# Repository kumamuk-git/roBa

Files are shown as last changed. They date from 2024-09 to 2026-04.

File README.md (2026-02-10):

# roBa
roBaは[keyball](https://github.com/Yowkees/keyball/)に影響を受けたワイヤレスキーボードです  

特徴:
+ ZMK firmwareによるbluetooth(BLE)対応
+ 分割カラムスタッガード配列(キー数:42)
+ トラックボール搭載
+ 水平ロータリーエンコーダ搭載（v1: evqwgd001, v2以降: [CKW12](https://github.com/kumamuk-git/CKW12/tree/main)）

## Where to Buy

[BOOTH](https://kumamuk.booth.pm/)にて組み立てキットが購入可能

## Build Guide

ビルドガイドは[こちら](https://github.com/kumamuk-git/roBa/blob/main/doc/v3/buildguide_v3.md)

## Firmware

ファームウェアのリポジトリは[こちら](https://github.com/kumamuk-git/zmk-config-roBa)  
デフォルトでは以下のように設定されています
+ オートマウスレイヤー：4
+ スクロールレイヤー：5  
+ CPI：400

ファームウェア、キーマップの編集手順は[こちら](https://github.com/kumamuk-git/roBa/blob/main/doc/v3/buildguide_v3.md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)  
（ZMK STUDIOでもキーマップ編集可能）

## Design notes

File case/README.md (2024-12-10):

trackballcase.stl was Created by modifying [Keyball Trackball Case](https://www.thingiverse.com/thing:6215791) (© [kepeo](https://www.thingiverse.com/kepeo/designs) ([Licensed under CC BY 4.0](https://creativecommons.org/licenses/by/4.0/)）)

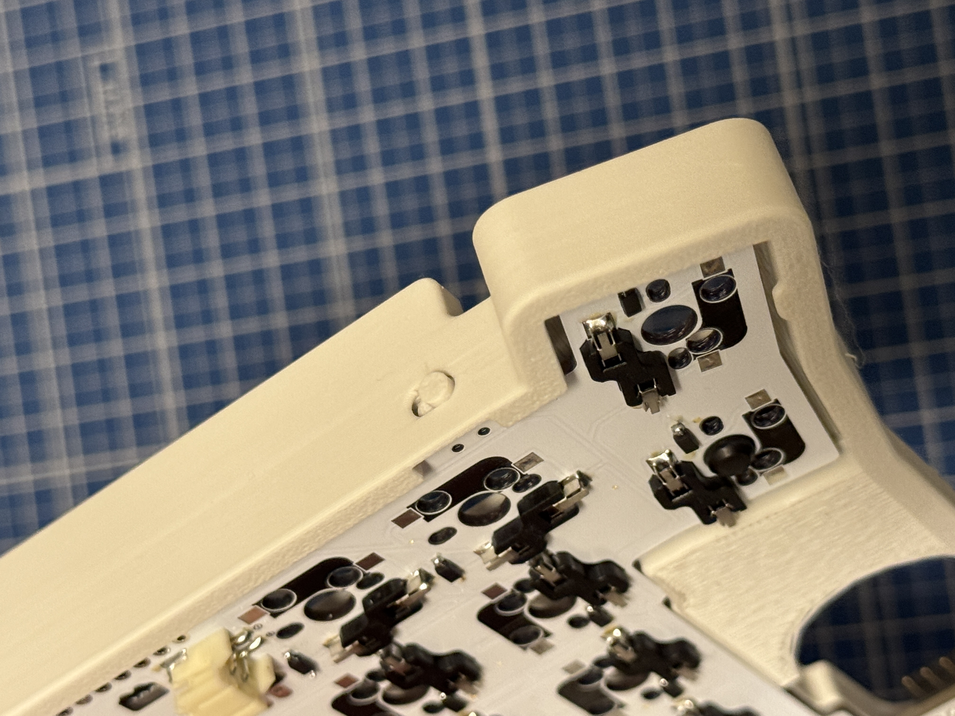
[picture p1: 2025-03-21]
doc/img/cover_v3_2.JPG

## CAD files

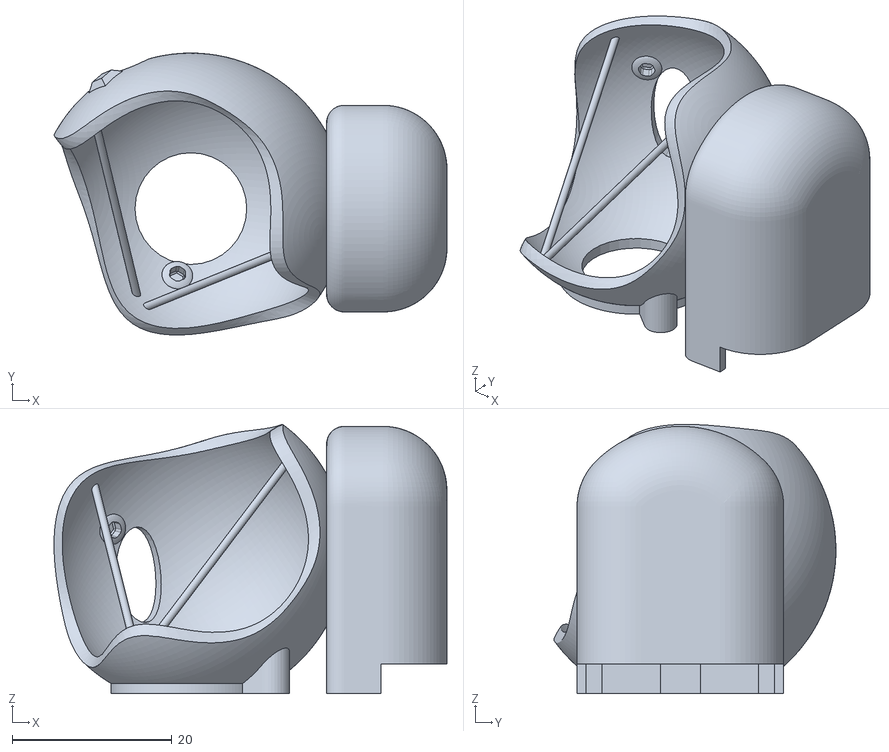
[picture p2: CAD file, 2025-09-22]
case/trackballcase_JLC3DP.stl
49.3 x 35.3 x 33.7

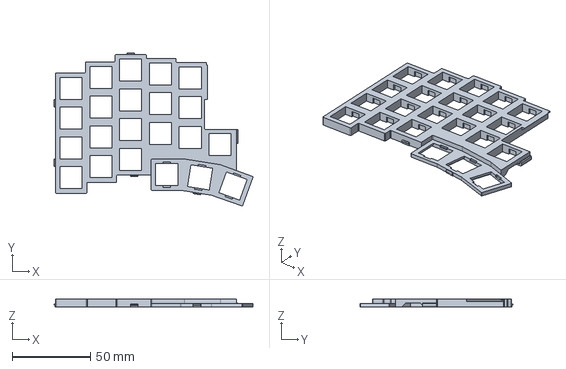
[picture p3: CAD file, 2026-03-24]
case/v3.1/top_L_plate.stp
127.4 x 97.8 x 5.00 mm

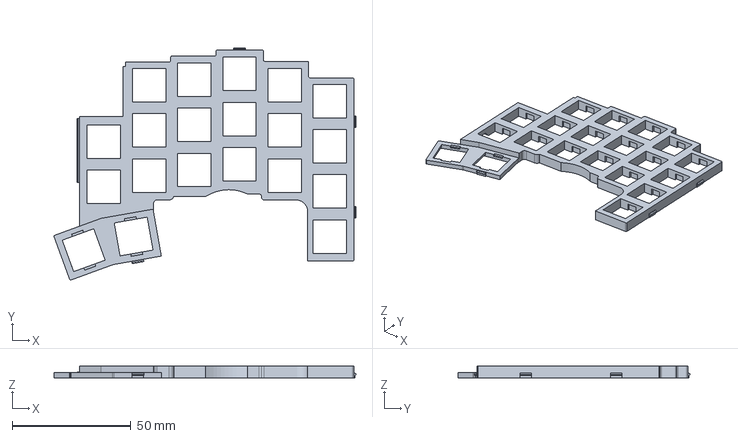
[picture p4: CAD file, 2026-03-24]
case/v3.1/top_R_plate.stp
127.3 x 97.8 x 5.00 mm

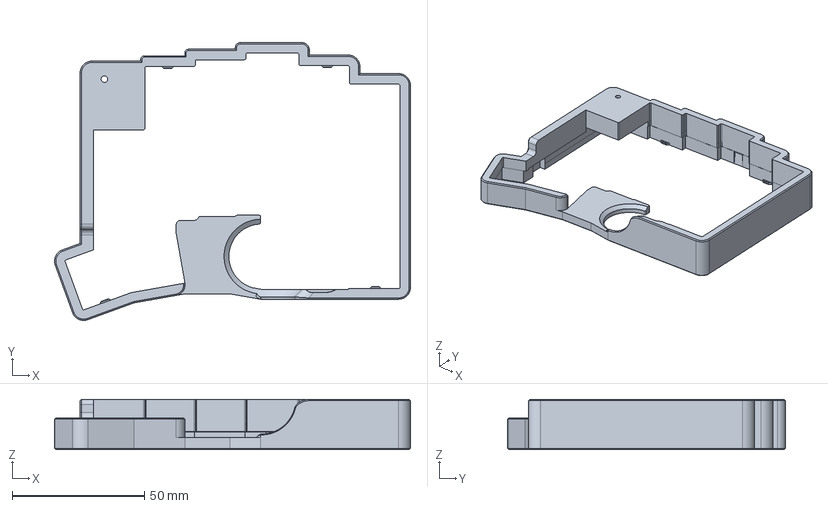
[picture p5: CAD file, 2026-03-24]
case/v3.1/top_R_frame.stp
134.4 x 104.9 x 19.0 mm

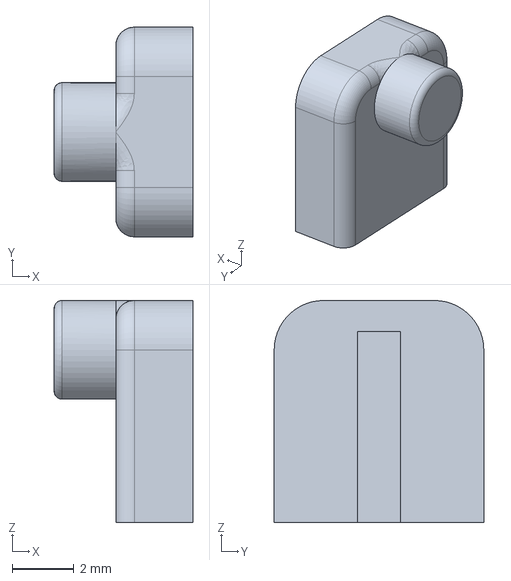
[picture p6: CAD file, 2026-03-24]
case/v3.1/power_sw_fix.stp
4.50 x 6.80 x 7.20 mm

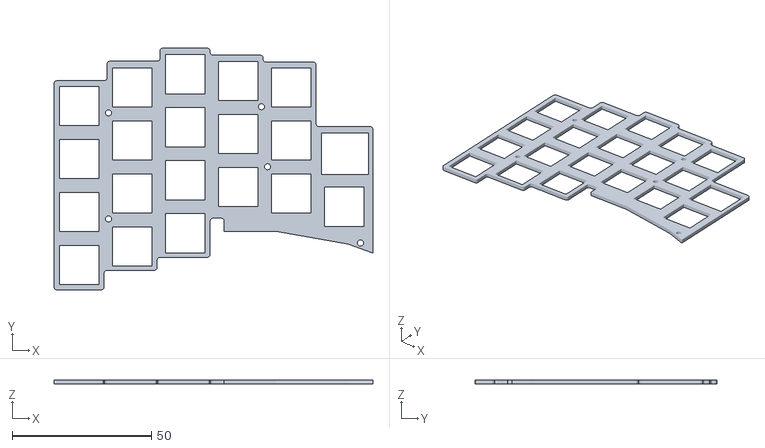
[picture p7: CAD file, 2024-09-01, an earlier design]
case/_old/top_L_main.stl
114.7 x 86.9 x 1.60

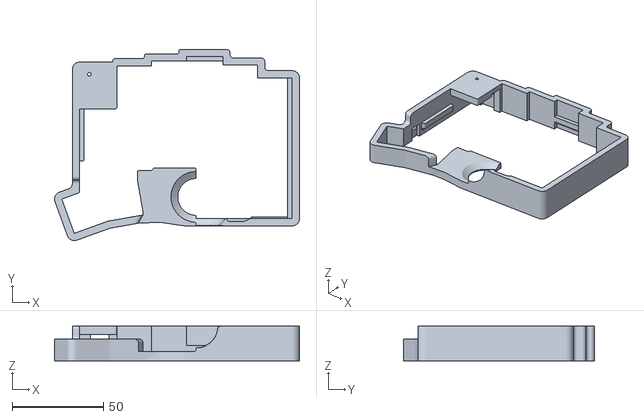
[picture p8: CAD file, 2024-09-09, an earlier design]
case/v1/roba_case_main_R.stl
134.5 x 105.0 x 19.1

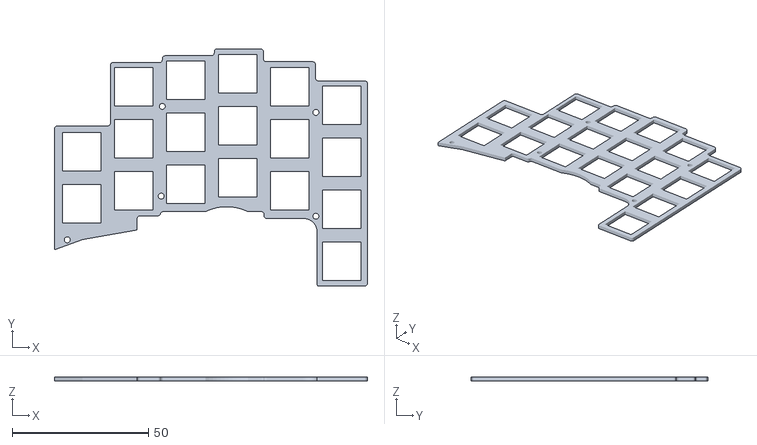
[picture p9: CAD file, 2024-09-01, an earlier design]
case/_old/top_R_main.stl
114.7 x 86.9 x 1.60

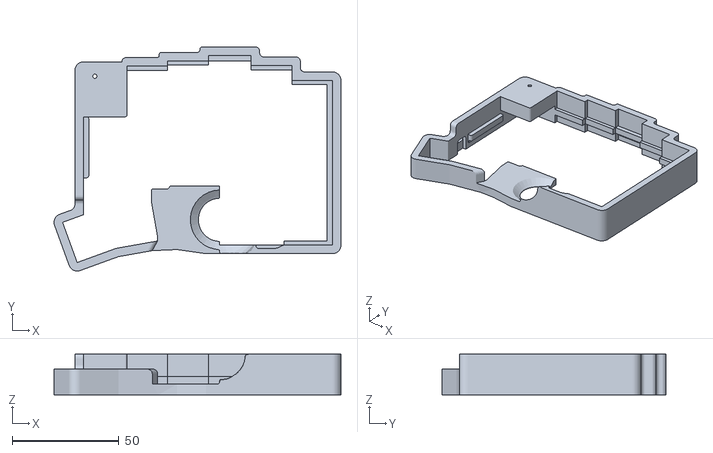
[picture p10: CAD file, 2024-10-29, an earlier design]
case/v2/main_R_v2.stl
134.5 x 105.0 x 19.1

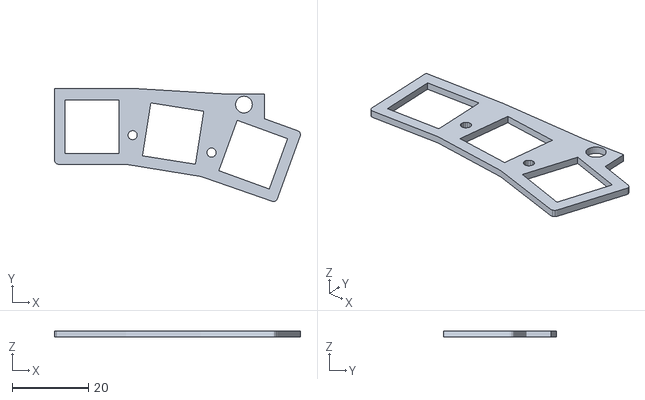
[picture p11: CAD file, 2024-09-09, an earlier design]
case/v1/roba_case_top_thumb_L.stl
64.7 x 29.7 x 1.58

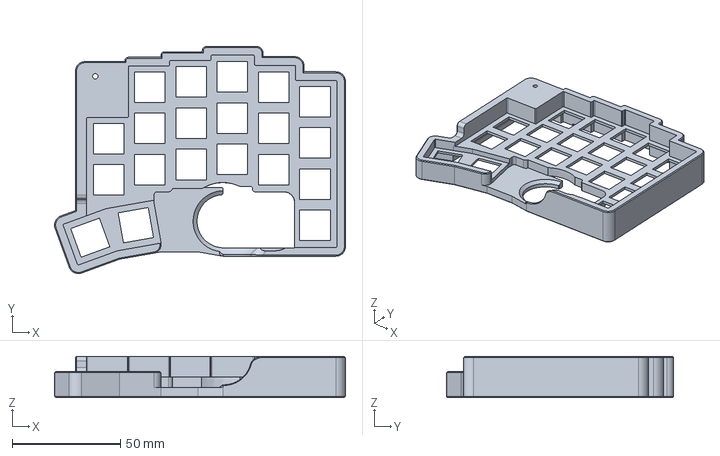
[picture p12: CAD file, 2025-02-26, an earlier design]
case/v2.1/top_R.stp
134.4 x 104.9 x 19.0 mm

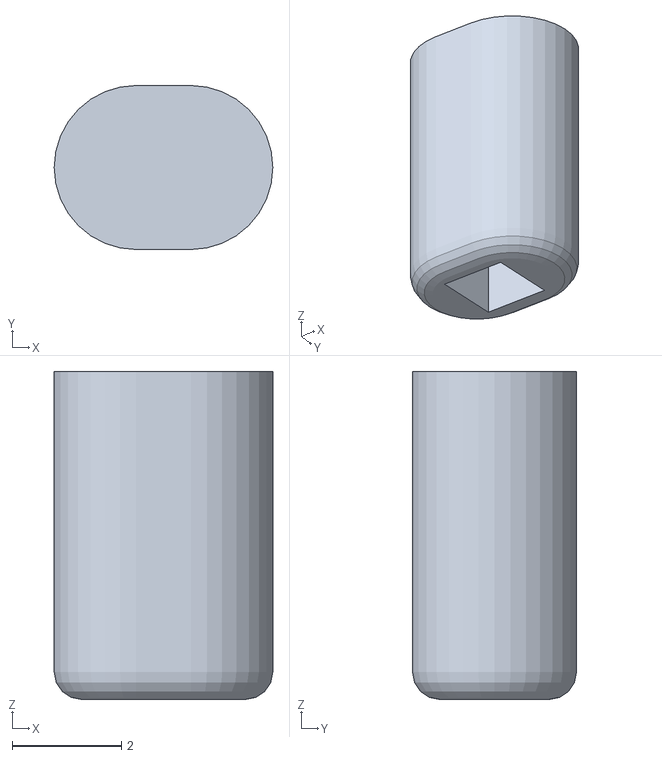
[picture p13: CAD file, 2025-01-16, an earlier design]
case/v2/power_sw_wide.stl
4.00 x 3.00 x 6.00

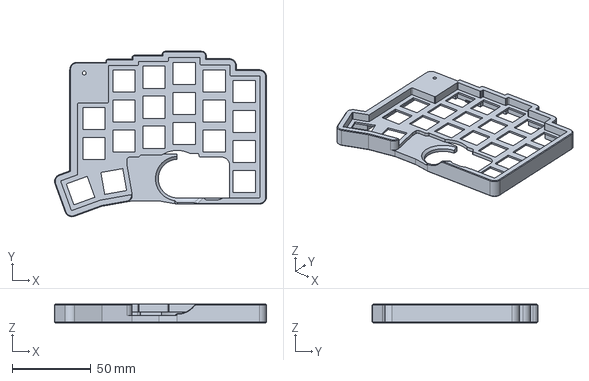
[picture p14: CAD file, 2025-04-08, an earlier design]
case/v3/forLP/top_R_LP.stp
134.4 x 104.9 x 12.0 mm

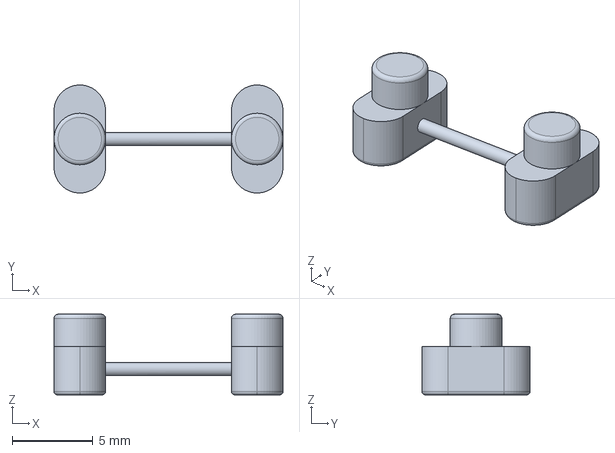
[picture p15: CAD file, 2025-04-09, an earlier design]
case/v3/power_sw_JLC3DP.stp
14.2 x 6.70 x 5.00 mm

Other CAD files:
case/trackballcase.stl
case/v3.1/top_L_frame.stp
case/v2/main_l_v2.stl
case/v1/roba_case_main_L.stl
case/_old/my_case_L_bottom.stl
case/_old/my_case_L_v5.stl
case/_old/my_case_R_bottom_v3.stl
case/_old/my_case_R_v9.stl
case/_old/power_switch.stl
case/_old/reset_stick.stl
case/_old/top_L_sum.stl
case/_old/top_R_sum.stl
case/v1/power_sw.stl
case/v1/reset_stick.stl
case/v1/roba_case_bottom_L.stl
case/v1/roba_case_bottom_R.stl
case/v1/roba_case_top_L.stl
case/v1/roba_case_top_thumb_R.stl
case/v2.1/bottom_R.stp
case/v2.1/botttom_L.stp
case/v2.1/power_sw.stp
case/v2.1/top_L.stp
case/v2/bottom_L_v2.stl
case/v2/bottom_R_v2.stl
case/v2/power_sw.stl
case/v2/reset_stick_v2.stl
case/v2/roba_case_top_thumb_R.stl
case/v2/top_L_v2.stl
case/v2/top_R.stl
case/v3/bottom_L.stp
case/v3/bottom_R.stp
case/v3/forLP/reset_stick_LP.stp
case/v3/forLP/reset_stick_LP_JLC3DP.stp
case/v3/forLP/top_L_LP.stp
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

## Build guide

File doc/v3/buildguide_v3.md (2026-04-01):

# Build Guide for roBa

2025/3販売分～

## 目次
  - [1．部品確認](#1部品確認)
    - [1-1．キット内容](#1-1キット内容)
    - [1-2．別途準備が必要な部品](#1-2別途準備が必要な部品)
    - [1-3．オプション](#1-3オプション)
  - [2．準備](#2準備)
    - [2-1．必要な工具](#2-1必要な工具)
    - [2-2．ファームウェア](#2-2ファームウェア)
  - [3．実装](#3実装)
    - [3-1．ダイオードのはんだ付け](#3-1ダイオードのはんだ付け)
    - [3-2．キーソケットのはんだ付け](#3-2キーソケットのはんだ付け)
    - [3-3．スライドスイッチのはんだ付け](#3-3スライドスイッチのはんだ付け)
    - [3-4．マイコンのはんだ付け](#3-4マイコンのはんだ付け)
    - [3-5．コネクタのはんだ付け](#3-5コネクタのはんだ付け)
    - [3-6．L字コンスルーのはんだ付け](#3-6l字コンスルーのはんだ付け)  
    - [3-7．センサのはんだ付け](#3-7センサのはんだ付け)
    - [3-8．ロータリーエンコーダの組み立て](#3-8ロータリーエンコーダの組み立て)
  - [4．組み立て](#4組み立て)
    - [4-1．バッテリーの確認及び取り付け](#4-1バッテリーの確認及び取り付け)
    - [4-2．ケースの組み立て](#4-2ケースの組み立て)
    - [4-3．トラックボール読み取り基板差し込み](#4-3トラックボール読み取り基板差し込み)
    - [4-4．トラックボールケース装着](#4-4トラックボールケース装着)  
  - [5．ファームウェア書込み](#5ファームウェアの書込み)
    - [5-1．ファームウェア(仮)のダウンロード](#5-1ファームウェア仮のダウンロード)
    - [5-2．ファームウェア(仮)の書込み](#5-2ファームウェア仮の書込み)
    - [5-3．動作確認](#5-3動作確認)
  - [6．キーマップの編集](#6キーマップの編集)
  - [7．トラブルシューティング](#7トラブルシューティング)

## 1．部品確認

### 1-1．キット内容

> [!NOTE]  
> **ケースなし版を購入された方へ**  
> 3Dプリントケースは[github](https://github.com/kumamuk-git/roBa/tree/main/case/v3)上で公開しています
> JLCPCBでの発注方法は[こちら](https://zenn.dev/kumamuk/scraps/ff2f456fd1757d)に簡単にまとめています  
> 部品の厚みが足りないと警告が出る場合がありますが、リスクを許容すると回答することで製造を進めることができます

| 名前 | 数 | 備考 |
|:-|---:|:-|
| メイン基板(左右) | 1組 | |
| ボトムプレート(左右) | 1組 | 3Dプリント品|
| ケース(左右) | 1組 | 3Dプリント品|
| リセットボタン用スティック | 2本 | 3Dプリント品|
| 電源スイッチキャップ | 2本 | 3Dプリント品|
| トラックボールケース | 1個 | 3Dプリント品|
| Φ2 セラミックボール | 3個 | トラックボールケースに取り付け済み |
| トラックボール読取り基板 | 1枚 | |
| トラックボール読取りセンサ | 1個 | PMW3610|
| 読取りセンサ用レンズ | 1個 | |
| L字コンスルーピン(7ピン) | 1個 | |
| PHコネクタ | 2個 | [S2B-PH-SM4-TB](https://akizukidenshi.com/catalog/g/g112810/)|
| スライドスイッチ | 2個 |[MSK12C01](https://www.aitendo.com/product/16631) |
| ダイオード（表面実装タイプ）  | 50個 | 予備含む|
| Kailh PCBソケット CherryMX用  | 40個 ||
| Kailh PCBソケット choc用 | 5個 | |
| ネジ M1.7 | 2本 | |
| クッションゴム | 4個 | |  

---ロータリーエンコーダ---
| 名前 | 数 | 備考 |
|:-|---:|:-|
| ロータリーエンコーダ用ハウジング | 1個 | 3Dプリント品|
| ロータリーエンコーダ用ホイール | 1個 | 3Dプリント品|
| ロータリーエンコーダ用ステム | 1個 | 3Dプリント品|
| ロータリーエンコーダ | 1個 | EC05E1220202|
| ロータリーエンコーダ基板 | 1個 | |
| スペーサー M2 3mm | 4本 | |
| ネジ M2 8mm | 4本 |  |
| スプリングピン(ポゴピン) | 1本 | |
| コンスルーピン(3ピン) | 2個 |うち1つは中央のピンが不必要のため取り外しています |

### 1-2．別途準備が必要な部品

| 名前 | 数 | 備考 |参考情報|
|:-|-:|:-|:-|
| Xiao nrf52840 | 2個 |  |[主な購入先](https://akizukidenshi.com/catalog/g/g117341/)|
| CherryMX互換キースイッチ | 37個  |  |
| ロープロファイルキースイッチ  | 5個 |  |
| 直径34mmトラックボール | 1個 |  |[主な購入先](https://www.amazon.co.jp/%E3%81%BA%E3%83%AA%E3%83%83%E3%82%AF%E3%82%B9-PERIPRO-303WH-%E4%BA%A4%E6%8F%9B%E7%94%A8%E3%83%88%E3%83%A9%E3%83%83%E3%82%AF%E3%83%9C%E3%83%B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)|
| Lipoバッテリー(コネクタ付き)  | 2個 | ボトムプレートはL53mm × W23mm × H6mm 以内の大きさに対応 キット付属のコネクタは2mmピッチのJSTコネクタになります。必ず保護回路付きのものを用意してください。|[主な購入先](https://www.amazon.co.jp/dp/B09DPNZM31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)|
| USB type-Cケーブル | 1本 | ファームウェア書込みと充電に必要 |
| キーキャップ | 37個  | 1u 37個 |
| ロープロファイルキーキャップ  | 5個 | 1u ５個 |
| 両面テープ | - | ボトムプレートへのバッテリーの固定に必要|

※リポバッテリーには発火等の危険性があります。各自購入したバッテリーの注意事項をよく読み、適切に取り扱うよう注意してください。  
　取り扱いの不備により発生した事故等の責任は負いかねます。  
※主な購入先のリンクはアフェリエイトリンクではありません。

### 1-3．オプション
+ ロータリーエンコーダ部分にキーソケットを取り付けキースイッチを取り付けることも可能です。

## 2．準備

### 2-1．必要な工具
| 名前 | 備考 |
|:-|:-|
| はんだごて  | 温度調整可能だと◎|
| はんだ | |
| ピンセット  | |
| ドライバ ||
| マスキングテープ||
| テスター||
| ペンチ||

※はんだ付けに不慣れな場合は[こちらの練習基板](https://shop.talpkeyboard.com/products/xiao-practice-board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)でマイコンのはんだ付けを練習してから挑むと良いかと思います。

### 2-2．ファームウェア
Xiao nrf52840へファームウェアの書込みが必要です。  
ビルド済みのファームウェアは[こちら](https://github.com/kumamuk-git/zmk-config-roBa/actions/runs/10759328125)です。  
zmk firmwareを使用しているため、ご自身でファームウェアやキーマップをカスタムされる場合はgithubアカウントが必要になります。  

## 3．実装

### 3-1．ダイオードのはんだ付け
ダイオードは基板裏面（roBaロゴがない面）に実装します。ダイオードは実装の向きがあります。  
ダイオードに薄く書かれている線と基板に印刷された図（以降シルク）にある線が同じ方向になるように取り付けて下さい。  

ダイオード用パッドの片側にはんだを盛ります。  

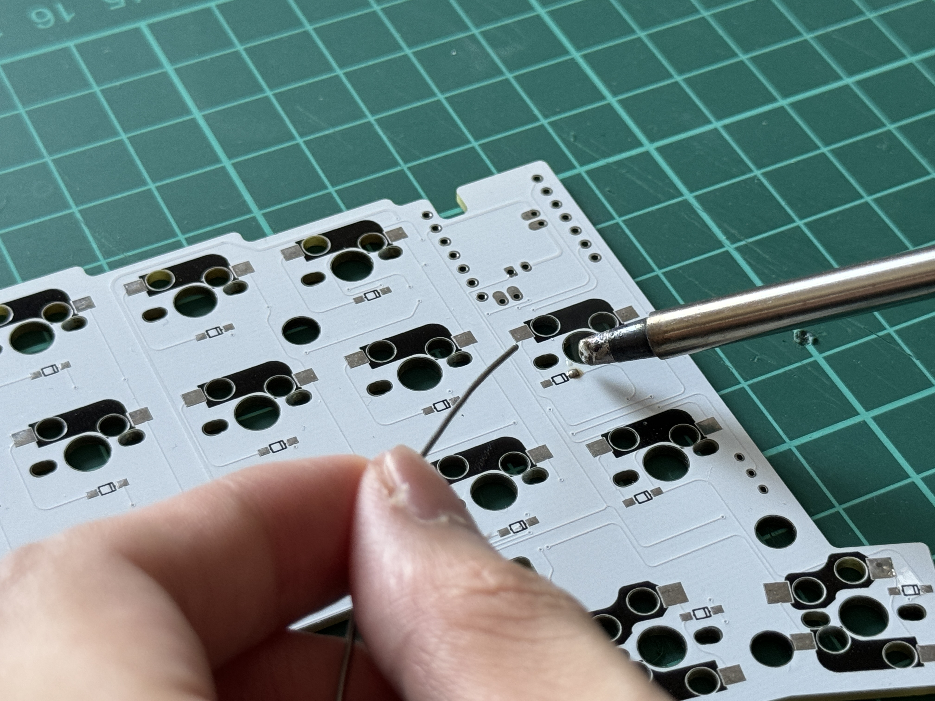
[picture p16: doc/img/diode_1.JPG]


そしてピンセットでダイオードを掴み、シルクと向きを合わせて事前に盛ったはんだを溶かしつつ位置を合わせます。 

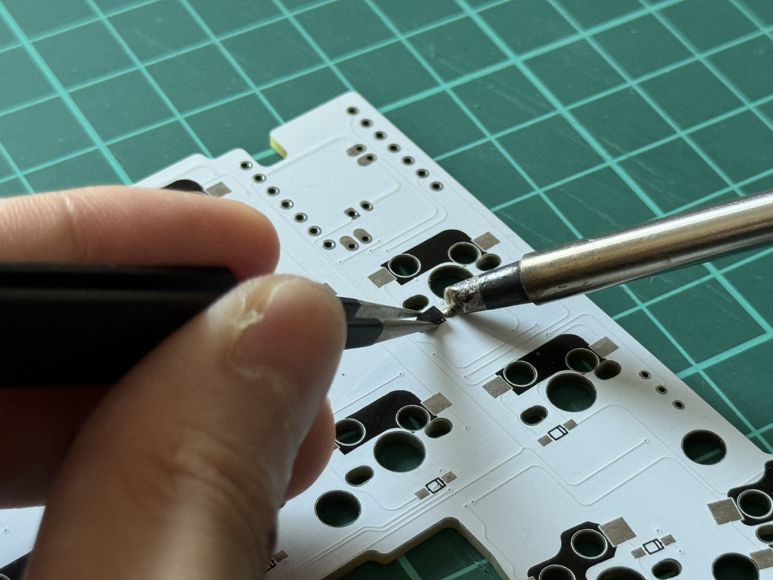
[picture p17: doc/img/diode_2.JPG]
 

およそシルクと同じ位置に決まったら、もう片側もはんだで固定します。

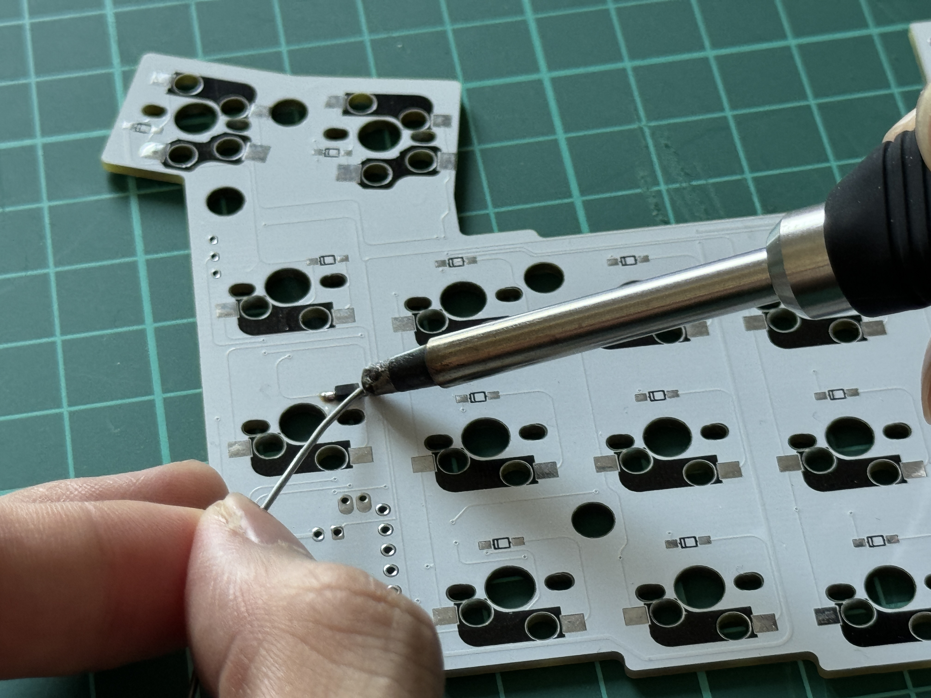
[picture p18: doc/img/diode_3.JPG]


ピンセットでダイオードが取れないことを確認したら取り付け完了です。  
これをすべて(43箇所)に対して行います。

### 3-2．キーソケットのはんだ付け  
キーソケットも基板裏面に実装します。  
親指部分はchoc用のキーソケットを使用してください。  
ダイオードと同様に片方のパッドに事前にはんだを盛ります。  

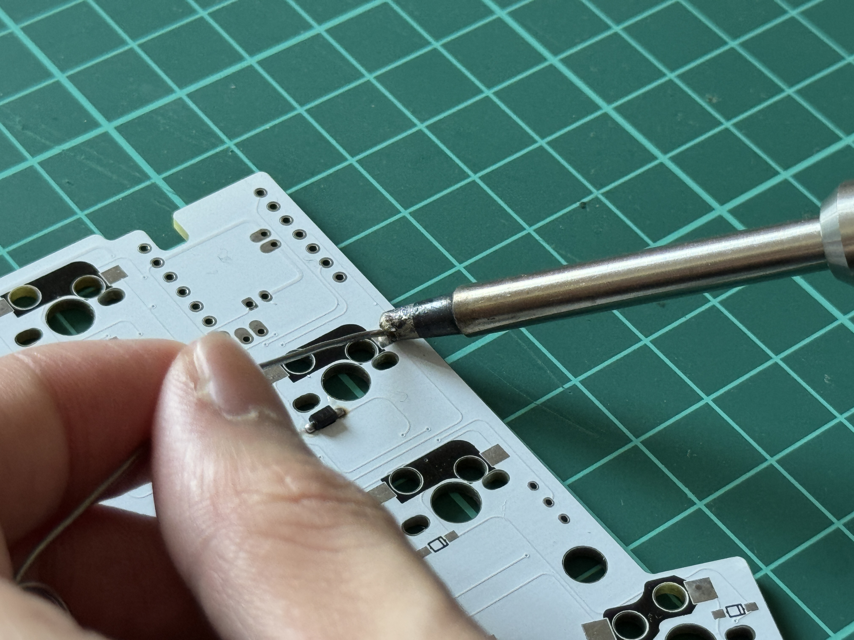
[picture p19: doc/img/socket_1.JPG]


そして、キーソケットをシルクに合う向きで基板にはめ込みます。  
その状態のまま、キーソケットをピンセットで抑えつつ、事前に盛ったはんだを溶かすとキーソケットが沈み、固定できます。  

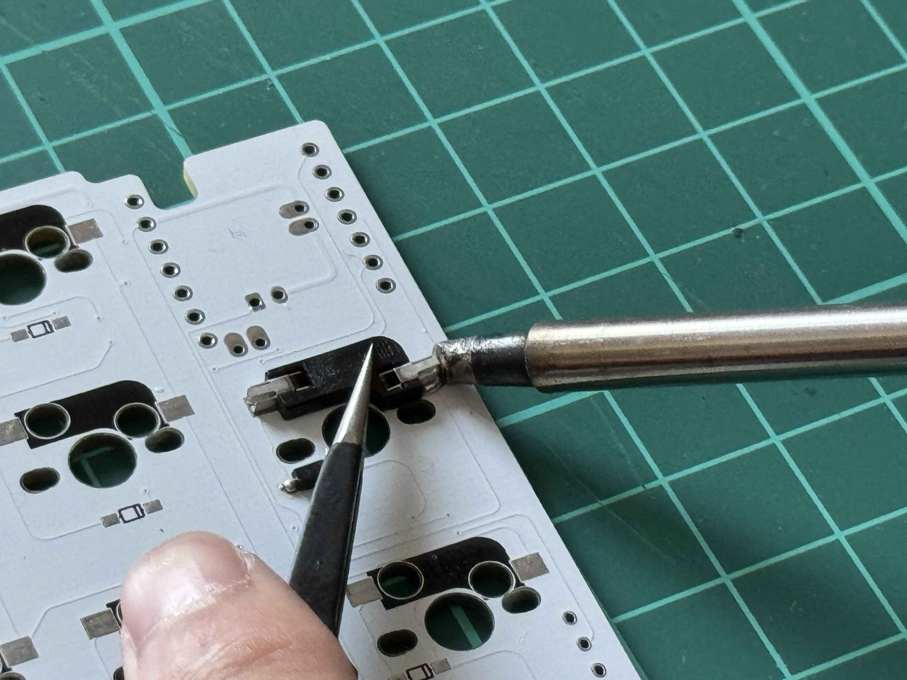
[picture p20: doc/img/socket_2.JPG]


固定出来たら、反対側のパッドもはんだで固定します。  

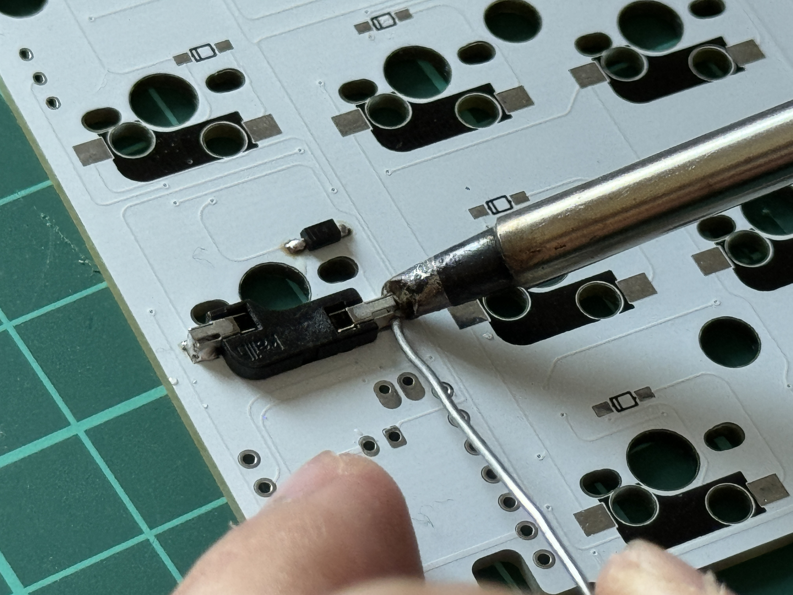
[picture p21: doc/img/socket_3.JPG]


<!--
写真  (ロータリーエンコーダ取り付け部分のソケット)
-->

### 3-3．スライドスイッチのはんだ付け  
このスライドスイッチが電源スイッチとなります。  
スライドスイッチは基板表面に実装します。  

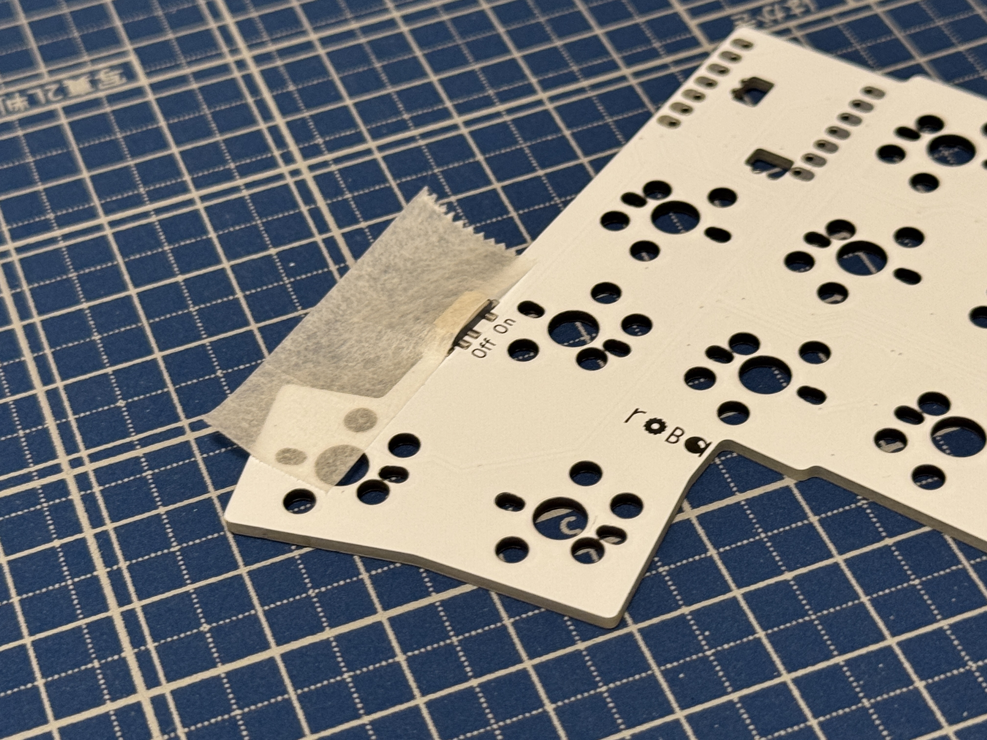
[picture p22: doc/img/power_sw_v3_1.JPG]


はんだのランドとスイッチの足が合うように基板上に配置し、マスキングで仮止めします。   
（この写真はんだ汚いっすね、、、） 

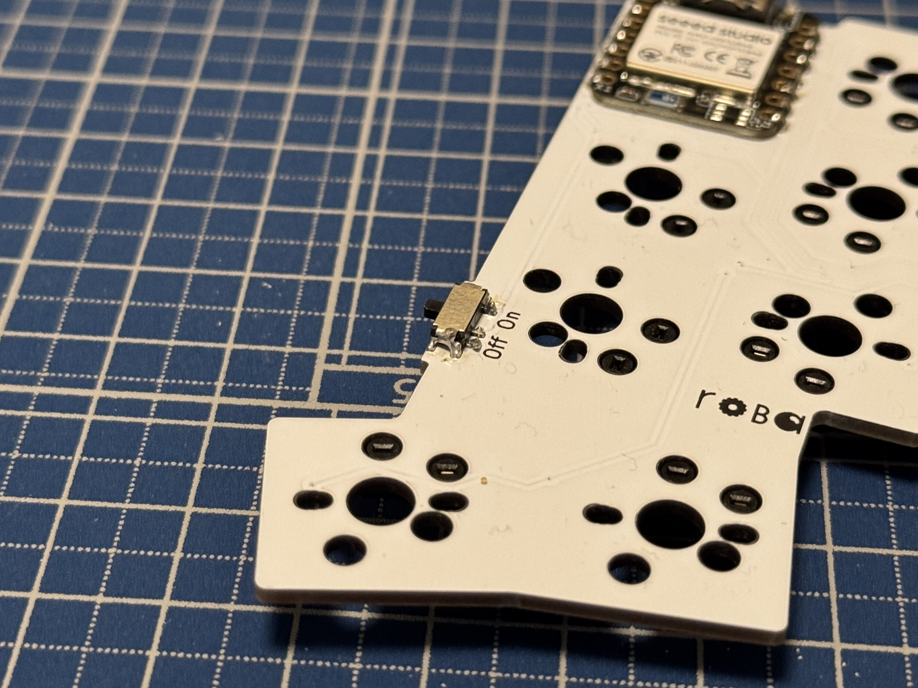
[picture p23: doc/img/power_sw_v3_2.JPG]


そしてはんだ付けし、固定します。  

### 3-4．マイコンのはんだ付け  

v2から基板に直付けになりました。
まずxiao bleを基板の表に重ねます。  
その後、xiao ble付属のピンヘッダをその上から差し込み、xiao bleが基板に対してずれないように固定します。  
(ピンヘッダははんだ付けしないので気をつけてください。)      
現行のバージョンだともう少し穴が広くなりはんだしやすくなっています。

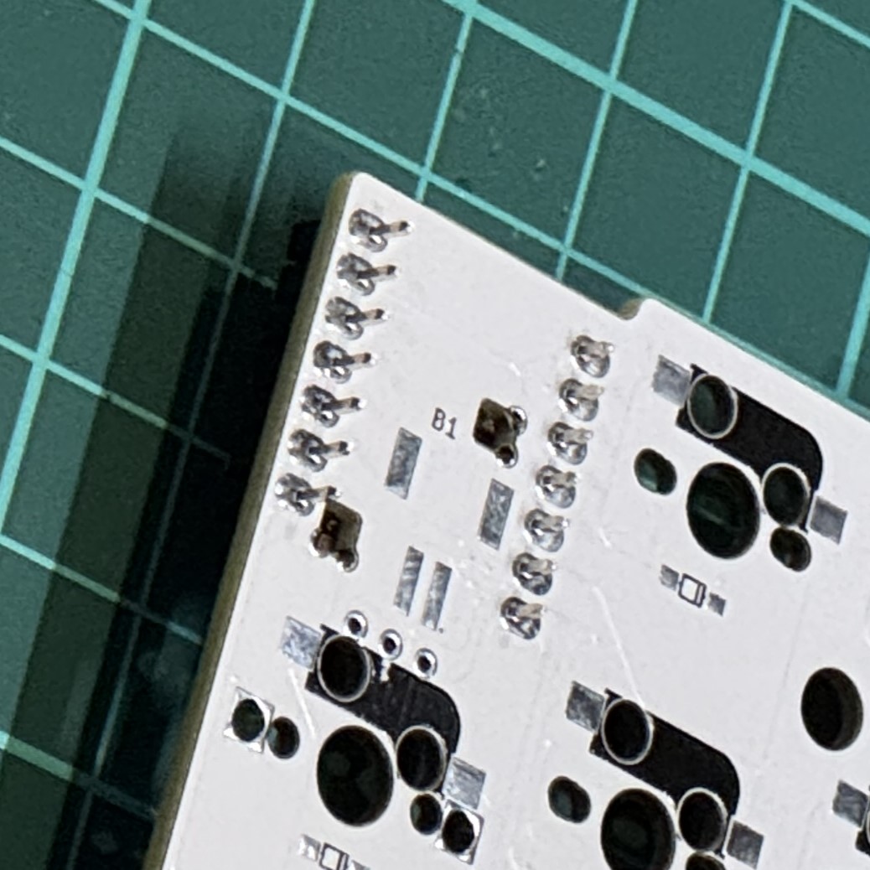
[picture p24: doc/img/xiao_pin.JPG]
    

その状態で、切り欠きの入ったスルーホールがxiao bleの裏面のパッドと重なっていることを確認し、はんだで各パッドとスルーホールを繋ぎます。  
製造の都合上でスルーホールの切り欠き部分が残ってしまっている場合がありますが、無理に取らずにそのままはんだ付けしてください。
無理に取ると断線の可能性があります。（テスト組みでやりました。）  
写真では太い小手先で作業してしまっているのですが、絶対に細い小手先での作業のほうが楽です。  
もしブリッジしてしまった場合ははんだ吸い取り線をスルーホール同士の間に当てたら比較的簡単にジャンパ外れるようです。  
私も一度ブリッジしてしまったのですが、手元に吸い取り線がなかったため、スルーホールに小手先を当てながら基板を逆さにして重力で小手先側へはんだを流し込むというプリミティブ解決をしましたが、危ないので非推奨です。  

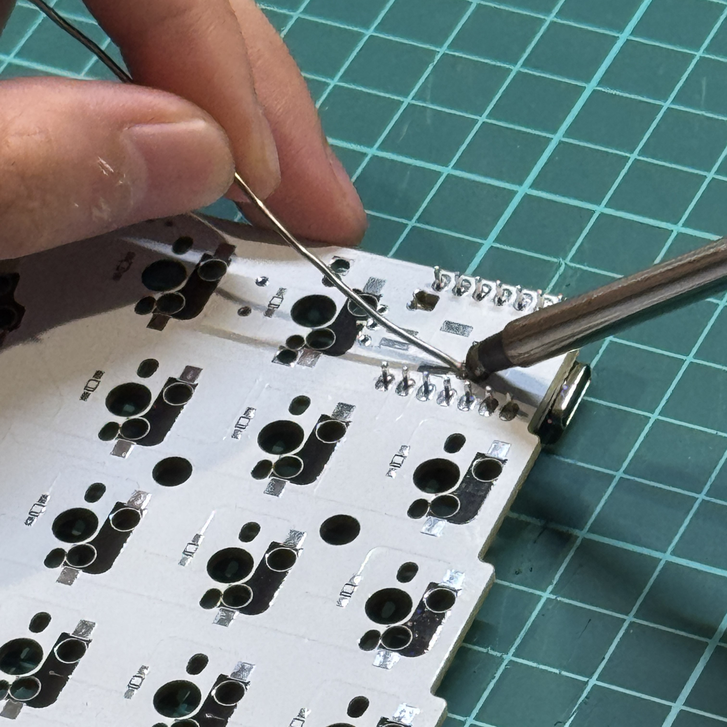
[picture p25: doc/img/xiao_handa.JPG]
  
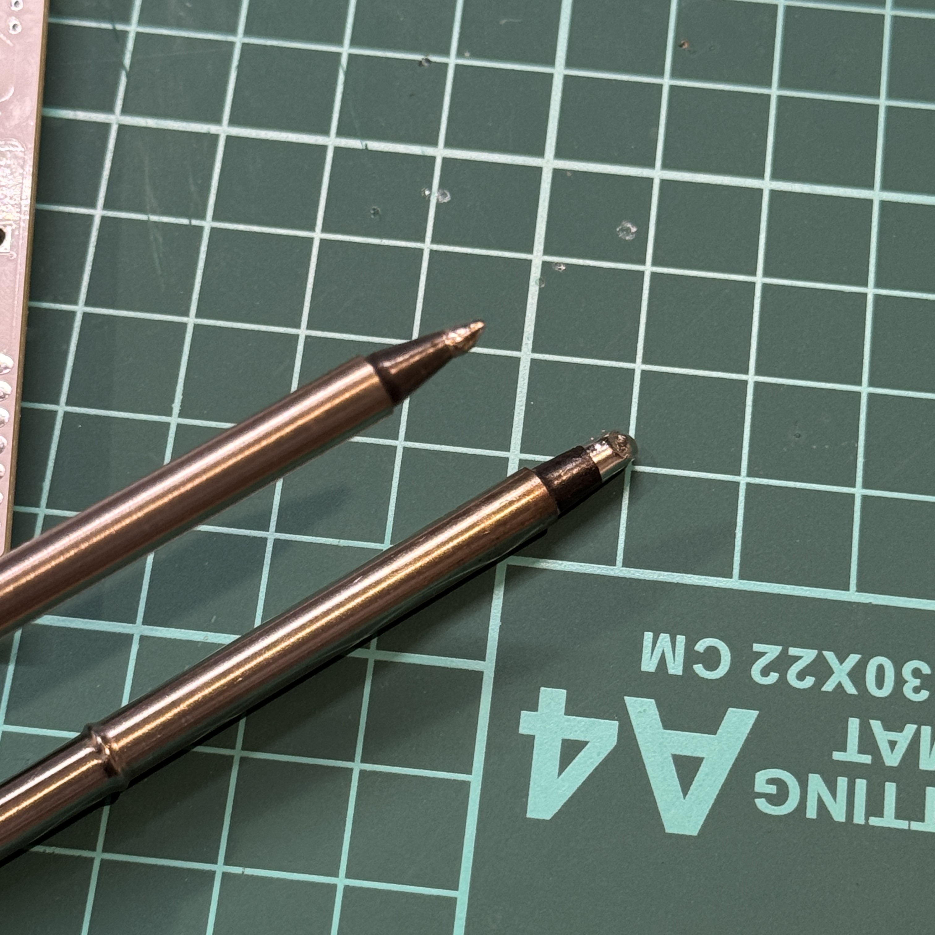
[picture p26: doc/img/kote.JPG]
  

適切にはんだ付けできるとこんな感じになります。

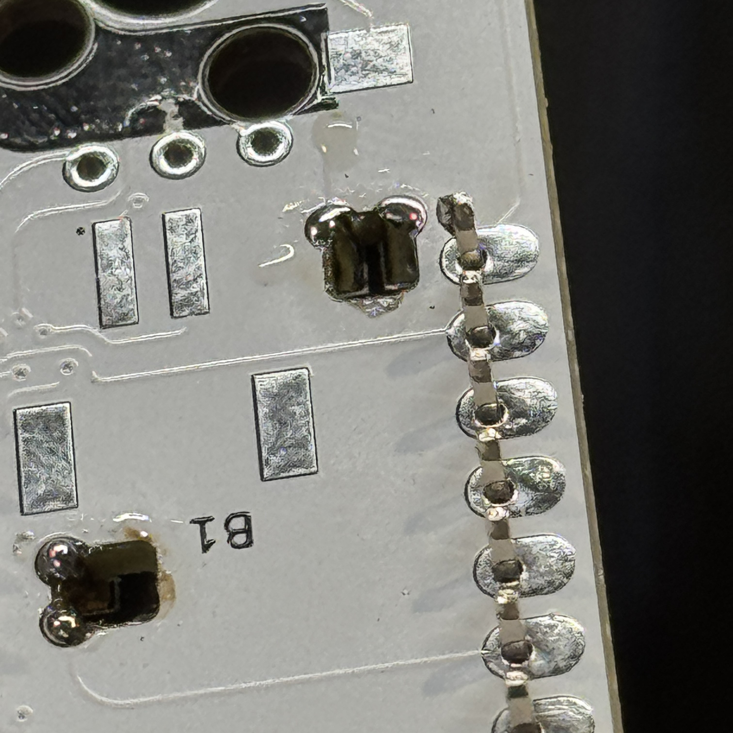
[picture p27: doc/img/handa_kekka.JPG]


2箇所とも裏面がはんだ出来たらピンヘッダは外してOKです。
続いて表面にし、写真のようにxiaoの各端子の側面と基板のパッドをはんだ付けします。

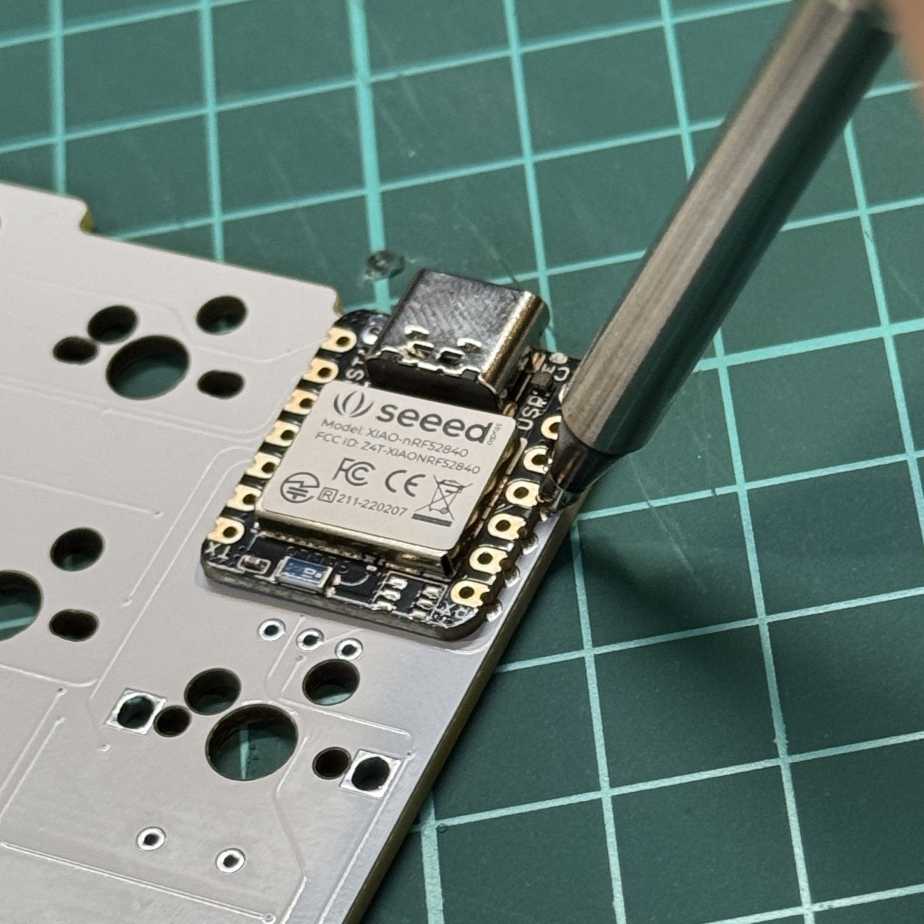
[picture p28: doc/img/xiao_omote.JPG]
  

以上でマイコンの取り付け完了です。  

### 3-5．コネクタのはんだ付け  

コネクタは裏面に実装します。  

2本生えている足と側面をはんだ付けで固定します。  
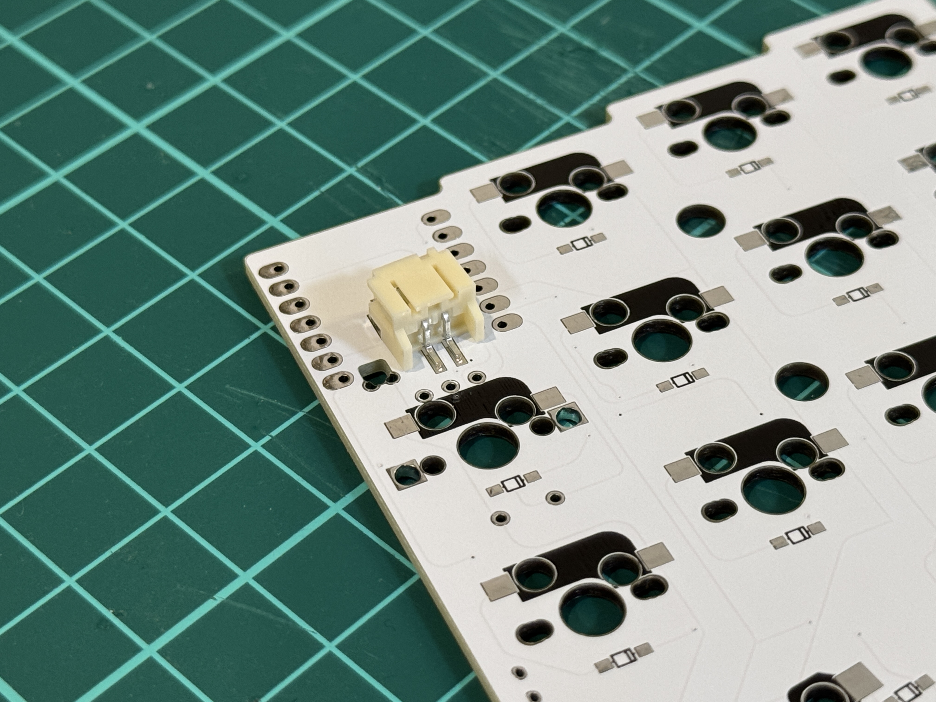
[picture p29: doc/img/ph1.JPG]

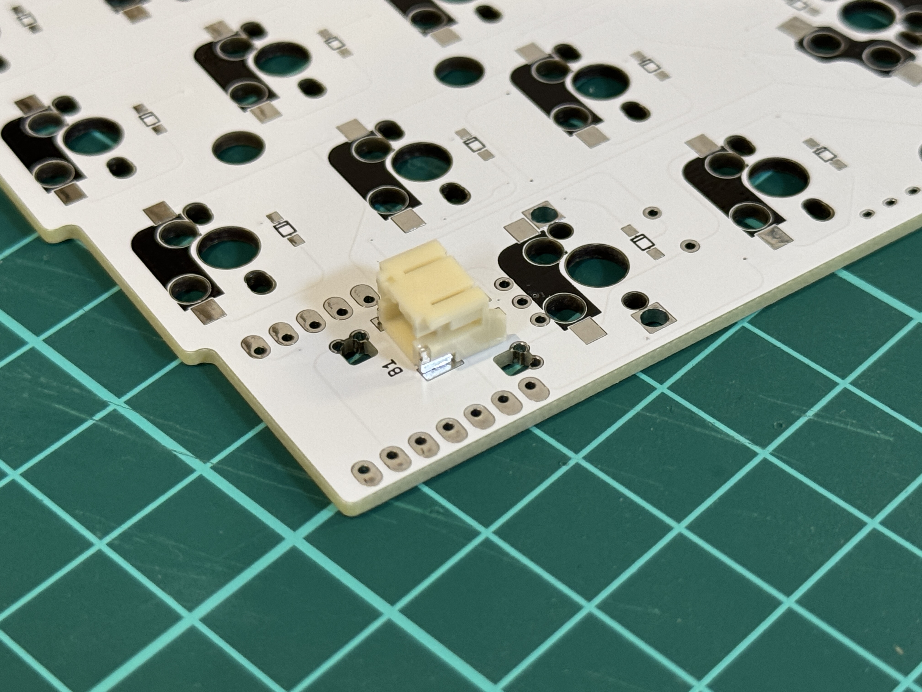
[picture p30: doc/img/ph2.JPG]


左右各1箇所、計2箇所取り付けます。

### 3-6．L字コンスルーのはんだ付け  

トラックボール読み取り基板を取り付けるためのコンスルーです。  
コンスルーには輪っかになっているピンと1本の直線のピンがありますが、直線のピンのほうを基板へ取り付けます。  
コンスルーは基板表面に実装します。  
表面から差し込み、マスキングテープで仮止めします。

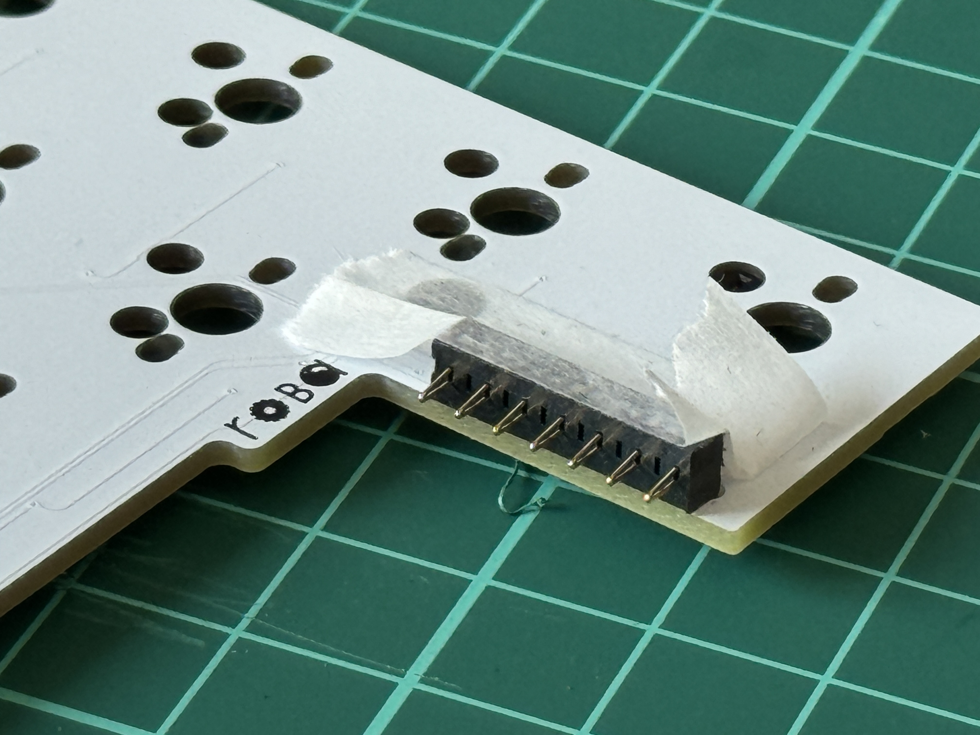
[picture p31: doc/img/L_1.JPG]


そして、裏面からはんだで固定します。  

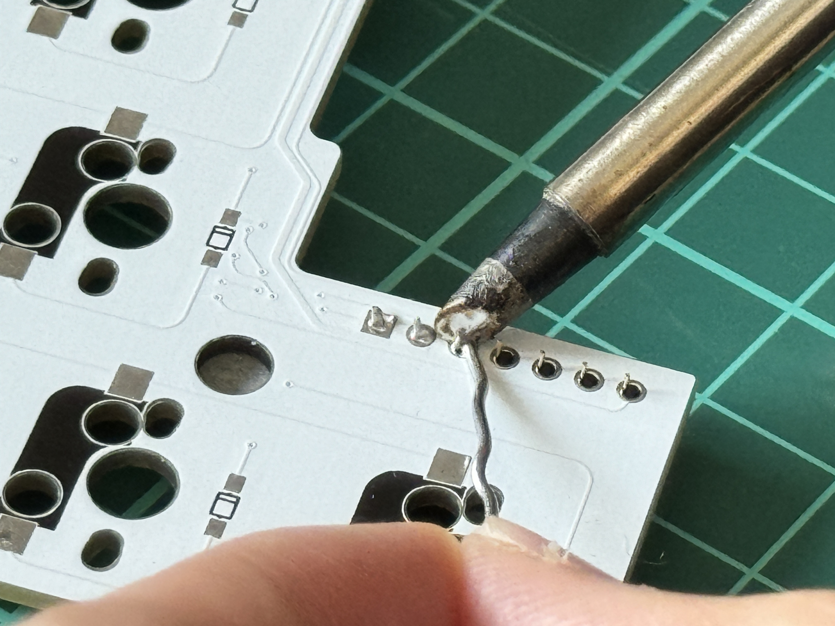
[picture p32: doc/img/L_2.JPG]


トラックボール取り付け側の基板のみ1箇所です。  

### 3-7．センサのはんだ付け  

トラックボール読み取り基板へセンサをはんだ付けします。  
「pmw3610 module」の文字がある面を表面とし、裏面からセンサを差し込みます。  
このとき、向きを間違えないよう写真をよく確認してください。  
裏面に書かれた文字とセンサに書かれた文字の上下が揃っている向きが正しい向きです。 

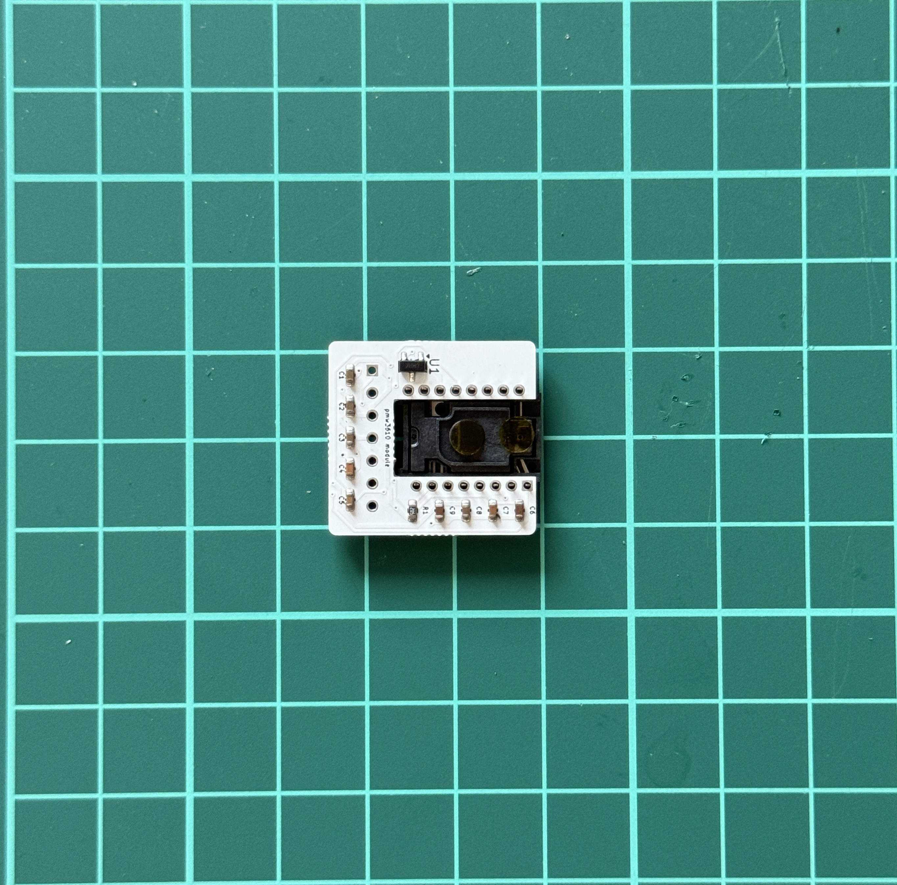
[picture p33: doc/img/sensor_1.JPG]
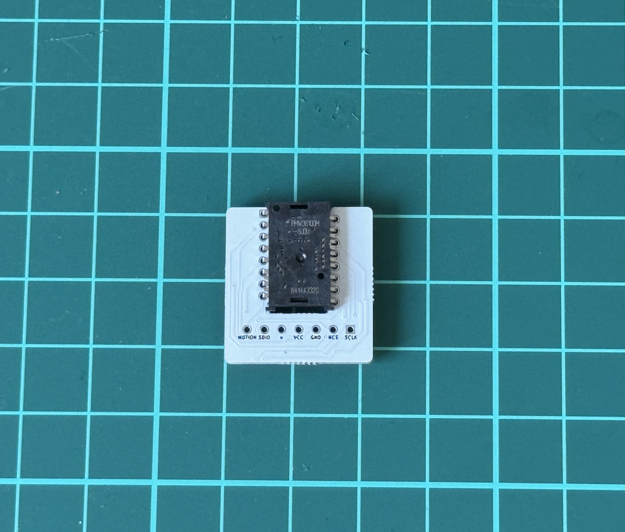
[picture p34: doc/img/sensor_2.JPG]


そして、表面に出たセンサのピンをすべてはんだ付けしていきます。  
センサのデータシートによると**最大260℃**までの温度、**7秒以内**でのはんだづけが推奨されています。  
これ以上高い温度または長時間での作業はセンサの故障につながる恐れがありますので注意してください。  
とはいえ焦って作業するのも良くないので適度に冷ましつつ落ち着いて作業してください。

+ ランドの面積が小さいので、はんだを盛りすぎてピンがブリッジしてしまわないように注意してください。  
個人的に手前のピンから順にはんだ付けしていくほうが失敗がなさそうです。

+ また、はんだ不良によりセンサが動作しない場合もありますので、  
センサが動作しない場合は、まず、この部分のはんだに不良がないか確認するとよいです。  
基板の接続は以下のようになっていますので参考にしてください。

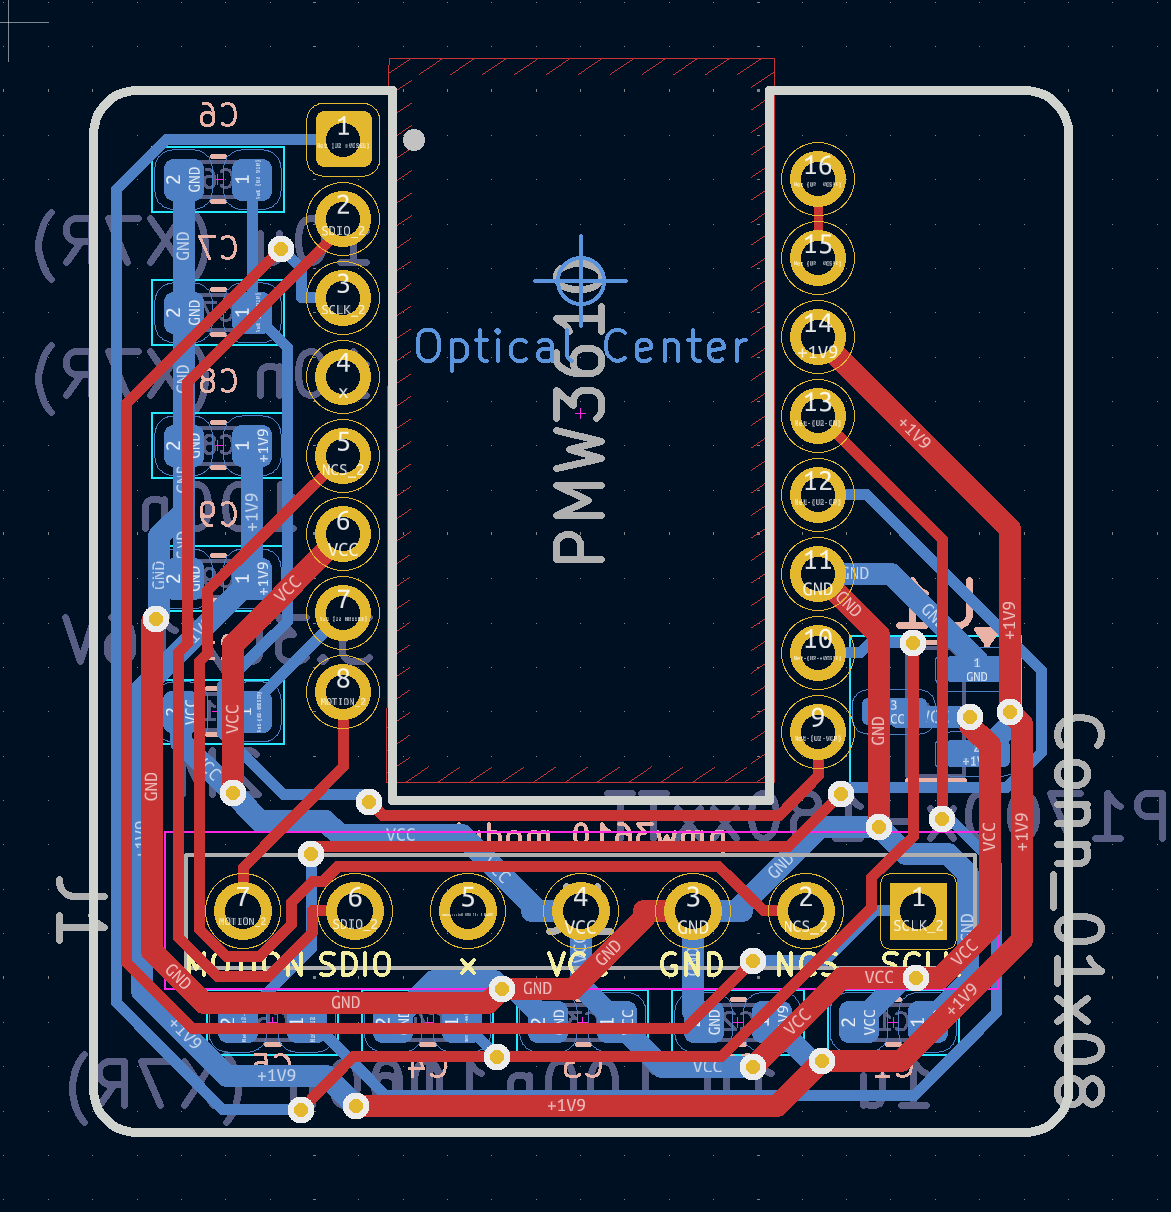
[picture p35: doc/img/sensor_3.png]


はんだづけが完了したら保護シールをはがしてください。

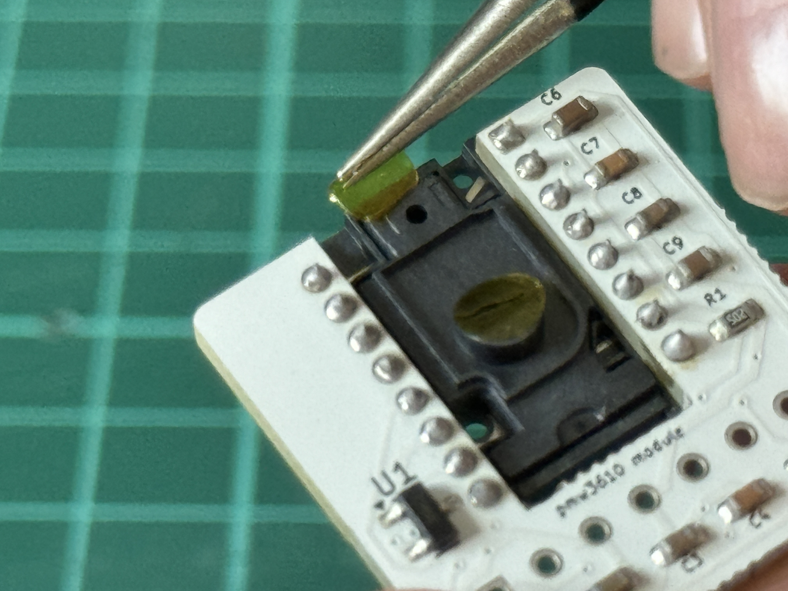
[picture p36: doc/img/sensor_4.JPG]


センサの取り付けが完了したら、レンズを装着してください。 

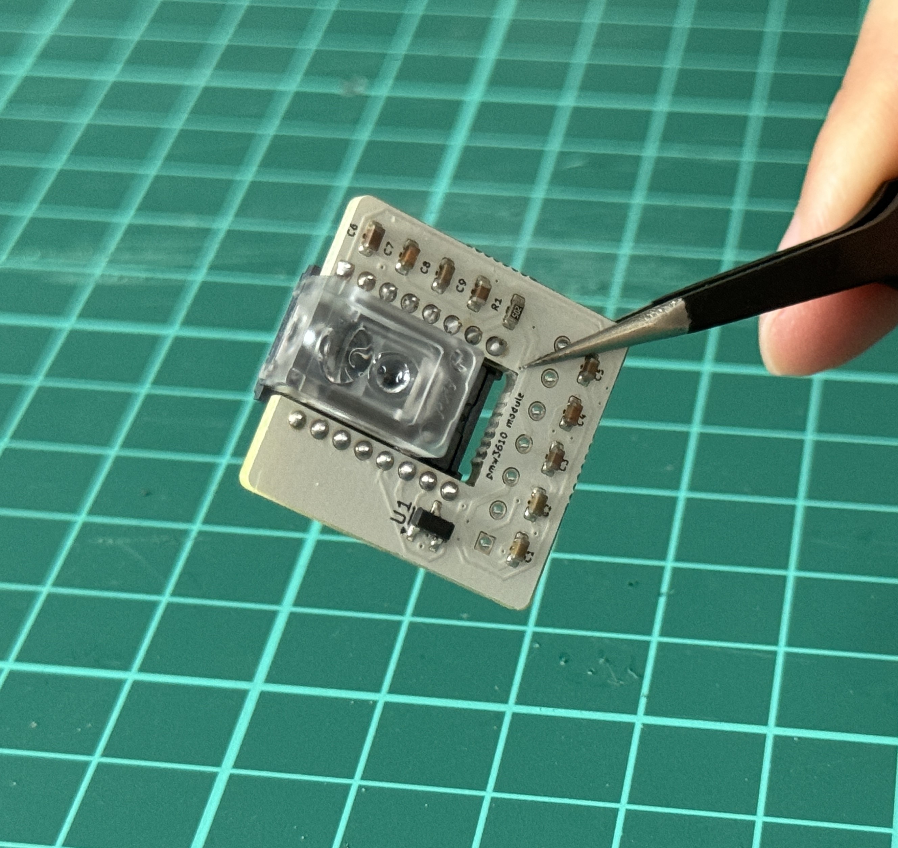
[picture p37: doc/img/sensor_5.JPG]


### 3-8．ロータリーエンコーダの組み立て  
> [!TIP]  
> ロータリーエンコーダはロープロファイル仕様にも変更可能です。  
> [こちら](https://github.com/kumamuk-git/CKW12/blob/main/doc/buildguide.md)ご参照ください

以前採用していた水平ロータリーエンコーダの入手性が悪すぎたので、いい感じのを作りました。  
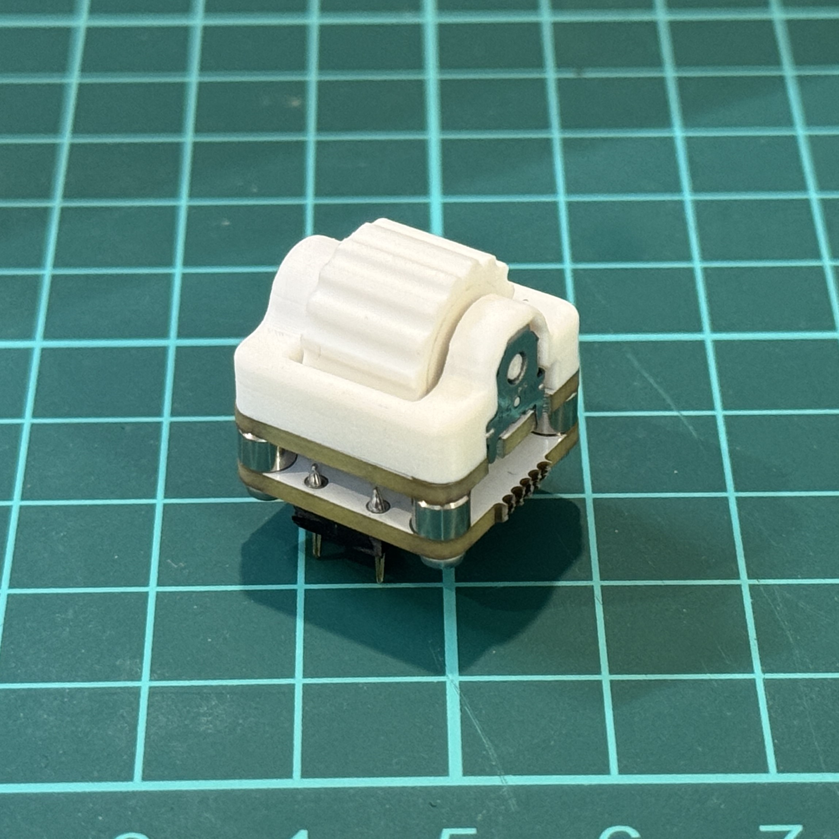
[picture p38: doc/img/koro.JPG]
  

まず、つながっている基板を切り離します。
カッターで切れ目をひっかき、その後、丁寧に折ると割れます。

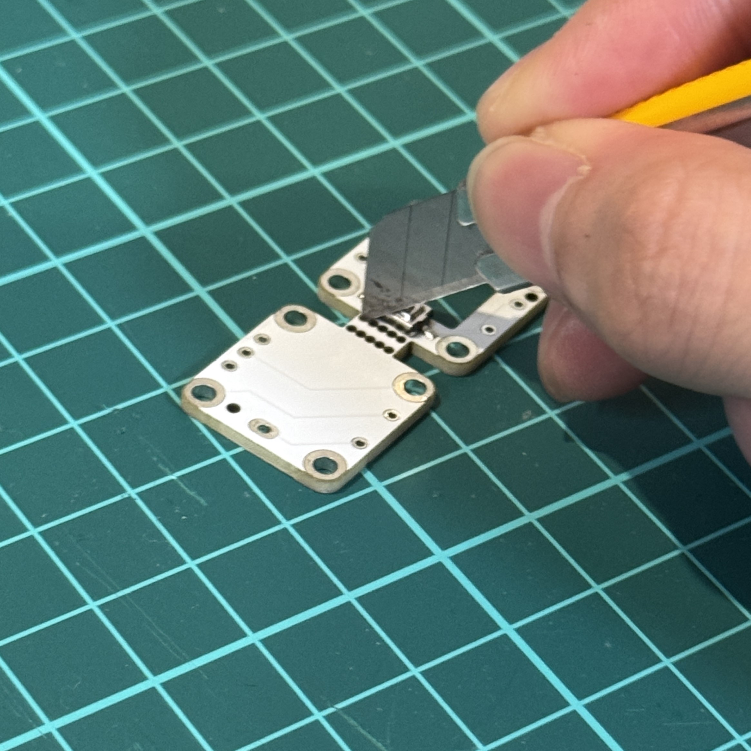
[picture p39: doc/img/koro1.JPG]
    

つなぎ目の不要な部分が残ってしまうと思うのでこれはペンチ等ではさんでおりましょう。

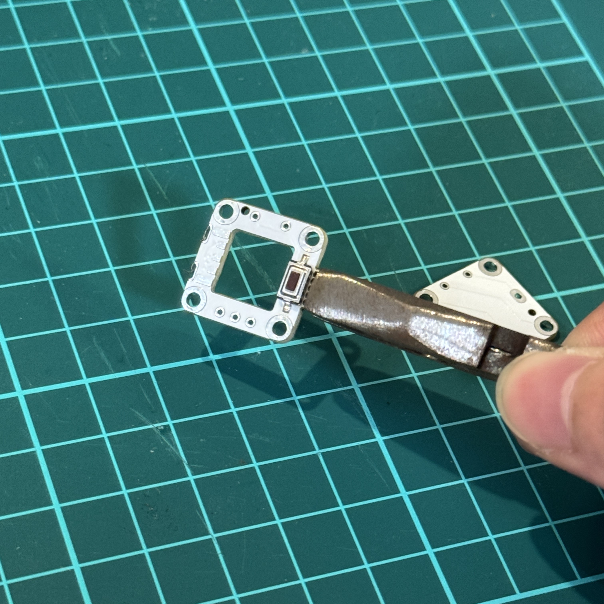
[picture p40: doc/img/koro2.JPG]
  

切れ目がとがってしまうので気になる方はやすって平らにしてください。  
私は見えなかったことにしました。  
そして下側となる基板（中央に穴のないほう）にポゴピンを1本付けます。  
分かりづらいですが、切り離す前に部品がついていたほうが表になります。  
表面に対して、上からポゴピンを差し込みます。
マステ等で固定して、裏からはんだ付けがいいかな思います。  

***↓これが表面です。***
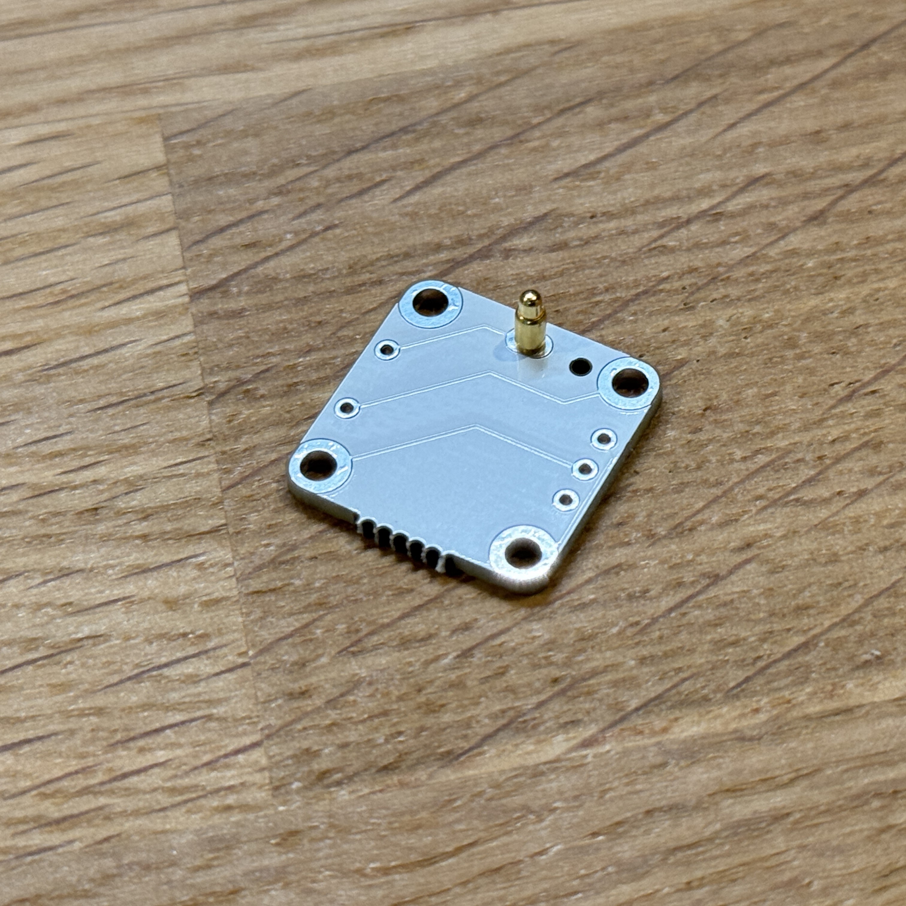
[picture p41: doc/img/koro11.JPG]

<!-- ![alt text](../img/koro3.JPG) -->

続いて裏面から8mmのネジで3mmスペーサーを固定します。  
このスペーサーが上下基板を繋ぐ導体になります。

<!-- ![alt text](../img/koro4.JPG)   -->

そして写真のようにコンスルーを取り付けます。  

※※※  
***キット付属のコンスルーは現状私がカットしており、カットミスで2pin側のコンスルーが1pin×2個になってしまっているものがあります。***  
***取り付けにくい場合は切断面をやすりで削る等対応いただけるとありがたいです。***

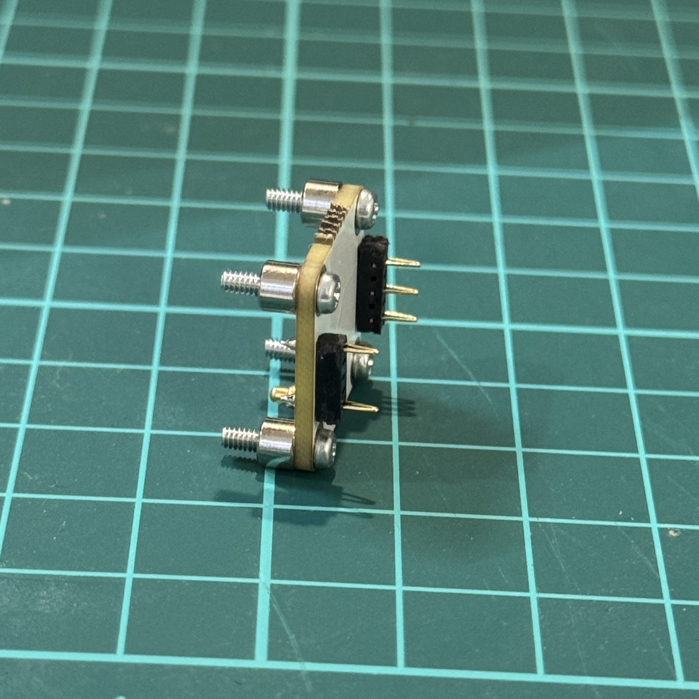
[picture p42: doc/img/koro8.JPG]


続いて上側の基板です。  
写真のようにロータリーエンコーダを置き、はんだで固定します。  
エンコーダ側面からはんだ付けすると楽かと思います。  
***端子部分ははんだ不良が起きやすいので、端子を小手でパッド側に押し付けつつ温めてはんだを流し込むようにすると良さそうです。***  
なのでここも細かい小手先がいいですね。  
エンコーダが動かない場合の原因は十中八九これです。  
きれいにはんだ出来ているように見えてもここを疑ってください。

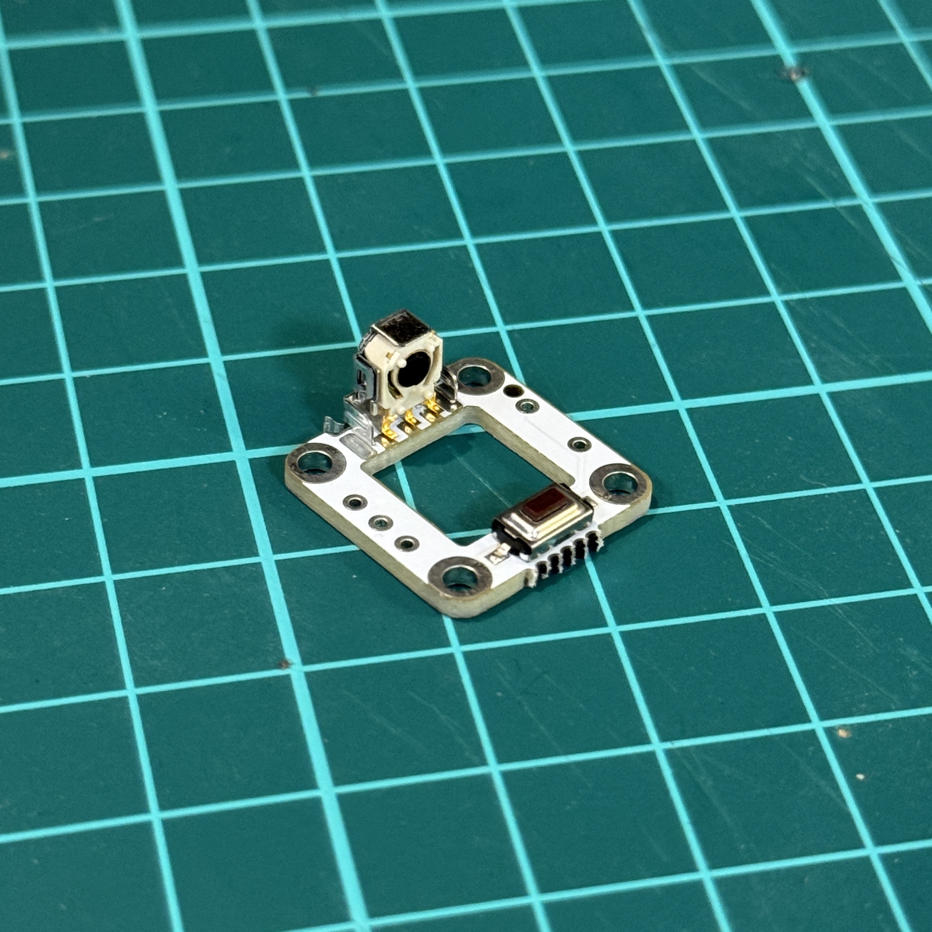
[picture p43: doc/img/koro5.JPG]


エンコーダにホイールとステムを取り付けます。  
まず、ホイールを置き、そしてスイッチ側からホイールの穴を通す形でステムを入れ込み、
ステムの先端をロータリーエンコーダに差し込んでください。  
ここで無理に押し込むとステムが折れてしまいます。  
***ステムの先端と、エンコーダーの穴がそれぞれ六角形になっているので、向きが合うのを確認してから慎重に差し込んでください。***

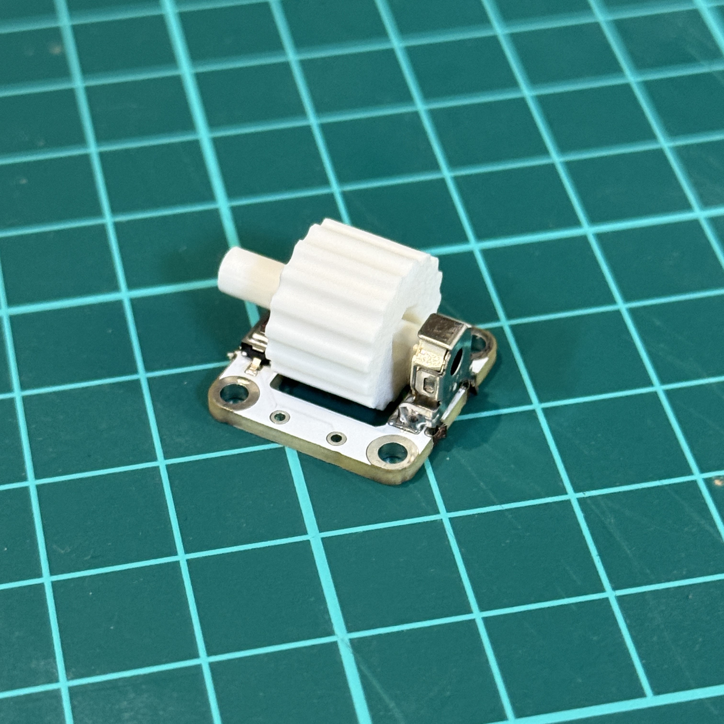
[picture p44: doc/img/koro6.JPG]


そして上からハウジングをかぶせます。
ハウジングの細かいサポート材が取り切れていないときれいに嵌らない場合があるので、もし取り残しがあればピンセットなどで取り除いてください。  

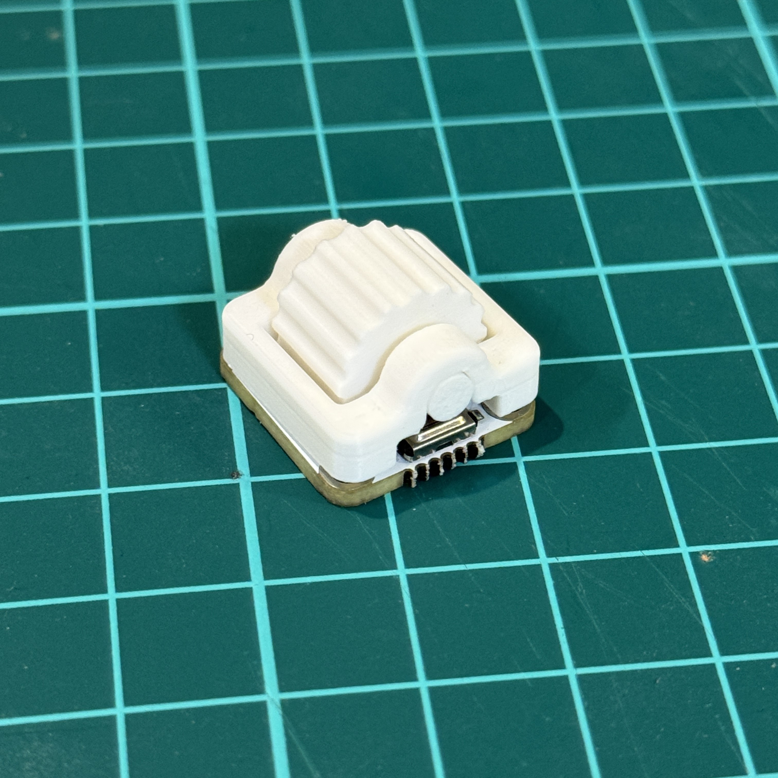
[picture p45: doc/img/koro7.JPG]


上下を取り付けます。
タクトスイッチ裏のパッドにポゴピンが当たるような向きにして、ネジをハウジングに差し込み固定してください。  
この際に固定が緩いと上下の基板の接続不良となってしまうため、しっかりと固定してください。

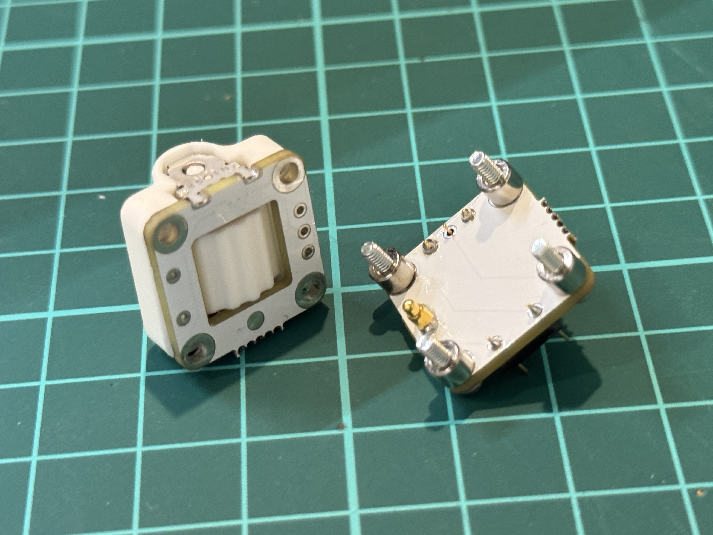
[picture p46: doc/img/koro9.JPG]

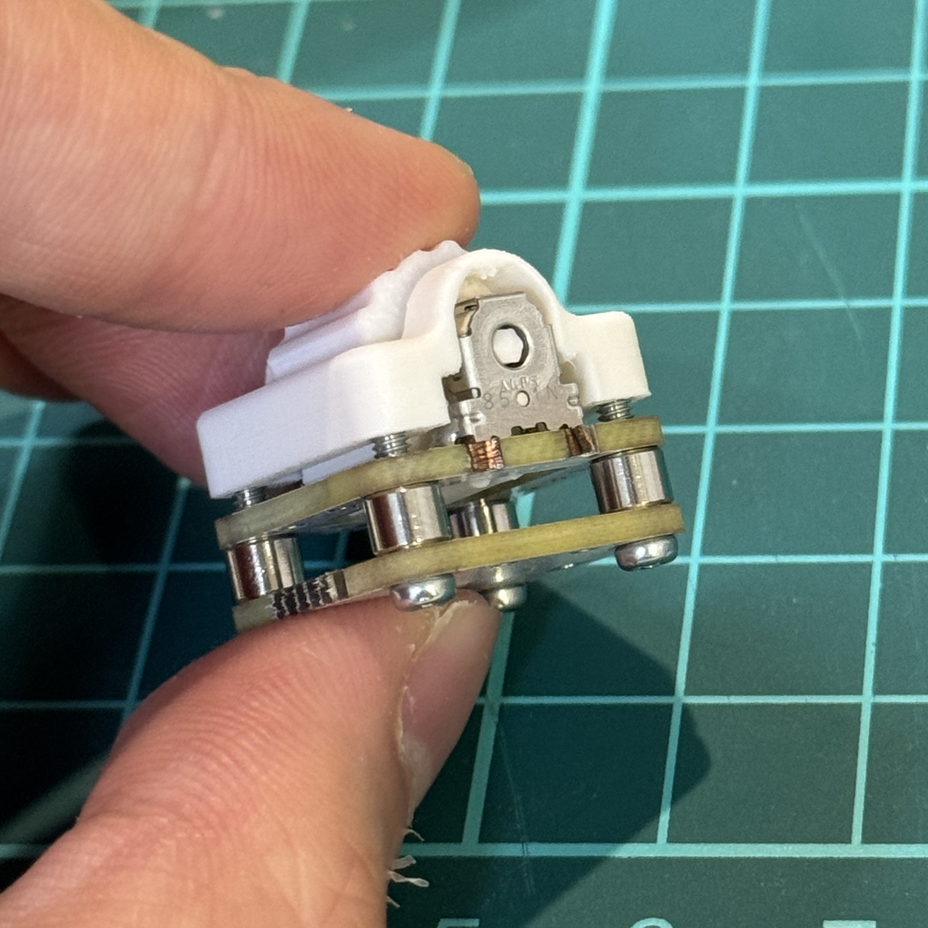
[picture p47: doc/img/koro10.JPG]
  
↑隙間がなくなるまでネジを締めてください。

以上で組み立て完了です。  
コンスルーを基板に差し込み取り付けてください。
なお、コンスルーの差し込みのみでの固定なので若干ぐらつきがあります。
気になる場合は交換不可になりますが、基板にはんだで固定してしまってもよいかもしれません。

+ メイン基板の裏に出ているピンははんだしないことでロータリーエンコーダを後から外し、キースイッチに取り換えることができます。

以上ですべてのはんだ付けが終了です。腰が丸まったと思うので背伸びしておいてください。お疲れ様でした。

なお、この時点で、[手順4-4](#4-4トラックボール読み取り基板差し込み)、[手順5](#5ファームウェアの書込み)あたりを行い、動作確認をしてしまうと組み立て後の後戻りが少なく楽かもしれません。

## 4．組み立て

### 4-1．バッテリーの確認及び取り付け

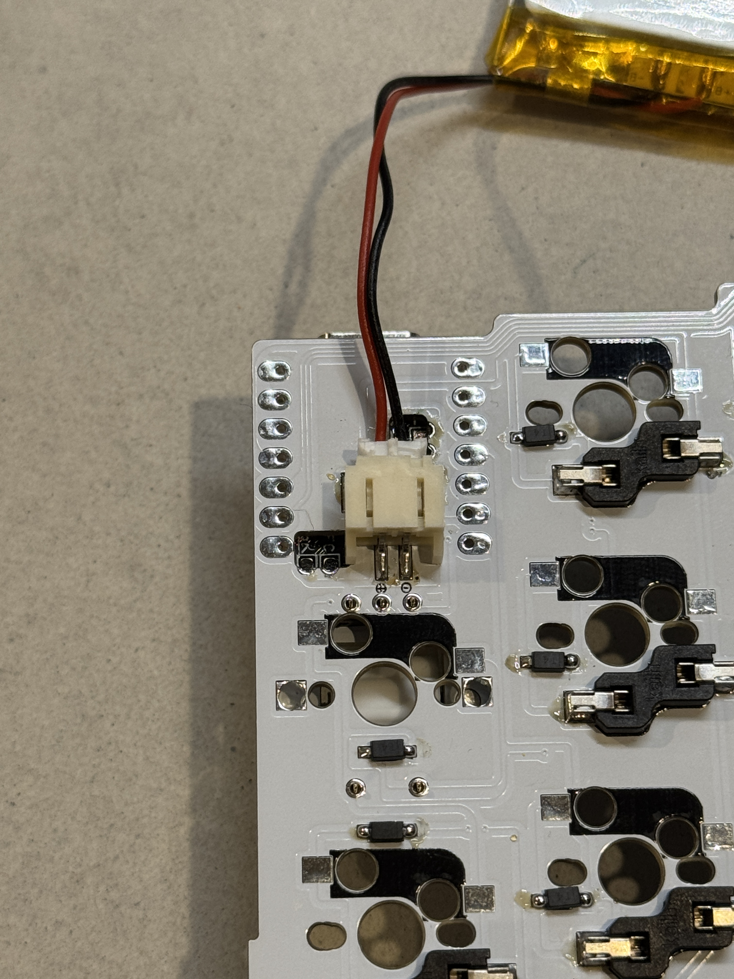
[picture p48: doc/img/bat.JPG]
  
> [!WARNING]  
> バッテリーの極性を確認してください。  
> 図のように裏面、USBが上になるような向きでバッテリーの銅線の赤い線が左に来ていれば極性は問題ないです。
> （この極性がわりとマイナーなことを後から知りました。。。）  
> 極性が逆のものを取り付けてしまわないよう注意してください。  

裏面のバッテリー用コネクタにバッテリーを差し込みます。  

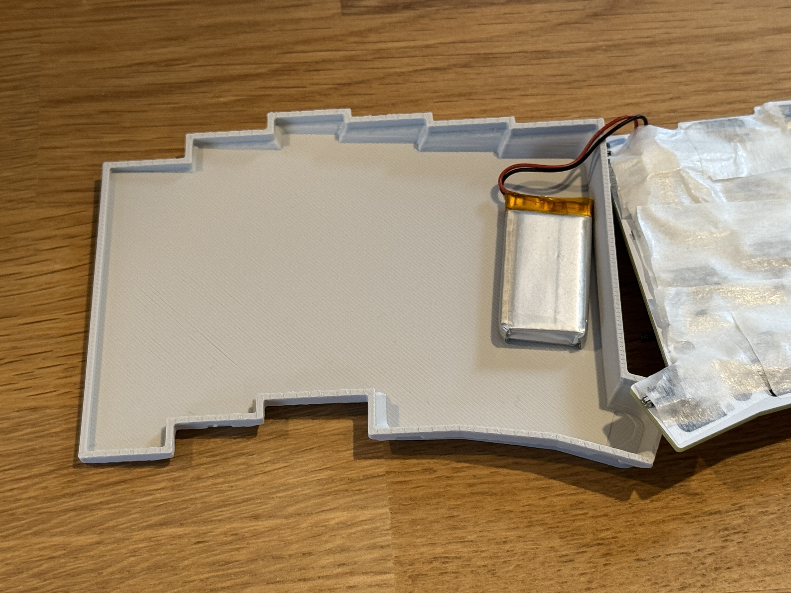
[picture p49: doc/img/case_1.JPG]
 

続いてバッテリーの裏に両面テープを貼り、ボトムプレートへ固定してください。  
いい感じのスチールプレートをボトムプレート内に張り付けるとテンティング用にいいかもですね。

### 4-2．ケースの組み立て

リセットスティックをケースの裏から差し込みます。
このスティックを介してマイコンのリセットボタンを押せるようにしています。 
(写真のスティックはv1のものなのでv2のものより短いです。) 

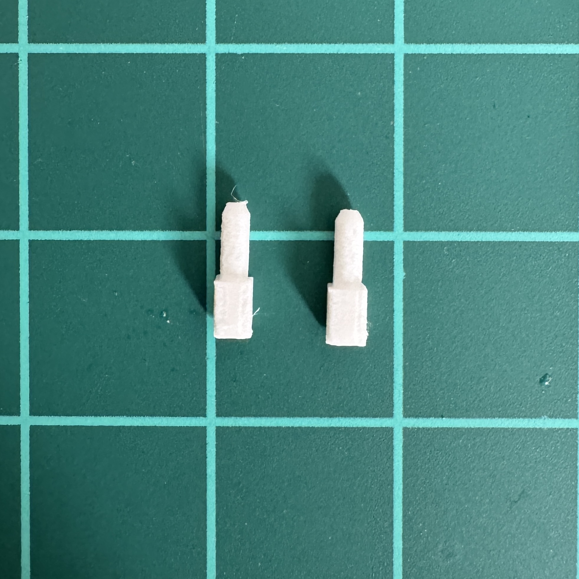
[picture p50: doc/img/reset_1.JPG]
  

基板の電源スイッチにはスイッチカバーを装着してください。  
スイッチをはめた状態でカバーに上下方向の力加えると簡単にスイッチが折れてしまうので気を付けてください。  

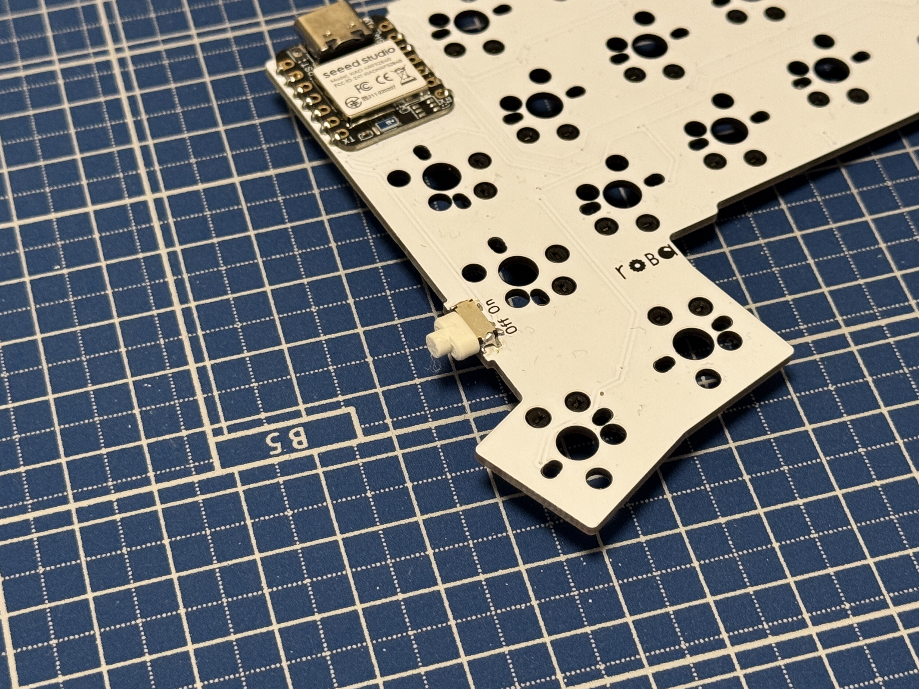
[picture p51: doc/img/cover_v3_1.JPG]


↓試作で自分用に印刷したやつなので色が異なってます

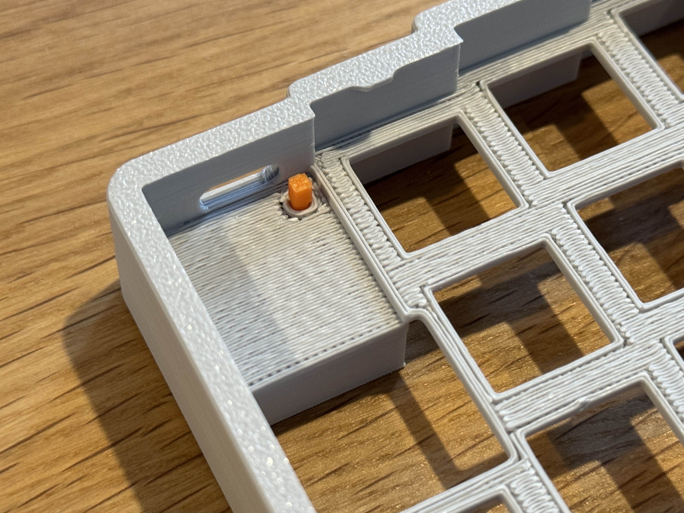
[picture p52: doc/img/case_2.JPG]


リセットスティックが落ちないように気を付けつつ、ケースの裏に基板を配置します。  

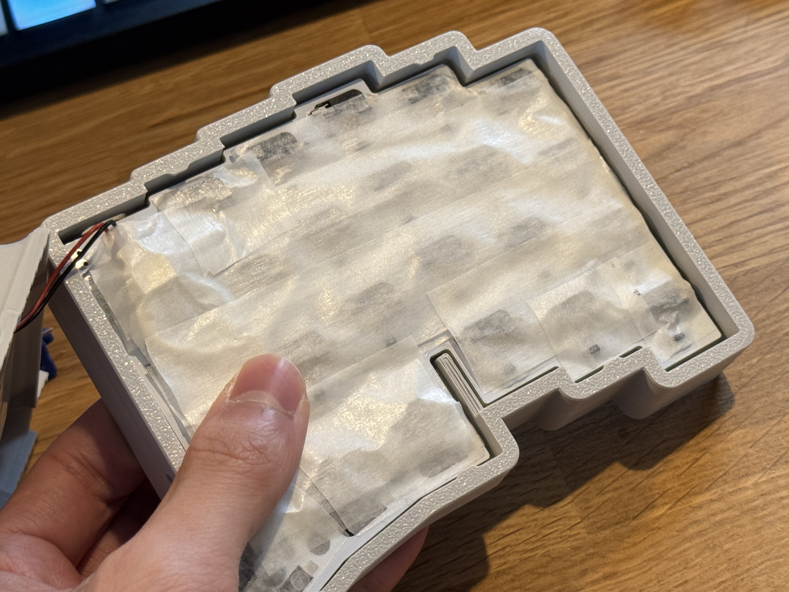
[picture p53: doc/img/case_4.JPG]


この時USB端子の位置がちょうどよい位置に来るように調整してください。

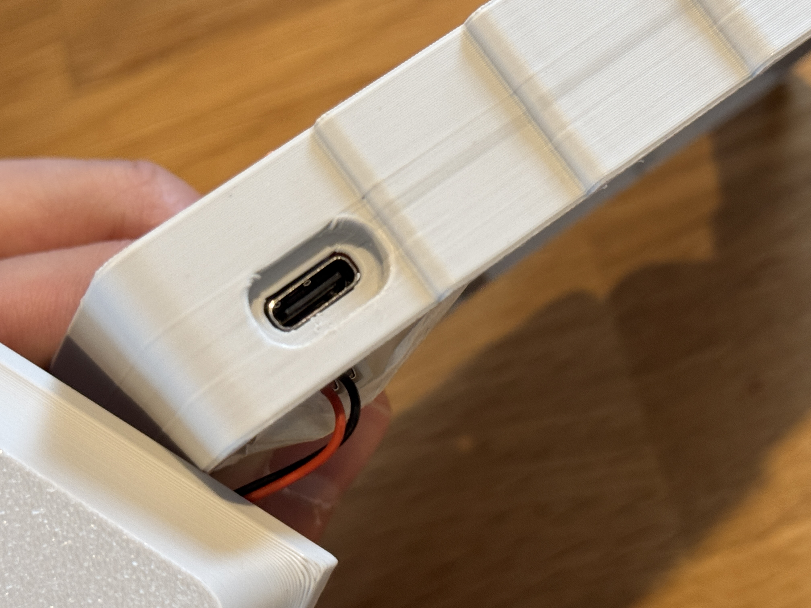
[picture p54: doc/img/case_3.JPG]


手で基板を裏から抑えつつ、四隅にスイッチを差し込み、ケースと基板を固定します。

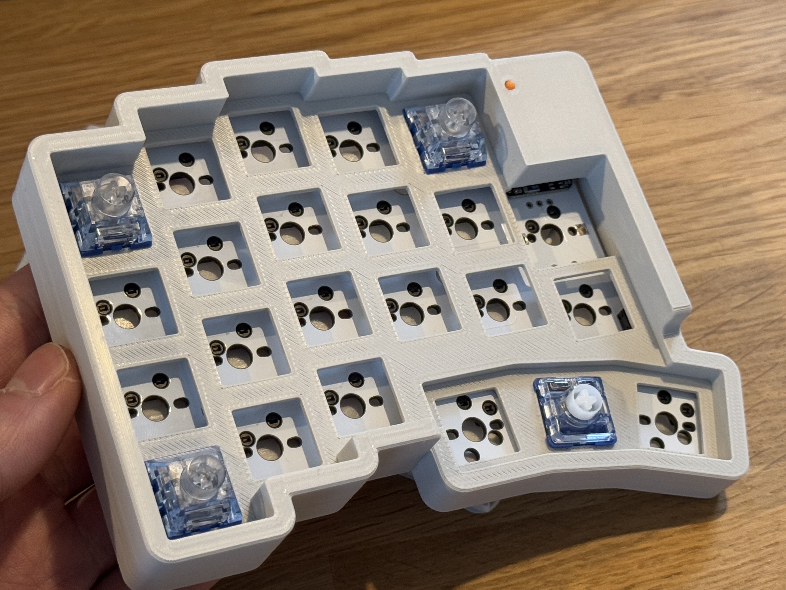
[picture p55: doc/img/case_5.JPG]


ケースと基板が固定出来たら、ボトムプレートを取り付けます。  
ケースの底面内側に小さなツメが前後にあるので、ボトムプレートのくぼみがそこに嵌るようにまず片側を押し込みます。

  

片側を合わせることができたらもう片側もくぼみにツメが嵌るように押し込みます。



### 4-3．トラックボール読み取り基板差し込み

メイン基板のL字コンスルーにトラックボール読み取り基板を差し込みます。  



### 4-4．トラックボールケース装着

トラックボール読み取り基板を取り付け後、トラックボールケースを上から差し込み、ボトムプレート裏からM1.7ネジで固定します。





以上で組み立て完了です。
あとはお好みでキースイッチ、キーキャップを取り付けてください。
お疲れ様でした！

## 5．ファームウェアの書込み

### 5-1．ファームウェア(仮)のダウンロード

(仮)としているのは、いずれキーマップをカスタマイズする際に現状ファームウェア自体を変更し、書込み直す必要があるためです。  
（zmk studioというプロジェクトが進んでいて、いずれファームウェアの変更なしにキーマップのみGUIで編集できるようになるらしいです。やったね。）

[こちら](https://drive.google.com/file/d/10D3QgOOYa3G7XiFyVIoovQ7wt79W96s5/view?usp=sharing)からzipファイルをダウンロードしてください。  

解凍すると以下の3つの.uf2ファイルが入っています。  
+ settings_reset-seeeduino_xiao_ble-zmk.uf2
+ roBa_L-seeeduino_xiao_ble-zmk.uf2
+ roBa_R-seeeduino_xiao_ble-zmk.uf2

### 5-2．ファームウェア(仮)の書込み
settings_reset-seeeduino_xiao_ble-zmk.uf2は[ここ](https://zmk.dev/docs/troubleshooting/connection-issues#split-keyboard-halves-unable-to-pair)にあるように分割キーボードのペアリングに関する問題を解決するための設定初期化用のファームウェアです。

1. PCと左側のマイコンをUSBで接続します。はじめはキーボードの電源はオフで大丈夫です。
2. マイコンのリセットボタンを2回押すと、「XIAO SENSE」という名前でUSBドライブとして認識されるかと思います。 (ブートローダの起動)
3. 「XIAO SENSE」ドライブにsettings_reset-seeeduino_xiao_ble-zmk.uf2をドラッグアンドドロップします。  
※MacOSの場合、以下のようなエラーが出るようですが無視して進めて問題なく、実際には書込みができているとのことです。 (画像提供：shakupanさん)

4. 書込み完了すると、「XIAO SENSE」というドライブは消えますが、再度セットボタンを2回押し、ブートローダを起動します。  
5. 「XIAO SENSE」ドライブにroBa_L-seeeduino_xiao_ble-zmk.uf2をドラッグアンドドロップします。  
6. 右側も同様の手順でsettings_reset-seeeduino_xiao_ble-zmk.uf2とroBa_R-seeeduino_xiao_ble-zmk.uf2を順番に書き込みます。
7. 両方の書込みが完了したら、電源を入れ、それぞれのマイコンのリセットボタンを**1回**押します。
8. PCでbluetoothデバイスとして「roBa」が認識され接続できればOKです。  

### 5-3．動作確認

bluetooth接続が完了したらすべてのキーが認識するか、ロータリーエンコーダ、トラックボールが問題なく動作するか確認しましょう。  
左右間のペアリングは電源を入れると自動的に行われます。  
有線接続でも動作しますが、左右間は無線接続のみになります。  
ファームウェア(仮) では以下のような接続方式になっているのでロータリーエンコーダ側はPCに有線接続してもキーボードとして動作しません。  
+ ロータリーエンコーダ側(ペリフェラル) ⇔ (無線接続) ⇔ トラックボール側(セントラル) ⇔ (無線or有線接続) ⇔ PC

なお、このファームウェアではデフォルトでオートマウスレイヤーが**4**、スクロールレイヤーが**5**となっています。

## 6．キーマップの編集
***※REMAPやVialには対応していません。***

冒頭で書いたようにzmk firmwareの編集にはgithubのアカウントが必要です。  
一からファームウェアを用意する際の手順は[公式ドキュメントの導入解説](https://zmk.dev/docs/user-setup)を見るとわかりやすいです。  
以下では、私が作成したリポジトリをフォークし、[KeymapEditor](https://nickcoutsos.github.io/keymap-editor/)を用いてGUIでキーマップを書き換える手順を紹介します。  

1. githubアカウントを作成し、ログインします。
2. [このリポジトリ](https://github.com/kumamuk-git/zmk-config-roBa)にアクセス
3. 画面右上の「Fork」をクリック

4. そのまま「Create fork」をクリック

5. フォークしたリポジトリの「Actions」タブに移動し、「I understand my workflows, go ahead and enable them」をクリックし、github Actionsを有効化

6. [KeymapEditor](https://nickcoutsos.github.io/keymap-editor/)にアクセス  
7. 「GitHub」を選択
  
8. 「Login with GitHub」からでログインし、「Authorize Keymap Editor」を選択  
9. 指示に従い、フォークしたzmk-config-roBaにKeymap Editorがアクセスできるように進める
10. Keymap Editor上でキーマップが表示されたら、好きにキーマップを編集する
11. 画面左上の「Save」を押すと、編集したキーマップが適用されてGitHub Actionsが走り、自動的にビルドが開始します

12. 「Save」の隣に表示される「Latest」をクリックするとGitHubに移動し、ビルドが完了するとファームウェアがダウンロードできるようになります。  
（ビルドには2～4分かかる場合があります。）
13. [書込み手順](#5-2ファームウェア仮の書込み)に従い、ファームウェアを書き込みます。  
    + キーマップの編集のみの場合はトラックボール側(セントラル)のみを書き換えることで変更が適用されます。  
    リセットファームウェアの書込みも基本的には必要ありません。
    + KeymapEditorを用いずにroBa.keymap以外のファイルの内容を書き換えた場合は、左右のファームウェアを書き換えてください。  
    + **ファームウェアを書き直した際は、PC側のペアリング情報も削除してから再度ペアリングを行ってください。**
14. 無事に変更したキーマップが適用されていれば成功です。

### 番外編
+ トラボの上下左右操作にキー入力を割り当てる
kotさんのおかげで以下でトラックボールの上下左右操作にキー入力を割り当てることができるようになります。  
kotさんありがとうございます。  
[#36](https://github.com/kumamuk-git/zmk-config-roBa/pull/36)からデフォルトでroBa.keymapファイルにコメントアウトされた状態で矢印割り当てが記載されています。  
コメント解除することでこちらの機能を使うことができるようになりました。

```c:roBa.keymap
&trackball {
    automouse-layer = <4>;
    scroll-layers = <5>;

    // arrows {
    //     layers = <3>;
    //     bindings =
    //         <&kp RIGHT_ARROW>,
    //         <&kp LEFT_ARROW>,
    //         <&kp UP_ARROW>,
    //         <&kp DOWN_ARROW>;

    //     tick = <10>;
    //     wait-ms = <5>;
    //     tap-ms = <5>;
    // };
};
```

## 7．トラブルシューティング

### bluetoothデバイスとして認識されない or 認識しても接続できない or 接続できたが片側が反応しない
+ [zmk firmware公式のトラブルシューティング](https://zmk.dev/docs/troubleshooting/connection-issues#split-keyboard-halves-unable-to-pair)にあるようにまずはsettings_reset-seeeduino_xiao_ble-zmk.uf2の書込みからやり直すことをお勧めします。  
+ （あまりないと思いますが）マイコン自体に問題がないか確認するため、キーボードに接続しない状態マイコン2個で認識、接続できるかも一応試してみてください。  
### トラックボールが動かない  
+ （あまりないと思いますが）ケースが正しく装着できておらずセンサの読み取り部分が隠れてしまっていないか確認してください。
+ トラックボール読み取り基板とセンサのはんだに不良がないか確認してください。  
  + はんだに失敗しやり直し不可の場合は、センサとトラックボール読み取り基板のみで保守部品としてboothで販売予定ですのでそちらをご利用ください。  
+ settings_reset-seeeduino_xiao_ble-zmk.uf2の書込みからやり直してみることが有効な場合があります。  

### 一部キーが反応しない  
+ はんだ不良、ポゴピンの接触不良、ダイオードの向き、キースイッチが正しくソケットに刺さっているかを確認してください。  
+ 白湯さん（moNaの設計者）がトラブルシューティング用の[note](https://note.com/pooh_polo/n/n386f7c9355bc)を書いてくださいました！  キーなどが反応しない場合はまずこちら目を通して頂くと良いと思います！

### 充電ができない
+ 電源オフ時にはバッテリーを回路から切り離しているため充電も動作しません。電源をオンの状態で充電を実施してください。

### zmk firmwareについて
このキーボード固有の問題ではなくファームウェアのカスタマイズ等で疑問点がある場合、以下が参考になると思います。  
+ [公式ドキュメント](https://zmk.dev/)
  + かなり丁寧に作りこまれているので基本的な設定はドキュメント見ればわかると思います。
+ [zmk firmware Discordサーバ](https://zmk.dev/community/discord/invite)  
  + 活発に動いているので質問すると誰かしら回答くれることが多いです。

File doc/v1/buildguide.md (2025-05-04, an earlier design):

# Build Guide for roBa

## 目次
  - [1．部品確認](#1部品確認)
    - [1-1．キット内容](#1-1キット内容)
    - [1-2．別途準備が必要な部品](#1-2別途準備が必要な部品)
    - [1-3．オプション](#1-3オプション)
  - [2．準備](#2準備)
    - [2-1．必要な工具](#2-1必要な工具)
    - [2-2．ファームウェア](#2-2ファームウェア)
  - [3．実装](#3実装)
    - [3-1．ダイオードのはんだ付け](#3-1ダイオードのはんだ付け)
    - [3-2．キーソケットのはんだ付け](#3-2キーソケットのはんだ付け)
    - [3-3．スライドスイッチのはんだ付け](#3-3スライドスイッチのはんだ付け)
    - [3-4．ポゴピンのはんだ付け](#3-4ポゴピンのはんだ付け)
    - [3-5．コネクタのはんだ付け](#3-5コネクタのはんだ付け)
    - [3-6．ピンソケットのはんだ付け](#3-6ピンソケットのはんだ付け)
    - [3-7．ピンヘッダのはんだ付け](#3-7ピンヘッダのはんだ付け)
    - [3-8．L字コンスルーのはんだ付け](#3-8l字コンスルーのはんだ付け)  
    - [3-9．センサのはんだ付け](#3-9センサのはんだ付け)
    - [3-10．ロータリーエンコーダのはんだ付け](#3-10ロータリーエンコーダのはんだ付け)
  - [4．組み立て](#4組み立て)
    - [4-1．バッテリーの取り付け](#4-1バッテリーの取り付け)
    - [4-2．ケースとトッププレートの取り付け](#4-2ケースとトッププレートの組み立て)
    - [4-3．ボトムプレートの取り付け](#4-3ボトムプレートの組み立て)
    - [4-4．トラックボール読み取り基板差し込み](#4-4トラックボール読み取り基板差し込み)
    - [4-5．トラックボールケース装着](#4-5トラックボールケース装着)  
    - [4-6．電源スイッチキャップ装着](#4-6電源スイッチキャップ装着)
  - [5．ファームウェア書込み](#5ファームウェアの書込み)
    - [5-1．ファームウェア(仮)のダウンロード](#5-1ファームウェア仮のダウンロード)
    - [5-2．ファームウェア(仮)の書込み](#5-2ファームウェア仮の書込み)
    - [5-3．動作確認](#5-3動作確認)
  - [6．キーマップの編集](#6キーマップの編集)
  - [7．トラブルシューティング](#7トラブルシューティング)

## 1．部品確認

### 1-1．キット内容



| 名前 | 数 | 備考 |
|:-|---:|:-|
| メイン基板(左右) | 1組 | |
| トッププレート(左右) | 1組 |メインと親指部のセット 3Dプリント品 |
| ボトムプレート(左右) | 1組 | 3Dプリント品|
| ケース(左右) | 1組 | 3Dプリント品|
| リセットボタン用スティック | 2本 | 3Dプリント品|
| 電源スイッチキャップ | 2本 | 3Dプリント品|
| トラックボールケース | 1個 | 3Dプリント品|
| Φ2 セラミックボール | 3個 | トラックボールケースに取り付け済み |
| 水平ロータリーエンコーダ | 1個 | EVQWGD001|
| ロータリーエンコーダ用基板 | 1個 | |
| トラックボール読取り基板 | 1枚 | |
| トラックボール読取りセンサ | 1個 | PMW3610|
| 読取りセンサ用レンズ | 1個 | |
| L字コンスルーピン(7ピン) | 1個 | |
| コンスルーピン(3ピン) | 2個 |うち1つは中央のピンが不必要のため取り外しています |
| ピンソケット(7ピン) | 4本 | |
| ピンヘッダ(7ピン) | 4本 | |
| スプリングピン(ポゴピン) | 8本 | GB15-07020-0818-2A|
| PHコネクタ | 2個 | |
| スライドスイッチ | 2個 | |
| ダイオード（表面実装タイプ）  | 50個 | 予備含む|
| Kailh PCBソケット CherryMX用  | 40個 ||
| Kailh PCBソケット choc用 | 5個 | |
| スペーサー M2 7mm | 10本 | |
| スペーサー M2 4mm | 3本 | |
| ネジ M2 3.5mm | 28本 | 予備含む |
| ネジ M1.7 | 2本 | |
| クッションゴム | 4個 | |  

なお3Dプリントケースはgithub上で公開しています。  
ボトムプレートは4度の傾斜が付いているのでスライサーソフトで4度回転させると平面に印刷できます。  
#### 初回ロット購入者でポゴピンを別途追加で購入したい方へ
ポゴピンをGB15-07020-0818-2Aこの型番でaliexpressで購入すると基板に差すことができない可能性があります。  
最近購入できるものは、以前まで購入できたものよりも根本のピンの直径がやや太くなってしまっています。
GB15-07020-0818-2Aのピンをやすりで削るか、GB15-07020-0618-2Aの型番(未検証だがスペック的に)を購入するかで対応可能と思います。  
次のロットではこのピンの仕様変更に対応した基板になっています。

### 1-2．別途準備が必要な部品

| 名前 | 数 | 備考 |参考情報|
|:-|-:|:-|:-|
| Xiao nrf52840 | 2個 |  |[主な購入先](https://akizukidenshi.com/catalog/g/g117341/)|
| CherryMX互換キースイッチ | 37個  |  |
| ロープロファイルキースイッチ  | 5個 |  |
| 直径34mmトラックボール | 1個 |  |[主な購入先](https://www.amazon.co.jp/%E3%81%BA%E3%83%AA%E3%83%83%E3%82%AF%E3%82%B9-PERIPRO-303WH-%E4%BA%A4%E6%8F%9B%E7%94%A8%E3%83%88%E3%83%A9%E3%83%83%E3%82%AF%E3%83%9C%E3%83%B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)|
| 5mm幅カプトンテープ | 数cm  | 近接したポゴピンの保護に使用しますので**必ず**用意してください |[主な購入先](https://www.amazon.co.jp/gp/product/B0983F8L41/ref=ppx_yo_dt_b_asin_title_o00_s00?ie=UTF8&psc=1)|
| Lipoバッテリー(コネクタ付き)  | 2個 | ボトムプレートはL53mm × H23mm × H6mm 以内の大きさに対応 |[主な購入先](https://www.amazon.co.jp/gp/product/B09DPNZM31/ref=ppx_yo_dt_b_asin_title_o01_s00?ie=UTF8&th=1)|
| USB type-Cケーブル | 1本 | ファームウェア書込みと充電に必要 |
| キーキャップ | 37個  | 1u 37個 |
| ロープロファイルキーキャップ  | 5個 | 1u ５個 |
| 両面テープ | - | ボトムプレートへのバッテリーの固定に必要|

※リポバッテリーには発火等の危険性があります。各自購入したバッテリーの注意事項をよく読み、適切に取り扱うよう注意してください。  
　取り扱いの不備により発生した事故等の責任は負いかねます。  
※主な購入先のリンクはアフェリエイトリンクではありません。

### 1-3．オプション
+ ロータリーエンコーダ部分にキーソケットを取り付けキースイッチを取り付けることも可能です。
+ ボトムプレートに直径4cmの円形のスペースを設けています。ステンレスプレートなどを仕込むことが可能です。

## 2．準備

### 2-1．必要な工具
| 名前 | 備考 |
|:-|:-|
| はんだごて  | 温度調整可能だと◎|
| はんだ | |
| ピンセット  | |
| ドライバ ||
| マスキングテープ||
| テスター||
| ペンチ||

### 2-2．ファームウェア
Xiao nrf52840へファームウェアの書込みが必要です。  
ビルド済みのファームウェアは[こちら](https://github.com/kumamuk-git/zmk-config-roBa/actions/runs/10759328125)です。  
zmk firmwareを使用しているため、ご自身でファームウェアやキーマップをカスタムされる場合はgithubアカウントが必要になります。  

## 3．実装

### 3-1．ダイオードのはんだ付け
ダイオードは基板裏面（roBaロゴがない面）に実装します。ダイオードは実装の向きがあります。  
ダイオードに薄く書かれている線と基板に印刷された図（以降シルク）にある線が同じ方向になるように取り付けて下さい。  

ダイオード用パッドの片側にはんだを盛ります。  



そしてピンセットでダイオードを掴み、シルクと向きを合わせて事前に盛ったはんだを溶かしつつ位置を合わせます。 

 

およそシルクと同じ位置に決まったら、もう片側もはんだで固定します。



ピンセットでダイオードが取れないことを確認したら取り付け完了です。  
これをすべて(43箇所)に対して行います。

### 3-2．キーソケットのはんだ付け  
キーソケットも基板裏面に実装します。  
親指部分はchoc用のキーソケットを使用してください。  
ダイオードと同様に片方のパッドに事前にはんだを盛ります。  



そして、キーソケットをシルクに合う向きで基板にはめ込みます。  
その状態のまま、キーソケットをピンセットで抑えつつ、事前に盛ったはんだを溶かすとキーソケットが沈み、固定できます。  



固定出来たら、反対側のパッドもはんだで固定します。  



<!--
写真  (ロータリーエンコーダ取り付け部分のソケット)
-->

### 3-3．スライドスイッチのはんだ付け  
このスライドスイッチが電源スイッチとなります。  
スライドスイッチは基板表面に実装します。  



表面からピンを差し込み、マスキングで仮止めします。  



そして裏面から出たピンをはんだ付けし、固定します。  



はんだ付け後、ピンが長い場合はペンチ等で短くカットしても良いかもしれません。  

### 3-4．ポゴピンのはんだ付け  
ポゴピンって名称がいいですよね。口に出して言いたい単語です。  



名称のわりにポゴピンのはんだ付けが一番難易度高いかもしれません。  
ポゴピンは基板表面に実装します。  
実装部分に差し込み、ポゴピンの根本をはんだで固定します。  



この時ポゴピンが斜めになり、隣のポゴピンに接触しないように注意してください。
手が3本ある方は角度をピンセットで調整しながらやるとgoodです。
テスタなどで隣接したポゴピンが導通していないかを必ず確認してください。  
確認出来たら念のため、カプトンテープで保護し、取付完了です。



左右各4箇所、合わせて計8箇所あります。

実際かなり難しく斜めになってしまう場合があります。
角度が悪いとマイコンとの接触が悪くなりキーが反応しない場合があります。
その場合、ポゴピン裏のランドにはんだごてをあてて温め、
表からピンセットで角度調整するようにしてください。
なお、かなり不安定な作業で危険なためほかの人の助けを借りたほうが良さそうです。




### 3-5．コネクタのはんだ付け  

バッテリ取り付け用のコネクタです。  
コネクタは基板表面に実装します。  



表面からシルクに合うような向きで差し込み、マスキングテープで仮止めします。  

そして、裏面からはんだで固定します。

 

左右各1箇所、計2箇所取り付けます。

### 3-6．ピンソケットのはんだ付け  

マイコン取り付け用のソケットです。  
基板表面に実装します。 

 

片方はポゴピンに盛ったはんだが邪魔して垂直に差しづらい場合があります。
その場合はお手数ですがピンソケットのはしを少しやすりで削る等して垂直にさせるようにしてください。
基板に対して垂直でないとこれもポゴピンがマイコンに適切に接触しない原因になります。
ピンヘッダとマイコンを仮に重ねて事前に正しく接触しそうか確認するとよいかもしれません。

表面から差し込み、マスキングテープで仮止めします。  



そして、裏面からはんだで固定します。  



左右各2箇所、計4箇所取り付けます。  

### 3-7．ピンヘッダのはんだ付け  

ピンヘッダはマイコンにはんだで取り付けます。  
まず、先ほど取り付けたソケットにそれぞれピンヘッダを差し込みます。  
短いピンがソケット側になります。



その状態でマイコンにピンヘッダを差し込みます。  

しっかりと奥まで差し込まれた状態(ポゴピンの先が押し込まれ、マイコンのパッドに接触している状態)で、マイコンにピンヘッダをはんだ付けします。



### 3-8．L字コンスルーのはんだ付け  

トラックボール読み取り基板を取り付けるためのコンスルーです。  
コンスルーには輪っかになっているピンと1本の直線のピンがありますが、直線のピンのほうを基板へ取り付けます。  
コンスルーは基板表面に実装します。  
表面から差し込み、マスキングテープで仮止めします。



そして、裏面からはんだで固定します。  



トラックボール取り付け側の基板のみ1箇所です。  

### 3-9．センサのはんだ付け  

トラックボール読み取り基板へセンサをはんだ付けします。  
「pmw3610 module」の文字がある面を表面とし、裏面からセンサを差し込みます。  
このとき、向きを間違えないよう写真をよく確認してください。  
裏面に書かれた文字とセンサに書かれた文字の上下が揃っている向きが正しい向きです。 



そして、表面に出たセンサのピンをすべてはんだ付けしていきます。  
センサのデータシートによると**最大260℃**までの温度、**7秒以内**でのはんだづけが推奨されています。  
これ以上高い温度または長時間での作業はセンサの故障につながる恐れがありますので注意してください。  
とはいえ焦って作業するのも良くないので適度に冷ましつつ落ち着いて作業してください。

+ ランドの面積が小さいので、はんだを盛りすぎてピンがブリッジしてしまわないように注意してください。  
個人的に手前のピンから順にはんだ付けしていくほうが失敗がなさそうです。

+ また、はんだ不良によりセンサが動作しない場合もありますので、  
センサが動作しない場合は、まず、この部分のはんだに不良がないか確認するとよいです。  
基板の接続は以下のようになっていますので参考にしてください。



はんだづけが完了したら保護シールをはがしてください。



センサの取り付けが完了したら、レンズを装着してください。 



### 3-10．ロータリーエンコーダのはんだ付け

このロータリーエンコーダはメイン基板に直接実装すると少し背が低いので、一枚基板を挟んで取り付けます。

写真のように基板にロータリーエンコーダを差し込みます。



裏面から出たピンをはんだで固定します。  
(完全に盲点だったんですが、ロータリーエンコーダが丸いため安定した状態での作業がなかなか難しいです。
各自テープで固定して作業するなど工夫して安全な作業をお願いします。
写真はマスキングテープで頑張りましたが安全とはいい難しです。)



ロータリーエンコーダの取り付けが完了したら、メイン基板へ差し込みます。  



+ メイン基板の裏に出ているピンははんだしないことでロータリーエンコーダを後から外し、キースイッチに取り換えることができます。

以上ですべてのはんだ付けが終了です。腰が丸まったと思うので背伸びしておいてください。お疲れ様でした。

なお、この時点で、[手順4-4](#4-4トラックボール読み取り基板差し込み)、[手順5](#5ファームウェアの書込み)あたりを行い、動作確認をしてしまうと組み立て後の後戻りが少なく楽かもしれません。

## 4．組み立て

### 4-1．バッテリーの取り付け

バッテリー用コネクタにバッテリーを差し込みます。  
基板の切り欠きから配線を裏に通すようにします。
購入したバッテリと極性(写真のような線の色)が合っているかを確認し取り付けてください。



### 4-2．ケースとトッププレートの取り付け

メイン基板の上にケースを乗せます。  
この時、ケースのマイコン上部にある穴にリセットボタン用スティックを差し込みます。  
このスティックを介してマイコンのリセットボタンを押せるようにしています。  





続いてトッププレートにスペーサをねじ止めします。
親指部分に4mmスペーサを使用します。他は7mmスペーサを使用します。



そして、ケースの上からトッププレートを乗せます。  
トッププレートとメイン基板で挟み込みケースを固定する構造になっています。  
トッププレートとメイン基板の間は空洞になっていますが、お好みでポロンシートなど仕込むと打鍵音にいい影響があるかもしれません。 



### 4-3．ボトムプレートの取り付け

ボトムプレートのくぼみにバッテリーを収納します。  
この時バッテリーの裏に両面テープを貼り、ケースへ固定することをお勧めします。  





また、小さいサイズのバッテリーを使用し、スペースが余る場合はポロンシートなどで隙間を埋めておくと良いかもしれません。 
さらに、打鍵音を気にする方は、メイン基板の裏にマスキングテープを張っておくと打鍵音が多少良くなります。

バッテリーを収納することができたら、ケース裏にボトムプレートをはめ込みます。  
そして、裏からM2ネジで固定します。



### 4-4．トラックボール読み取り基板差し込み

メイン基板のL字コンスルーにトラックボール読み取り基板を差し込みます。  



### 4-5．トラックボールケース装着

トラックボール読み取り基板を取り付け後、トラックボールケースを上から差し込み、ボトムプレート裏からM1.7ネジで固定します。





### 4-6．電源スイッチキャップ装着



電源スイッチキャップをスライドスイッチに差し込みます。
緩いと感じる場合はラップの破片など挟むとよい滑り止めになるかもしれません。

電源スイッチのオンオフの向きは初回ロット(9/15booth販売分)のみ写真のような向きになっています。  
それ以降は基本的に左右ともに手前がオフ、奥がオンに揃っています。



以上で組み立て完了です。
あとはお好みでキースイッチ、キーキャップを取り付けてください。
お疲れ様でした！

## 5．ファームウェアの書込み

### 5-1．ファームウェア(仮)のダウンロード

(仮)としているのは、いずれキーマップをカスタマイズする際に現状ファームウェア自体を変更し、書込み直す必要があるためです。  
（zmk studioというプロジェクトが進んでいて、いずれファームウェアの変更なしにキーマップのみGUIで編集できるようになるらしいです。やったね。）

[こちら](https://drive.google.com/file/d/10D3QgOOYa3G7XiFyVIoovQ7wt79W96s5/view?usp=sharing)からzipファイルをダウンロードしてください。  

解凍すると以下の3つの.uf2ファイルが入っています。  
+ settings_reset-seeeduino_xiao_ble-zmk.uf2
+ roBa_L-seeeduino_xiao_ble-zmk.uf2
+ roBa_R-seeeduino_xiao_ble-zmk.uf2

### 5-2．ファームウェア(仮)の書込み
settings_reset-seeeduino_xiao_ble-zmk.uf2は[ここ](https://zmk.dev/docs/troubleshooting/connection-issues#split-keyboard-halves-unable-to-pair)にあるように分割キーボードのペアリングに関する問題を解決するための設定初期化用のファームウェアです。

1. PCと左側のマイコンをUSBで接続します。はじめはキーボードの電源はオフで大丈夫です。
2. マイコンのリセットボタンを2回押すと、「XIAO SENSE」という名前でUSBドライブとして認識されるかと思います。(ブートローダの起動)
3. 「XIAO SENSE」ドライブにsettings_reset-seeeduino_xiao_ble-zmk.uf2をドラッグアンドドロップします。  
4. 書込み完了すると、「XIAO SENSE」というドライブは消えますが、再度セットボタンを2回押し、ブートローダを起動します。  
5. 「XIAO SENSE」ドライブにroBa_L-seeeduino_xiao_ble-zmk.uf2をドラッグアンドドロップします。  
6. 右側も同様の手順でsettings_reset-seeeduino_xiao_ble-zmk.uf2とroBa_R-seeeduino_xiao_ble-zmk.uf2を順番に書き込みます。
7. 両方の書込みが完了したら、電源を入れ、それぞれのマイコンのリセットボタンを**1回**押します。
8. PCでbluetoothデバイスとして「roBa」が認識され接続できればOKです。  

### 5-3．動作確認

bluetooth接続が完了したらすべてのキーが認識するか、ロータリーエンコーダ、トラックボールが問題なく動作するか確認しましょう。  
左右間のペアリングは電源を入れると自動的に行われます。  
有線接続でも動作しますが、左右間は無線接続のみになります。  
ファームウェア(仮) では以下のような接続方式になっているのでロータリーエンコーダ側はPCに有線接続してもキーボードとして動作しません。  
+ ロータリーエンコーダ側(ペリフェラル) ⇔ (無線接続) ⇔ トラックボール側(セントラル) ⇔ (無線or有線接続) ⇔ PC

なお、このファームウェアではデフォルトでオートマウスレイヤーが**4**、スクロールレイヤーが**5**となっています。

## 6．キーマップの編集

冒頭で書いたようにzmk firmwareの編集にはgithubのアカウントが必要です。  
一からファームウェアを用意する際の手順は[公式ドキュメントの導入解説](https://zmk.dev/docs/user-setup)を見るとわかりやすいです。  
以下では、私が作成したリポジトリをフォークし、[KeymapEditor](https://nickcoutsos.github.io/keymap-editor/)を用いてGUIでキーマップを書き換える手順を紹介します。  

1. githubアカウントを作成し、ログインします。
2. [このリポジトリ](https://github.com/kumamuk-git/zmk-config-roBa)にアクセス
3. 画面右上の「Fork」をクリック

4. そのまま「Create fork」をクリック

5. フォークしたリポジトリの「Actions」タブに移動し、「I understand my workflows, go ahead and enable them」をクリックし、github Actionsを有効化

6. [KeymapEditor](https://nickcoutsos.github.io/keymap-editor/)にアクセス  
7. 「GitHub」を選択
  
8. 「Login with GitHub」からでログインし、「Authorize Keymap Editor」を選択  
9. 指示に従い、フォークしたzmk-config-roBaにKeymap Editorがアクセスできるように進める
10. Keymap Editor上でキーマップが表示されたら、好きにキーマップを編集する
11. 画面左上の「Save」を押すと、編集したキーマップが適用されてGitHub Actionsが走り、自動的にビルドが開始します

12. 「Save」の隣に表示される「Latest」をクリックするとGitHubに移動し、ビルドが完了するとファームウェアがダウンロードできるようになります。  
（ビルドには2～4分かかる場合があります。）
13. [書込み手順](#5-2ファームウェア仮の書込み)に従い、ファームウェアを書き込みます。  
    + キーマップの編集のみの場合はトラックボール側(セントラル)のみを書き換えることで変更が適用されます。  
    リセットファームウェアの書込みも基本的には必要ありません。
    + KeymapEditorを用いずにroBa.keymap以外のファイルの内容を書き換えた場合は、左右のファームウェアを書き換えてください。  
    + ファームウェアを書き直した際は、PC側のペアリング情報も削除してから再度ペアリングを行ってください。
14. 無事に変更したキーマップが適用されていれば成功です。

***※REMAPやVialには対応していません。***

## 7．トラブルシューティング

### bluetoothデバイスとして認識されない or 認識しても接続できない or 接続できたが片側が反応しない
+ [zmk firmware公式のトラブルシューティング](https://zmk.dev/docs/troubleshooting/connection-issues#split-keyboard-halves-unable-to-pair)にあるようにまずはsettings_reset-seeeduino_xiao_ble-zmk.uf2の書込みからやり直すことをお勧めします。  
+ （あまりないと思いますが）マイコン自体に問題がないか確認するため、キーボードに接続しない状態マイコン2個で認識、接続できるかも一応試してみてください。  
### トラックボールが動かない  
+ （あまりないと思いますが）ケースが正しく装着できておらずセンサの読み取り部分が隠れてしまっていないか確認してください。
+ トラックボール読み取り基板とセンサのはんだに不良がないか確認してください。  
  + はんだに失敗しやり直し不可の場合は、センサとトラックボール読み取り基板のみで保守部品としてboothで販売予定ですのでそちらをご利用ください。  
+ settings_reset-seeeduino_xiao_ble-zmk.uf2の書込みからやり直してみることが有効な場合があります。  

### 一部キーが反応しない  
+ はんだ不良、ポゴピンの接触不良、ダイオードの向き、キースイッチが正しくソケットに刺さっているかを確認してください。  

### 充電ができない
+ 電源オフ時にはバッテリーを回路から切り離しているため充電も動作しません。電源をオンの状態で充電を実施してください。

### zmk firmwareについて
このキーボード固有の問題ではなくファームウェアのカスタマイズ等で疑問点がある場合、以下が参考になると思います。  
+ [公式ドキュメント](https://zmk.dev/)
  + かなり丁寧に作りこまれているので基本的な設定はドキュメント見ればわかると思います。
+ [zmk firmware Discordサーバ](https://zmk.dev/community/discord/invite)  
  + 活発に動いているので質問すると誰かしら回答くれることが多いです。

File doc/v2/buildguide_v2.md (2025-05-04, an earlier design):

# Build Guide for roBa

2024/12販売分～

## 目次
  - [1．部品確認](#1部品確認)
    - [1-1．キット内容](#1-1キット内容)
    - [1-2．別途準備が必要な部品](#1-2別途準備が必要な部品)
    - [1-3．オプション](#1-3オプション)
  - [2．準備](#2準備)
    - [2-1．必要な工具](#2-1必要な工具)
    - [2-2．ファームウェア](#2-2ファームウェア)
  - [3．実装](#3実装)
    - [3-1．ダイオードのはんだ付け](#3-1ダイオードのはんだ付け)
    - [3-2．キーソケットのはんだ付け](#3-2キーソケットのはんだ付け)
    - [3-3．スライドスイッチのはんだ付け](#3-3スライドスイッチのはんだ付け)
    - [3-4．マイコンのはんだ付け](#3-4マイコンのはんだ付け)
    - [3-5．コネクタのはんだ付け](#3-5コネクタのはんだ付け)
    - [3-6．L字コンスルーのはんだ付け](#3-6l字コンスルーのはんだ付け)  
    - [3-7．センサのはんだ付け](#3-7センサのはんだ付け)
    - [3-8．ロータリーエンコーダの組み立て](#3-8ロータリーエンコーダの組み立て)
  - [4．組み立て](#4組み立て)
    - [4-1．バッテリーの確認及び取り付け](#4-1バッテリーの確認及び取り付け)
    - [4-2．ケースの組み立て](#4-2ケースの組み立て)
    - [4-3．トラックボール読み取り基板差し込み](#4-3トラックボール読み取り基板差し込み)
    - [4-4．トラックボールケース装着](#4-4トラックボールケース装着)  
    - [4-5．電源スイッチキャップ装着](#4-5電源スイッチキャップ装着)
  - [5．ファームウェア書込み](#5ファームウェアの書込み)
    - [5-1．ファームウェア(仮)のダウンロード](#5-1ファームウェア仮のダウンロード)
    - [5-2．ファームウェア(仮)の書込み](#5-2ファームウェア仮の書込み)
    - [5-3．動作確認](#5-3動作確認)
  - [6．キーマップの編集](#6キーマップの編集)
  - [7．トラブルシューティング](#7トラブルシューティング)

## 1．部品確認

### 1-1．キット内容

| 名前 | 数 | 備考 |
|:-|---:|:-|
| メイン基板(左右) | 1組 | |
| ボトムプレート(左右) | 1組 | 3Dプリント品|
| ケース(左右) | 1組 | 3Dプリント品|
| リセットボタン用スティック | 2本 | 3Dプリント品|
| 電源スイッチキャップ | 2本 | 3Dプリント品|
| トラックボールケース | 1個 | 3Dプリント品|
| Φ2 セラミックボール | 3個 | トラックボールケースに取り付け済み |
| トラックボール読取り基板 | 1枚 | |
| トラックボール読取りセンサ | 1個 | PMW3610|
| 読取りセンサ用レンズ | 1個 | |
| L字コンスルーピン(7ピン) | 1個 | |
| PHコネクタ | 2個 | |
| スライドスイッチ | 2個 | |
| ダイオード（表面実装タイプ）  | 50個 | 予備含む|
| Kailh PCBソケット CherryMX用  | 40個 ||
| Kailh PCBソケット choc用 | 5個 | |
| ネジ M1.7 | 2本 | |
| クッションゴム | 4個 | |  

なお3Dプリントケースは[github](https://github.com/kumamuk-git/roBa/tree/main/case/v2)上で公開しています。  

---ロータリーエンコーダ---
| 名前 | 数 | 備考 |
|:-|---:|:-|
| ロータリーエンコーダ用ハウジング | 1個 | 3Dプリント品|
| ロータリーエンコーダ用ホイール | 1個 | 3Dプリント品|
| ロータリーエンコーダ用ステム | 1個 | 3Dプリント品|
| ロータリーエンコーダ | 1個 | EC05E1220202|
| ロータリーエンコーダ基板 | 1個 | |
| スペーサー M2 3mm | 4本 | |
| ネジ M2 8mm | 4本 |  |
| スプリングピン(ポゴピン) | 1本 | |
| コンスルーピン(3ピン) | 2個 |うち1つは中央のピンが不必要のため取り外しています |

### 1-2．別途準備が必要な部品

| 名前 | 数 | 備考 |参考情報|
|:-|-:|:-|:-|
| Xiao nrf52840 | 2個 |  |[主な購入先](https://akizukidenshi.com/catalog/g/g117341/)|
| CherryMX互換キースイッチ | 37個  |  |
| ロープロファイルキースイッチ  | 5個 |  |
| 直径34mmトラックボール | 1個 |  |[主な購入先](https://www.amazon.co.jp/%E3%81%BA%E3%83%AA%E3%83%83%E3%82%AF%E3%82%B9-PERIPRO-303WH-%E4%BA%A4%E6%8F%9B%E7%94%A8%E3%83%88%E3%83%A9%E3%83%83%E3%82%AF%E3%83%9C%E3%83%B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)|
| Lipoバッテリー(コネクタ付き)  | 2個 | ボトムプレートはL53mm × W23mm × H6mm 以内の大きさに対応 キット付属のコネクタは2mmピッチのJSTコネクタになります。必ず保護回路付きのものを用意してください。|[主な購入先](https://www.amazon.co.jp/EEMB-%E3%83%AA%E3%83%81%E3%82%A6%E3%83%A0%E3%82%A4%E3%82%AA%E3%83%B3-502030%E9%9B%BB%E6%B1%A0250mAh-%E3%83%AA%E3%83%9D%E3%83%90%E3%83%83%E3%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)|
| USB type-Cケーブル | 1本 | ファームウェア書込みと充電に必要 |
| キーキャップ | 37個  | 1u 37個 |
| ロープロファイルキーキャップ  | 5個 | 1u ５個 |
| 両面テープ | - | ボトムプレートへのバッテリーの固定に必要|

※リポバッテリーには発火等の危険性があります。各自購入したバッテリーの注意事項をよく読み、適切に取り扱うよう注意してください。  
　取り扱いの不備により発生した事故等の責任は負いかねます。  
※主な購入先のリンクはアフェリエイトリンクではありません。

### 1-3．オプション
+ ロータリーエンコーダ部分にキーソケットを取り付けキースイッチを取り付けることも可能です。

## 2．準備

### 2-1．必要な工具
| 名前 | 備考 |
|:-|:-|
| はんだごて  | 温度調整可能だと◎|
| はんだ | |
| ピンセット  | |
| ドライバ ||
| マスキングテープ||
| テスター||
| ペンチ||

### 2-2．ファームウェア
Xiao nrf52840へファームウェアの書込みが必要です。  
ビルド済みのファームウェアは[こちら](https://github.com/kumamuk-git/zmk-config-roBa/actions/runs/10759328125)です。  
zmk firmwareを使用しているため、ご自身でファームウェアやキーマップをカスタムされる場合はgithubアカウントが必要になります。  

## 3．実装

### 3-1．ダイオードのはんだ付け
ダイオードは基板裏面（roBaロゴがない面）に実装します。ダイオードは実装の向きがあります。  
ダイオードに薄く書かれている線と基板に印刷された図（以降シルク）にある線が同じ方向になるように取り付けて下さい。  

ダイオード用パッドの片側にはんだを盛ります。  



そしてピンセットでダイオードを掴み、シルクと向きを合わせて事前に盛ったはんだを溶かしつつ位置を合わせます。 

 

およそシルクと同じ位置に決まったら、もう片側もはんだで固定します。



ピンセットでダイオードが取れないことを確認したら取り付け完了です。  
これをすべて(43箇所)に対して行います。

### 3-2．キーソケットのはんだ付け  
キーソケットも基板裏面に実装します。  
親指部分はchoc用のキーソケットを使用してください。  
ダイオードと同様に片方のパッドに事前にはんだを盛ります。  



そして、キーソケットをシルクに合う向きで基板にはめ込みます。  
その状態のまま、キーソケットをピンセットで抑えつつ、事前に盛ったはんだを溶かすとキーソケットが沈み、固定できます。  



固定出来たら、反対側のパッドもはんだで固定します。  



<!--
写真  (ロータリーエンコーダ取り付け部分のソケット)
-->

### 3-3．スライドスイッチのはんだ付け  
このスライドスイッチが電源スイッチとなります。  
スライドスイッチは基板表面に実装します。  



表面からピンを差し込み、マスキングで仮止めします。  



そして裏面から出たピンをはんだ付けし、固定します。  



はんだ付け後、ピンが長い場合はペンチ等で短くカットしても良いかもしれません。  

### 3-4．マイコンのはんだ付け  

v2から基板に直付けになりました。
まずxiao bleを基板の表に重ねます。  
その後、xiao ble付属のピンヘッダをその上から差し込み、xiao bleが基板に対してずれないように固定します。  
(ピンヘッダははんだ付けしないので気をつけてください。)    

    

その状態で、切り欠きの入ったスルーホールがxiao bleの裏面のパッドと重なっていることを確認し、はんだで各パッドとスルーホールを繋ぎます。  
製造の都合上でスルーホールの切り欠き部分が残ってしまっている場合がありますが、無理に取らずにそのままはんだ付けしてください。
無理に取ると断線の可能性があります。（テスト組みでやりました。）  
写真では太い小手先で作業してしまっているのですが、絶対に細い小手先での作業のほうが楽です。  
もしブリッジしてしまった場合ははんだ吸い取り線をスルーホール同士の間に当てたら比較的簡単にジャンパ外れるようです。  
私も一度ブリッジしてしまったのですが、手元に吸い取り線がなかったため、スルーホールに小手先を当てながら基板を逆さにして重力で小手先側へはんだを流し込むというプリミティブ解決をしましたが、危ないので非推奨です。  

  
  

適切にはんだ付けできるとこんな感じになります。



2箇所とも裏面がはんだ出来たらピンヘッダは外してOKです。
続いて表面にし、写真のようにxiaoの各端子の側面と基板のパッドをはんだ付けします。

  

以上でマイコンの取り付け完了です。  

### 3-5．コネクタのはんだ付け  

コネクタは裏面に実装します。  

2本生えている足と側面をはんだ付けで固定します。  



左右各1箇所、計2箇所取り付けます。

### 3-6．L字コンスルーのはんだ付け  

トラックボール読み取り基板を取り付けるためのコンスルーです。  
コンスルーには輪っかになっているピンと1本の直線のピンがありますが、直線のピンのほうを基板へ取り付けます。  
コンスルーは基板表面に実装します。  
表面から差し込み、マスキングテープで仮止めします。



そして、裏面からはんだで固定します。  



トラックボール取り付け側の基板のみ1箇所です。  

### 3-7．センサのはんだ付け  

トラックボール読み取り基板へセンサをはんだ付けします。  
「pmw3610 module」の文字がある面を表面とし、裏面からセンサを差し込みます。  
このとき、向きを間違えないよう写真をよく確認してください。  
裏面に書かれた文字とセンサに書かれた文字の上下が揃っている向きが正しい向きです。 



そして、表面に出たセンサのピンをすべてはんだ付けしていきます。  
センサのデータシートによると**最大260℃**までの温度、**7秒以内**でのはんだづけが推奨されています。  
これ以上高い温度または長時間での作業はセンサの故障につながる恐れがありますので注意してください。  
とはいえ焦って作業するのも良くないので適度に冷ましつつ落ち着いて作業してください。

+ ランドの面積が小さいので、はんだを盛りすぎてピンがブリッジしてしまわないように注意してください。  
個人的に手前のピンから順にはんだ付けしていくほうが失敗がなさそうです。

+ また、はんだ不良によりセンサが動作しない場合もありますので、  
センサが動作しない場合は、まず、この部分のはんだに不良がないか確認するとよいです。  
基板の接続は以下のようになっていますので参考にしてください。



はんだづけが完了したら保護シールをはがしてください。



センサの取り付けが完了したら、レンズを装着してください。 



### 3-8．ロータリーエンコーダの組み立て  
以前採用していた水平ロータリーエンコーダの入手性が悪すぎたので、いい感じのを作りました。  
  

まず、つながっている基板を切り離します。
カッターで切れ目をひっかき、その後、丁寧に折ると割れます。

    

つなぎ目の不要な部分が残ってしまうと思うのでこれはペンチ等ではさんでおりましょう。

  

切れ目がとがってしまうので気になる方はやすって平らにしてください。  
私は見えなかったことにしました。  
そして下側となる基板（中央に穴のないほう）にポゴピンを1本付けます。  
分かりづらいですが、切り離す前に部品がついていたほうが表になります。  
表面に対して、上からポゴピンを差し込みます。
マステ等で固定して、裏からはんだ付けがいいかな思います。  

***↓これが表面です。***

<!-- ![alt text](../img/koro3.JPG) -->

続いて裏面から8mmのネジで3mmスペーサーを固定します。  
このスペーサーが上下基板を繋ぐ導体になります。

<!-- ![alt text](../img/koro4.JPG)   -->

そして写真のようにコンスルーを取り付けます。  

※※※  
***キット付属のコンスルーは現状私がカットしており、カットミスで2pin側のコンスルーが1pin×2個になってしまっているものがあります。***  
***取り付けにくい場合は切断面をやすりで削る等対応いただけるとありがたいです。***



続いて上側の基板です。  
写真のようにロータリーエンコーダを置き、はんだで固定します。  
エンコーダ側面からはんだ付けすると楽かと思います。  
***端子部分ははんだ不良が起きやすいので、端子を小手でパッド側に押し付けつつ温めてはんだを流し込むようにすると良さそうです。***  
なのでここも細かい小手先がいいですね。  
エンコーダが動かない場合の原因は十中八九これです。  
きれいにはんだ出来ているように見えてもここを疑ってください。



エンコーダにホイールとステムを取り付けます。  
まず、ホイールを置き、そしてスイッチ側からホイールの穴を通す形でステムを入れ込み、
ステムの先端をロータリーエンコーダに差し込んでください。  
ここで無理に押し込むとステムが折れてしまいます。  
***ステムの先端と、エンコーダーの穴がそれぞれ六角形になっているので、向きが合うのを確認してから慎重に差し込んでください。***



そして上からハウジングをかぶせます。
ハウジングの細かいサポート材が取り切れていないときれいに嵌らない場合があるので、もし取り残しがあればピンセットなどで取り除いてください。  



上下を取り付けます。
タクトスイッチ裏のパッドにポゴピンが当たるような向きにして、ネジをハウジングに差し込み固定してください。  
この際に固定が緩いと上下の基板の接続不良となってしまうため、しっかりと固定してください。


  
↑隙間がなくなるまでネジを締めてください。

以上で組み立て完了です。  
コンスルーを基板に差し込み取り付けてください。
なお、コンスルーの差し込みのみでの固定なので若干ぐらつきがあります。
気になる場合は交換不可になりますが、基板にはんだで固定してしまってもよいかもしれません。

+ メイン基板の裏に出ているピンははんだしないことでロータリーエンコーダを後から外し、キースイッチに取り換えることができます。

以上ですべてのはんだ付けが終了です。腰が丸まったと思うので背伸びしておいてください。お疲れ様でした。

なお、この時点で、[手順4-4](#4-4トラックボール読み取り基板差し込み)、[手順5](#5ファームウェアの書込み)あたりを行い、動作確認をしてしまうと組み立て後の後戻りが少なく楽かもしれません。

## 4．組み立て

### 4-1．バッテリーの確認及び取り付け

  
バッテリーの極性を確認してください。  
図のように裏面、USBが上になるような向きでバッテリーの銅線の赤い線が左に来ていれば極性は問題ないです。
（この極性がわりとマイナーなことを後から知りました。。。）  
極性が逆のものを取り付けてしまわないよう注意してください。  

裏面のバッテリー用コネクタにバッテリーを差し込みます。  

 

続いてバッテリーの裏に両面テープを貼り、ボトムプレートへ固定してください。  
いい感じのスチールプレートをボトムプレート内に張り付けるとテンティング用にいいかもですね。

### 4-2．ケースの組み立て

リセットスティックをケースの裏から差し込みます。
このスティックを介してマイコンのリセットボタンを押せるようにしています。 
(写真のスティックはv1のものなのでv2のものより短いです。) 



↓試作で自分用に印刷したやつなので色が異なってます



リセットスティックが落ちないように気を付けつつ、ケースの裏に基板を配置します。  



この時USB端子の位置がちょうどよい位置に来るように調整してください。



手で基板を裏から抑えつつ、四隅にスイッチを差し込み、ケースと基板を固定します。



ケースと基板が固定出来たら、ボトムプレートを取り付けます。  
ケースの底面内側に小さなツメが前後にあるので、ボトムプレートのくぼみがそこに嵌るようにまず片側を押し込みます。

  

片側を合わせることができたらもう片側もくぼみにツメが嵌るように押し込みます。



### 4-3．トラックボール読み取り基板差し込み

メイン基板のL字コンスルーにトラックボール読み取り基板を差し込みます。  



### 4-4．トラックボールケース装着

トラックボール読み取り基板を取り付け後、トラックボールケースを上から差し込み、ボトムプレート裏からM1.7ネジで固定します。





### 4-5．電源スイッチキャップ装着



電源スイッチキャップをスライドスイッチに差し込みます。
緩いと感じる場合はラップの破片など挟むとよい滑り止めになるかもしれません。

左右ともに手前がオフ、奥がオンになります。

以上で組み立て完了です。
あとはお好みでキースイッチ、キーキャップを取り付けてください。
お疲れ様でした！

## 5．ファームウェアの書込み

### 5-1．ファームウェア(仮)のダウンロード

(仮)としているのは、いずれキーマップをカスタマイズする際に現状ファームウェア自体を変更し、書込み直す必要があるためです。  
（zmk studioというプロジェクトが進んでいて、いずれファームウェアの変更なしにキーマップのみGUIで編集できるようになるらしいです。やったね。）

[こちら](https://drive.google.com/file/d/10D3QgOOYa3G7XiFyVIoovQ7wt79W96s5/view?usp=sharing)からzipファイルをダウンロードしてください。  

解凍すると以下の3つの.uf2ファイルが入っています。  
+ settings_reset-seeeduino_xiao_ble-zmk.uf2
+ roBa_L-seeeduino_xiao_ble-zmk.uf2
+ roBa_R-seeeduino_xiao_ble-zmk.uf2

### 5-2．ファームウェア(仮)の書込み
settings_reset-seeeduino_xiao_ble-zmk.uf2は[ここ](https://zmk.dev/docs/troubleshooting/connection-issues#split-keyboard-halves-unable-to-pair)にあるように分割キーボードのペアリングに関する問題を解決するための設定初期化用のファームウェアです。

1. PCと左側のマイコンをUSBで接続します。はじめはキーボードの電源はオフで大丈夫です。
2. マイコンのリセットボタンを2回押すと、「XIAO SENSE」という名前でUSBドライブとして認識されるかと思います。 (ブートローダの起動)
3. 「XIAO SENSE」ドライブにsettings_reset-seeeduino_xiao_ble-zmk.uf2をドラッグアンドドロップします。  
※MacOSの場合、以下のようなエラーが出るようですが無視して進めて問題なく、実際には書込みができているとのことです。 (画像提供：shakupanさん)

4. 書込み完了すると、「XIAO SENSE」というドライブは消えますが、再度セットボタンを2回押し、ブートローダを起動します。  
5. 「XIAO SENSE」ドライブにroBa_L-seeeduino_xiao_ble-zmk.uf2をドラッグアンドドロップします。  
6. 右側も同様の手順でsettings_reset-seeeduino_xiao_ble-zmk.uf2とroBa_R-seeeduino_xiao_ble-zmk.uf2を順番に書き込みます。
7. 両方の書込みが完了したら、電源を入れ、それぞれのマイコンのリセットボタンを**1回**押します。
8. PCでbluetoothデバイスとして「roBa」が認識され接続できればOKです。  

### 5-3．動作確認

bluetooth接続が完了したらすべてのキーが認識するか、ロータリーエンコーダ、トラックボールが問題なく動作するか確認しましょう。  
左右間のペアリングは電源を入れると自動的に行われます。  
有線接続でも動作しますが、左右間は無線接続のみになります。  
ファームウェア(仮) では以下のような接続方式になっているのでロータリーエンコーダ側はPCに有線接続してもキーボードとして動作しません。  
+ ロータリーエンコーダ側(ペリフェラル) ⇔ (無線接続) ⇔ トラックボール側(セントラル) ⇔ (無線or有線接続) ⇔ PC

なお、このファームウェアではデフォルトでオートマウスレイヤーが**4**、スクロールレイヤーが**5**となっています。

## 6．キーマップの編集
***※REMAPやVialには対応していません。***

冒頭で書いたようにzmk firmwareの編集にはgithubのアカウントが必要です。  
一からファームウェアを用意する際の手順は[公式ドキュメントの導入解説](https://zmk.dev/docs/user-setup)を見るとわかりやすいです。  
以下では、私が作成したリポジトリをフォークし、[KeymapEditor](https://nickcoutsos.github.io/keymap-editor/)を用いてGUIでキーマップを書き換える手順を紹介します。  

1. githubアカウントを作成し、ログインします。
2. [このリポジトリ](https://github.com/kumamuk-git/zmk-config-roBa)にアクセス
3. 画面右上の「Fork」をクリック

4. そのまま「Create fork」をクリック

5. フォークしたリポジトリの「Actions」タブに移動し、「I understand my workflows, go ahead and enable them」をクリックし、github Actionsを有効化

6. [KeymapEditor](https://nickcoutsos.github.io/keymap-editor/)にアクセス  
7. 「GitHub」を選択
  
8. 「Login with GitHub」からでログインし、「Authorize Keymap Editor」を選択  
9. 指示に従い、フォークしたzmk-config-roBaにKeymap Editorがアクセスできるように進める
10. Keymap Editor上でキーマップが表示されたら、好きにキーマップを編集する
11. 画面左上の「Save」を押すと、編集したキーマップが適用されてGitHub Actionsが走り、自動的にビルドが開始します

12. 「Save」の隣に表示される「Latest」をクリックするとGitHubに移動し、ビルドが完了するとファームウェアがダウンロードできるようになります。  
（ビルドには2～4分かかる場合があります。）
13. [書込み手順](#5-2ファームウェア仮の書込み)に従い、ファームウェアを書き込みます。  
    + キーマップの編集のみの場合はトラックボール側(セントラル)のみを書き換えることで変更が適用されます。  
    リセットファームウェアの書込みも基本的には必要ありません。
    + KeymapEditorを用いずにroBa.keymap以外のファイルの内容を書き換えた場合は、左右のファームウェアを書き換えてください。  
    + ファームウェアを書き直した際は、PC側のペアリング情報も削除してから再度ペアリングを行ってください。
14. 無事に変更したキーマップが適用されていれば成功です。

### 番外編
+ トラボの上下左右操作にキー入力を割り当てる
kotさんのおかげで以下でトラックボールの上下左右操作にキー入力を割り当てることができるようになります。  
kotさんありがとうございます。  
#### 基本
roBa_R.overlayのtrackball: trackball@0内に以下を書き加えます。  
レイヤー3で矢印キー入力、レイヤー2で音量調整を行う設定を例に示します。
roBa_R.overlayに書き加える方法だとbindingsとしてマクロキーを設定することはできません。
```c:roBa_R.overlay

↓追記
#include <dt-bindings/zmk/keys.h>

trackball: trackball@0 {
    //////////
    ...
    //////////
    // automouse-layer = <MOUSE>;
    // scroll-layers = <SCROLL>;
    // snipe-layers = <3>;

    ↓追記

    arrows {
        layers = <3>;
        bindings =
            <&kp RIGHT_ARROW>,
            <&kp LEFT_ARROW>,
            <&kp UP_ARROW>,
            <&kp DOWN_ARROW>;

        tick = <10>;
        wait-ms = <5>;
        tap-ms = <5>;
    };

    volume {
        layers = <2>;
        bindings =
                <&none>,
                <&none>,
                <&kp C_VOLUME_UP>,
                <&kp C_VOLUME_DOWN>;

        wait-ms = <5>;
        tap-ms = <5>;
    };
};
```
#### 応用
ファイル構成が変わるので上級者向けです。  
こちらの方法でマクロキーもトラックボール動作に割り当てることができるようになります。  
実装の詳細はこちらの[PR](https://github.com/kumamuk-git/zmk-config-roBa/pull/11)を参考にしてください。  

## 7．トラブルシューティング

### bluetoothデバイスとして認識されない or 認識しても接続できない or 接続できたが片側が反応しない
+ [zmk firmware公式のトラブルシューティング](https://zmk.dev/docs/troubleshooting/connection-issues#split-keyboard-halves-unable-to-pair)にあるようにまずはsettings_reset-seeeduino_xiao_ble-zmk.uf2の書込みからやり直すことをお勧めします。  
+ （あまりないと思いますが）マイコン自体に問題がないか確認するため、キーボードに接続しない状態マイコン2個で認識、接続できるかも一応試してみてください。  
### トラックボールが動かない  
+ （あまりないと思いますが）ケースが正しく装着できておらずセンサの読み取り部分が隠れてしまっていないか確認してください。
+ トラックボール読み取り基板とセンサのはんだに不良がないか確認してください。  
  + はんだに失敗しやり直し不可の場合は、センサとトラックボール読み取り基板のみで保守部品としてboothで販売予定ですのでそちらをご利用ください。  
+ settings_reset-seeeduino_xiao_ble-zmk.uf2の書込みからやり直してみることが有効な場合があります。  

### 一部キーが反応しない  
+ はんだ不良、ポゴピンの接触不良、ダイオードの向き、キースイッチが正しくソケットに刺さっているかを確認してください。  

### 充電ができない
+ 電源オフ時にはバッテリーを回路から切り離しているため充電も動作しません。電源をオンの状態で充電を実施してください。

### zmk firmwareについて
このキーボード固有の問題ではなくファームウェアのカスタマイズ等で疑問点がある場合、以下が参考になると思います。  
+ [公式ドキュメント](https://zmk.dev/)
  + かなり丁寧に作りこまれているので基本的な設定はドキュメント見ればわかると思います。
+ [zmk firmware Discordサーバ](https://zmk.dev/community/discord/invite)  
  + 活発に動いているので質問すると誰かしら回答くれることが多いです。

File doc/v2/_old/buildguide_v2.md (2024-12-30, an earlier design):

# Build Guide for roBa

2024/11販売分

## 目次
  - [1．部品確認](#1部品確認)
    - [1-1．キット内容](#1-1キット内容)
    - [1-2．別途準備が必要な部品](#1-2別途準備が必要な部品)
    - [1-3．オプション](#1-3オプション)
  - [2．準備](#2準備)
    - [2-1．必要な工具](#2-1必要な工具)
    - [2-2．ファームウェア](#2-2ファームウェア)
  - [3．実装](#3実装)
    - [3-1．ダイオードのはんだ付け](#3-1ダイオードのはんだ付け)
    - [3-2．キーソケットのはんだ付け](#3-2キーソケットのはんだ付け)
    - [3-3．スライドスイッチのはんだ付け](#3-3スライドスイッチのはんだ付け)
    - [3-4．マイコンのはんだ付け](#3-4マイコンのはんだ付け)
    - [3-5．コネクタのはんだ付け](#3-5コネクタのはんだ付け)
    - [3-6．L字コンスルーのはんだ付け](#3-6l字コンスルーのはんだ付け)  
    - [3-7．センサのはんだ付け](#3-7センサのはんだ付け)
    - [3-8．ロータリーエンコーダの組み立て](#3-8ロータリーエンコーダの組み立て)
  - [4．組み立て](#4組み立て)
    - [4-1．バッテリーの取り付け](#4-1バッテリーの取り付け)
    - [4-2．ケースとトッププレートの取り付け](#4-2ケースとトッププレートの組み立て)
    - [4-3．ボトムプレートの取り付け](#4-3ボトムプレートの組み立て)
    - [4-4．トラックボール読み取り基板差し込み](#4-4トラックボール読み取り基板差し込み)
    - [4-5．トラックボールケース装着](#4-5トラックボールケース装着)  
    - [4-6．電源スイッチキャップ装着](#4-6電源スイッチキャップ装着)
  - [5．ファームウェア書込み](#5ファームウェアの書込み)
    - [5-1．ファームウェア(仮)のダウンロード](#5-1ファームウェア仮のダウンロード)
    - [5-2．ファームウェア(仮)の書込み](#5-2ファームウェア仮の書込み)
    - [5-3．動作確認](#5-3動作確認)
  - [6．キーマップの編集](#6キーマップの編集)
  - [7．トラブルシューティング](#7トラブルシューティング)

## 1．部品確認

### 1-1．キット内容

| 名前 | 数 | 備考 |
|:-|---:|:-|
| メイン基板(左右) | 1組 | |
| トッププレート(左右) | 1組 |メインと親指部のセット 3Dプリント品 |
| ボトムプレート(左右) | 1組 | 3Dプリント品|
| ケース(左右) | 1組 | 3Dプリント品|
| リセットボタン用スティック | 2本 | 3Dプリント品|
| 電源スイッチキャップ | 2本 | 3Dプリント品|
| トラックボールケース | 1個 | 3Dプリント品|
| Φ2 セラミックボール | 3個 | トラックボールケースに取り付け済み |
| トラックボール読取り基板 | 1枚 | |
| トラックボール読取りセンサ | 1個 | PMW3610|
| 読取りセンサ用レンズ | 1個 | |
| L字コンスルーピン(7ピン) | 1個 | |
| PHコネクタ | 2個 | |
| スライドスイッチ | 2個 | |
| ダイオード（表面実装タイプ）  | 50個 | 予備含む|
| Kailh PCBソケット CherryMX用  | 40個 ||
| Kailh PCBソケット choc用 | 5個 | |
| スペーサー M2 7mm | 10本 | |
| スペーサー M2 4mm | 3本 | |
| ネジ M2 3.5mm | 28本 | 予備含む |
| ネジ M1.7 | 2本 | |
| クッションゴム | 4個 | |  

なお3Dプリントケースは[github](https://github.com/kumamuk-git/roBa/tree/main/case/v2)上で公開しています。  

---ロータリーエンコーダ---
| 名前 | 数 | 備考 |
|:-|---:|:-|
| ロータリーエンコーダ用ハウジング | 1個 | 3Dプリント品|
| ロータリーエンコーダ用ホイール | 1個 | 3Dプリント品|
| ロータリーエンコーダ用ステム | 1個 | 3Dプリント品|
| ロータリーエンコーダ | 1個 | EC05E1220202|
| ロータリーエンコーダ基板 | 1個 | |
| スペーサー M2 3mm | 4本 | |
| ネジ M2 8mm | 4本 |  |
| スプリングピン(ポゴピン) | 1本 | |
| コンスルーピン(3ピン) | 2個 |うち1つは中央のピンが不必要のため取り外しています |

### 1-2．別途準備が必要な部品

| 名前 | 数 | 備考 |参考情報|
|:-|-:|:-|:-|
| Xiao nrf52840 | 2個 |  |[主な購入先](https://akizukidenshi.com/catalog/g/g117341/)|
| CherryMX互換キースイッチ | 37個  |  |
| ロープロファイルキースイッチ  | 5個 |  |
| 直径34mmトラックボール | 1個 |  |[主な購入先](https://www.amazon.co.jp/%E3%81%BA%E3%83%AA%E3%83%83%E3%82%AF%E3%82%B9-PERIPRO-303WH-%E4%BA%A4%E6%8F%9B%E7%94%A8%E3%83%88%E3%83%A9%E3%83%83%E3%82%AF%E3%83%9C%E3%83%B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)|
| Lipoバッテリー(コネクタ付き)  | 2個 | ボトムプレートはL53mm × H23mm × H6mm 以内の大きさに対応 キット付属のコネクタは2mmピッチのJSTコネクタになります|[主な購入先](https://www.amazon.co.jp/gp/product/B09DPNZM31/ref=ppx_yo_dt_b_asin_title_o01_s00?ie=UTF8&th=1)|
| USB type-Cケーブル | 1本 | ファームウェア書込みと充電に必要 |
| キーキャップ | 37個  | 1u 37個 |
| ロープロファイルキーキャップ  | 5個 | 1u ５個 |
| 両面テープ | - | ボトムプレートへのバッテリーの固定に必要|

※リポバッテリーには発火等の危険性があります。各自購入したバッテリーの注意事項をよく読み、適切に取り扱うよう注意してください。  
　取り扱いの不備により発生した事故等の責任は負いかねます。  
※主な購入先のリンクはアフェリエイトリンクではありません。

### 1-3．オプション
+ ロータリーエンコーダ部分にキーソケットを取り付けキースイッチを取り付けることも可能です。
+ ボトムプレートに直径4cmの円形のスペースを設けています。ステンレスプレートなどを仕込むことが可能です。

## 2．準備

### 2-1．必要な工具
| 名前 | 備考 |
|:-|:-|
| はんだごて  | 温度調整可能だと◎|
| はんだ | |
| ピンセット  | |
| ドライバ ||
| マスキングテープ||
| テスター||
| ペンチ||

### 2-2．ファームウェア
Xiao nrf52840へファームウェアの書込みが必要です。  
ビルド済みのファームウェアは[こちら](https://github.com/kumamuk-git/zmk-config-roBa/actions/runs/10759328125)です。  
zmk firmwareを使用しているため、ご自身でファームウェアやキーマップをカスタムされる場合はgithubアカウントが必要になります。  

## 3．実装

### 3-1．ダイオードのはんだ付け
ダイオードは基板裏面（roBaロゴがない面）に実装します。ダイオードは実装の向きがあります。  
ダイオードに薄く書かれている線と基板に印刷された図（以降シルク）にある線が同じ方向になるように取り付けて下さい。  

ダイオード用パッドの片側にはんだを盛ります。  



そしてピンセットでダイオードを掴み、シルクと向きを合わせて事前に盛ったはんだを溶かしつつ位置を合わせます。 

 

およそシルクと同じ位置に決まったら、もう片側もはんだで固定します。



ピンセットでダイオードが取れないことを確認したら取り付け完了です。  
これをすべて(43箇所)に対して行います。

### 3-2．キーソケットのはんだ付け  
キーソケットも基板裏面に実装します。  
親指部分はchoc用のキーソケットを使用してください。  
ダイオードと同様に片方のパッドに事前にはんだを盛ります。  



そして、キーソケットをシルクに合う向きで基板にはめ込みます。  
その状態のまま、キーソケットをピンセットで抑えつつ、事前に盛ったはんだを溶かすとキーソケットが沈み、固定できます。  



固定出来たら、反対側のパッドもはんだで固定します。  



<!--
写真  (ロータリーエンコーダ取り付け部分のソケット)
-->

### 3-3．スライドスイッチのはんだ付け  
このスライドスイッチが電源スイッチとなります。  
スライドスイッチは基板表面に実装します。  



表面からピンを差し込み、マスキングで仮止めします。  



そして裏面から出たピンをはんだ付けし、固定します。  



はんだ付け後、ピンが長い場合はペンチ等で短くカットしても良いかもしれません。  

### 3-4．マイコンのはんだ付け  

v2から基板に直付けになりました。
まずxiao bleを基板の表に重ねます。  
その後、xiao ble付属のピンヘッダをその上から差し込み、xiao bleが基板に対してずれないように固定します。  
(ピンヘッダははんだ付けしないので気をつけてください。)    

    

その状態で、切り欠きの入ったスルーホールがxiao bleの裏面のパッドと重なっていることを確認し、はんだで各パッドとスルーホールを繋ぎます。  
製造の都合上でスルーホールの切り欠き部分が残ってしまっている場合がありますが、無理に取らずにそのままはんだ付けしてください。
無理に取ると断線の可能性があります。（テスト組みでやりました。）  
写真では太い小手先で作業してしまっているのですが、絶対に細い小手先での作業のほうが楽です。  
もしブリッジしてしまった場合ははんだ吸い取り線をスルーホール同士の間に当てたら比較的簡単にジャンパ外れるようです。  
私も一度ブリッジしてしまったのですが、手元に吸い取り線がなかったため、スルーホールに小手先を当てながら基板を逆さにして重力で小手先側へはんだを流し込むというプリミティブ解決をしましたが、危ないので非推奨です。  

  
  

適切にはんだ付けできるとこんな感じになります。



2箇所とも裏面がはんだ出来たらピンヘッダは外してOKです。
続いて表面にし、写真のようにxiaoの各端子の側面と基板のパッドをはんだ付けします。

  

以上でマイコンの取り付け完了です。  

### 3-5．コネクタのはんだ付け  

コネクタは裏面に実装します。  

2本生えている足と側面をはんだ付けで固定します。  



左右各1箇所、計2箇所取り付けます。

### 3-6．L字コンスルーのはんだ付け  

トラックボール読み取り基板を取り付けるためのコンスルーです。  
コンスルーには輪っかになっているピンと1本の直線のピンがありますが、直線のピンのほうを基板へ取り付けます。  
コンスルーは基板表面に実装します。  
表面から差し込み、マスキングテープで仮止めします。



そして、裏面からはんだで固定します。  



トラックボール取り付け側の基板のみ1箇所です。  

### 3-7．センサのはんだ付け  

トラックボール読み取り基板へセンサをはんだ付けします。  
「pmw3610 module」の文字がある面を表面とし、裏面からセンサを差し込みます。  
このとき、向きを間違えないよう写真をよく確認してください。  
裏面に書かれた文字とセンサに書かれた文字の上下が揃っている向きが正しい向きです。 



そして、表面に出たセンサのピンをすべてはんだ付けしていきます。  
センサのデータシートによると**最大260℃**までの温度、**7秒以内**でのはんだづけが推奨されています。  
これ以上高い温度または長時間での作業はセンサの故障につながる恐れがありますので注意してください。  
とはいえ焦って作業するのも良くないので適度に冷ましつつ落ち着いて作業してください。

+ ランドの面積が小さいので、はんだを盛りすぎてピンがブリッジしてしまわないように注意してください。  
個人的に手前のピンから順にはんだ付けしていくほうが失敗がなさそうです。

+ また、はんだ不良によりセンサが動作しない場合もありますので、  
センサが動作しない場合は、まず、この部分のはんだに不良がないか確認するとよいです。  
基板の接続は以下のようになっていますので参考にしてください。



はんだづけが完了したら保護シールをはがしてください。



センサの取り付けが完了したら、レンズを装着してください。 



### 3-8．ロータリーエンコーダの組み立て  
以前採用していた水平ロータリーエンコーダの入手性が悪すぎたので、いい感じのを作りました。  
  

まず、つながっている基板を切り離します。
カッターで切れ目をひっかき、その後、丁寧に折ると割れます。

    

つなぎ目の不要な部分が残ってしまうと思うのでこれはペンチ等ではさんでおりましょう。

  

切れ目がとがってしまうので気になる方はやすって平らにしてください。  
私は見えなかったことにしました。  
そして下側となる基板（中央に穴のないほう）にポゴピンを1本付けます。  
分かりづらいですが、切り離す前に部品がついていたほうが表になります。  
表面に対して、上からポゴピンを差し込みます。
マステ等で固定して、裏からはんだ付けがいいかな思います。  

***↓これが表面です。***

<!-- ![alt text](../../img/koro3.JPG) -->

続いて裏面から8mmのネジで3mmスペーサーを固定します。  
このスペーサーが上下基板を繋ぐ導体になります。

<!-- ![alt text](../../img/koro4.JPG)   -->

そして写真のようにコンスルーを取り付けます。  

※※※  
***キット付属のコンスルーは現状私がカットしており、カットミスで2pin側のコンスルーが1pin×2個になってしまっているものがあります。***  
***取り付けにくい場合は切断面をやすりで削る等対応いただけるとありがたいです。***



続いて上側の基板です。  
写真のようにロータリーエンコーダを置き、はんだで固定します。  
エンコーダ側面からはんだ付けすると楽かと思います。  
***端子部分ははんだ不良が起きやすいので、端子を小手でパッド側に押し付けつつ温めてはんだを流し込むようにすると良さそうです。***  
なのでここも細かい小手先がいいですね。  
エンコーダが動かない場合の原因は十中八九これです。  
きれいにはんだ出来ているように見えてもここを疑ってください。



エンコーダにホイールとステムを取り付けます。  
まず、ホイールを置き、そしてスイッチ側からホイールの穴を通す形でステムを入れ込み、
ステムの先端をロータリーエンコーダに差し込んでください。  
ここで無理に押し込むとステムが折れてしまいます。  
***ステムの先端と、エンコーダーの穴がそれぞれ六角形になっているので、向きが合うのを確認してから慎重に差し込んでください。***



そして上からハウジングをかぶせます。
ハウジングの細かいサポート材が取り切れていないときれいに嵌らない場合があるので、もし取り残しがあればピンセットなどで取り除いてください。  



上下を取り付けます。
タクトスイッチ裏のパッドにポゴピンが当たるような向きにして、ネジをハウジングに差し込み固定してください。  
この際に固定が緩いと上下の基板の接続不良となってしまうため、しっかりと固定してください。


  
↑隙間がなくなるまでネジを締めてください。

以上で組み立て完了です。  
コンスルーを基板に差し込み取り付けてください。
なお、コンスルーの差し込みのみでの固定なので若干ぐらつきがあります。
気になる場合は交換不可になりますが、基板にはんだで固定してしまってもよいかもしれません。

+ メイン基板の裏に出ているピンははんだしないことでロータリーエンコーダを後から外し、キースイッチに取り換えることができます。

以上ですべてのはんだ付けが終了です。腰が丸まったと思うので背伸びしておいてください。お疲れ様でした。

なお、この時点で、[手順4-4](#4-4トラックボール読み取り基板差し込み)、[手順5](#5ファームウェアの書込み)あたりを行い、動作確認をしてしまうと組み立て後の後戻りが少なく楽かもしれません。

## 4．組み立て

### 4-1．バッテリーの取り付け

裏面のバッテリー用コネクタにバッテリーを差し込みます。  
裏面、USBが上になるような向きでバッテリーの銅線の赤い線が左に来ていれば極性は問題ないです。
購入したバッテリが合っているかを確認し取り付けてください。

### 4-2．ケースとトッププレートの取り付け

メイン基板の上にケースを乗せます。  
この時、ケースのマイコン上部にある穴にリセットボタン用スティックを差し込みます。  
このスティックを介してマイコンのリセットボタンを押せるようにしています。 
(写真のスティックはv1のものなのでv2のものより短いです。) 



↓すいませんこの写真v1ので若干v2と異なります。
v2はバッテリーコネクタが裏面になります。


続いてトッププレートにスペーサをねじ止めします。
親指部分に4mmスペーサを使用します。他は7mmスペーサを使用します。



そして、ケースの上からトッププレートを乗せます。  
トッププレートとメイン基板で挟み込みケースを固定する構造になっています。  
トッププレートとメイン基板の間は空洞になっていますが、お好みでポロンシートなど仕込むと打鍵音にいい影響があるかもしれません。 



### 4-3．ボトムプレートの取り付け
※v2のケースからトレー形状になりバッテリー用のくぼみはなくなってます。
（印刷時間短縮のため）
↓


場合によってはボトムプレートに先にスペーサーを取り付けたほうが組み立てやすかったりしますので、その辺りは試してみてください。

この時バッテリーの裏に両面テープを貼り、ケースへ固定してください。  
いい感じのスチールプレートをボトムプレート内に張り付けるとテンティング用にいいかもですね。

打鍵音を気にする方は、メイン基板の裏にマスキングテープを張っておくと打鍵音が多少良くなります。

バッテリーを収納することができたら、ケース裏にボトムプレートをはめ込みます。  
そして、裏からM2ネジで固定します。



### 4-4．トラックボール読み取り基板差し込み

メイン基板のL字コンスルーにトラックボール読み取り基板を差し込みます。  



### 4-5．トラックボールケース装着

トラックボール読み取り基板を取り付け後、トラックボールケースを上から差し込み、ボトムプレート裏からM1.7ネジで固定します。





### 4-6．電源スイッチキャップ装着



電源スイッチキャップをスライドスイッチに差し込みます。
緩いと感じる場合はラップの破片など挟むとよい滑り止めになるかもしれません。

左右ともに手前がオフ、奥がオンになります。

以上で組み立て完了です。
あとはお好みでキースイッチ、キーキャップを取り付けてください。
お疲れ様でした！

## 5．ファームウェアの書込み

### 5-1．ファームウェア(仮)のダウンロード

(仮)としているのは、いずれキーマップをカスタマイズする際に現状ファームウェア自体を変更し、書込み直す必要があるためです。  
（zmk studioというプロジェクトが進んでいて、いずれファームウェアの変更なしにキーマップのみGUIで編集できるようになるらしいです。やったね。）

[こちら](https://drive.google.com/file/d/10D3QgOOYa3G7XiFyVIoovQ7wt79W96s5/view?usp=sharing)からzipファイルをダウンロードしてください。  

解凍すると以下の3つの.uf2ファイルが入っています。  
+ settings_reset-seeeduino_xiao_ble-zmk.uf2
+ roBa_L-seeeduino_xiao_ble-zmk.uf2
+ roBa_R-seeeduino_xiao_ble-zmk.uf2

### 5-2．ファームウェア(仮)の書込み
settings_reset-seeeduino_xiao_ble-zmk.uf2は[ここ](https://zmk.dev/docs/troubleshooting/connection-issues#split-keyboard-halves-unable-to-pair)にあるように分割キーボードのペアリングに関する問題を解決するための設定初期化用のファームウェアです。

1. PCと左側のマイコンをUSBで接続します。はじめはキーボードの電源はオフで大丈夫です。
2. マイコンのリセットボタンを2回押すと、「XIAO SENSE」という名前でUSBドライブとして認識されるかと思います。 (ブートローダの起動)
3. 「XIAO SENSE」ドライブにsettings_reset-seeeduino_xiao_ble-zmk.uf2をドラッグアンドドロップします。  
※MacOSの場合、以下のようなエラーが出るようですが無視して進めて問題なく、実際には書込みができているとのことです。 (画像提供：shakupanさん)

4. 書込み完了すると、「XIAO SENSE」というドライブは消えますが、再度セットボタンを2回押し、ブートローダを起動します。  
5. 「XIAO SENSE」ドライブにroBa_L-seeeduino_xiao_ble-zmk.uf2をドラッグアンドドロップします。  
6. 右側も同様の手順でsettings_reset-seeeduino_xiao_ble-zmk.uf2とroBa_R-seeeduino_xiao_ble-zmk.uf2を順番に書き込みます。
7. 両方の書込みが完了したら、電源を入れ、それぞれのマイコンのリセットボタンを**1回**押します。
8. PCでbluetoothデバイスとして「roBa」が認識され接続できればOKです。  

### 5-3．動作確認

bluetooth接続が完了したらすべてのキーが認識するか、ロータリーエンコーダ、トラックボールが問題なく動作するか確認しましょう。  
左右間のペアリングは電源を入れると自動的に行われます。  
有線接続でも動作しますが、左右間は無線接続のみになります。  
ファームウェア(仮) では以下のような接続方式になっているのでロータリーエンコーダ側はPCに有線接続してもキーボードとして動作しません。  
+ ロータリーエンコーダ側(ペリフェラル) ⇔ (無線接続) ⇔ トラックボール側(セントラル) ⇔ (無線or有線接続) ⇔ PC

なお、このファームウェアではデフォルトでオートマウスレイヤーが**4**、スクロールレイヤーが**5**となっています。

## 6．キーマップの編集

冒頭で書いたようにzmk firmwareの編集にはgithubのアカウントが必要です。  
一からファームウェアを用意する際の手順は[公式ドキュメントの導入解説](https://zmk.dev/docs/user-setup)を見るとわかりやすいです。  
以下では、私が作成したリポジトリをフォークし、[KeymapEditor](https://nickcoutsos.github.io/keymap-editor/)を用いてGUIでキーマップを書き換える手順を紹介します。  

1. githubアカウントを作成し、ログインします。
2. [このリポジトリ](https://github.com/kumamuk-git/zmk-config-roBa)にアクセス
3. 画面右上の「Fork」をクリック

4. そのまま「Create fork」をクリック

5. フォークしたリポジトリの「Actions」タブに移動し、「I understand my workflows, go ahead and enable them」をクリックし、github Actionsを有効化

6. [KeymapEditor](https://nickcoutsos.github.io/keymap-editor/)にアクセス  
7. 「GitHub」を選択
  
8. 「Login with GitHub」からでログインし、「Authorize Keymap Editor」を選択  
9. 指示に従い、フォークしたzmk-config-roBaにKeymap Editorがアクセスできるように進める
10. Keymap Editor上でキーマップが表示されたら、好きにキーマップを編集する
11. 画面左上の「Save」を押すと、編集したキーマップが適用されてGitHub Actionsが走り、自動的にビルドが開始します

12. 「Save」の隣に表示される「Latest」をクリックするとGitHubに移動し、ビルドが完了するとファームウェアがダウンロードできるようになります。  
（ビルドには2～4分かかる場合があります。）
13. [書込み手順](#5-2ファームウェア仮の書込み)に従い、ファームウェアを書き込みます。  
    + キーマップの編集のみの場合はトラックボール側(セントラル)のみを書き換えることで変更が適用されます。  
    リセットファームウェアの書込みも基本的には必要ありません。
    + KeymapEditorを用いずにroBa.keymap以外のファイルの内容を書き換えた場合は、左右のファームウェアを書き換えてください。  
    + ファームウェアを書き直した際は、PC側のペアリング情報も削除してから再度ペアリングを行ってください。
14. 無事に変更したキーマップが適用されていれば成功です。

***※REMAPやVialには対応していません。***

## 7．トラブルシューティング

### bluetoothデバイスとして認識されない or 認識しても接続できない or 接続できたが片側が反応しない
+ [zmk firmware公式のトラブルシューティング](https://zmk.dev/docs/troubleshooting/connection-issues#split-keyboard-halves-unable-to-pair)にあるようにまずはsettings_reset-seeeduino_xiao_ble-zmk.uf2の書込みからやり直すことをお勧めします。  
+ （あまりないと思いますが）マイコン自体に問題がないか確認するため、キーボードに接続しない状態マイコン2個で認識、接続できるかも一応試してみてください。  
### トラックボールが動かない  
+ （あまりないと思いますが）ケースが正しく装着できておらずセンサの読み取り部分が隠れてしまっていないか確認してください。
+ トラックボール読み取り基板とセンサのはんだに不良がないか確認してください。  
  + はんだに失敗しやり直し不可の場合は、センサとトラックボール読み取り基板のみで保守部品としてboothで販売予定ですのでそちらをご利用ください。  
+ settings_reset-seeeduino_xiao_ble-zmk.uf2の書込みからやり直してみることが有効な場合があります。  

### 一部キーが反応しない  
+ はんだ不良、ポゴピンの接触不良、ダイオードの向き、キースイッチが正しくソケットに刺さっているかを確認してください。  

### zmk firmwareについて
このキーボード固有の問題ではなくファームウェアのカスタマイズ等で疑問点がある場合、以下が参考になると思います。  
+ [公式ドキュメント](https://zmk.dev/)
  + かなり丁寧に作りこまれているので基本的な設定はドキュメント見ればわかると思います。
+ [zmk firmware Discordサーバ](https://zmk.dev/community/discord/invite)  
  + 活発に動いているので質問すると誰かしら回答くれることが多いです。

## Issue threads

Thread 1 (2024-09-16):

PCBのデータについて

ko2kk, 2024-09-16:
Ki CadでPCBデータを正常に開くことができません。（フットプリントが反転しているものがあります。）プロジェクトのデータがあるディレクトリごとアップロードお願いします。
参考　[keyballの例](https://github.com/Yowkees/keyball/tree/main/keyball39/design_data)

kumamuk-git, 2024-09-16:
シンボルやフットプリントの追加、および各kicad_pcbファイルの修正を行いました。
別pcでリポジトリを落としてkicad_pcbファイルを開くことで問題なく見えているように思いますがいかがでしょうか。

ko2kk, 2024-09-16:
シンボルとフットプリントの反映を確認しました。対応ありがとうございました。
フットプリントのプロパティ/位置/面がすべて表面になっているため、裏面実装のソケットやダイオードが3D表示やPCBAができません。（レイヤは正しいためPCBのみの発注で手はんだであれば問題ないと思います。）

kumamuk-git, 2024-09-16:
センサ用基板以外はPCBAを前提としていないため、特に考慮していません。
PCBAサービスに発注の際は各自データを調整いただければと思います。

Closed 2024-09-16.

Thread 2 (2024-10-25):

親指部分はCherry MX互換のスイッチで動作可能でしょうか？

sekai013, 2024-10-25:
制作おつかれさまです。素晴らしいキーボードでぜひ購入したいと思っているのですが
ビルドガイドを読んでいてひとつ疑問に思ったので質問させてください。
ビルドガイドでは親指部分にはchoc用ソケットをはんだ付けするように書かれていますが
[写真](https://github.com/kumamuk-git/roBa/blob/main/doc/buildguide.md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)を見る限りはKeyballのようにCherry MX用のソケットもはんだ付けできるように見えます。
Cherry MX用のソケットを個人で用意してはんだ付けすれば親指部分もCherry MX互換スイッチで動作させられるのでしょうか？

kumamuk-git, 2024-10-25:
>親指部分もCherry MX互換スイッチで動作させられるのでしょうか？
→はい。keyballと同様Cherry MX互換ソケットを取り付け可能で動作します。
　ただ用意しているケースは親指部分を低くしているため、見た目上は合わないかもかもしれません。

sekai013, 2024-10-25:
素早いご回答ありがとうございます！

Closed 2024-10-25.

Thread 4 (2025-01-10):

ケース組み立て用ファスナー

ElectroZhuk, 2025-01-10:
こんにちは！あなたのプロジェクトを再現しようと計画しており、そのために現在、組み立て手順を詳しく勉強しています。しかし、手順にはケースの上部を底部に固定する方法が記載されていませんでした。どうすればいいか教えていただけますか？

ElectroZhuk, 2025-01-13:
@kumamuk-git 🙇🏻‍♂️

kumamuk-git, 2025-01-13:
https://github.com/kumamuk-git/roBa/blob/main/doc/v2/_old/buildguide_v2.md
こちら参照ください。
最新のビルドガイドに対応したケースのデータはまだgithubに公開していません。

ElectroZhuk, 2025-01-14:
ありがとう！

Closed 2025-01-14.

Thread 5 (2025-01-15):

PMW3610 用 PCB アセンブリ

ElectroZhuk, 2025-01-15:
こんにちは！ PMW3610 用に組み立て済みのボードを注文したのか、それとも自分で組み立てたのか教えてください。工場でボードを組み立てるのはコストがかかりすぎるため、抵抗器、安定器、コンデンサを自分でボードにはんだ付けできるかどうかを知りたいです。

kumamuk-git, 2025-01-16:
PCBAで発注して使用しています。JLCPCBではそれほどコストはかかりません。

ElectroZhuk, 2025-01-16:
どうもありがとう

Closed 2025-01-16.

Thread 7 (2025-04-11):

Is v2 PCB compatible with v3 case and build guide?

suleymanboyar, 2025-04-11:
Hi,

Is the v2 PCB compatible with the v3 case and build guide? Alternatively, are you planning to release an updated version of the PCB?

---

Translated to Japanese by Claude 3.7 Sonnet:

こんにちは、

v2 PCBはv3ケースとビルドガイドに互換性がありますか？あるいは、PCBの新しいバージョンをリリースする予定はありますか？

kumamuk-git, 2025-04-12:
https://github.com/kumamuk-git/roBa/blob/main/doc/v2/buildguide_v2.md
v2のビルドガイドはこちらです。
v2はv3ケースと互換性はありません。
v3のPCBを公開するかは未定です。

Closed 2025-04-12.

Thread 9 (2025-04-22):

バッテリーとトラックボールについて

yoyoyo0444, 2025-04-22:
ここでの質問で良いのかわかりませんがお聞きします。
左側のバッテリーソケット周りで半田失敗しているためバッテリーが使えない状況ですが、usbコネクタから電源を供給して動作確認しているところです。現状、Bluetoothでの接続とキースイッチは反応していますがトラックボールは動作していません。
ソケット周りとトラックボール(マイコンやセンサーの半田)は関連しているのでしょうか？機械的な分野は詳しくないのと、問題点の切り分けのためよろしくお願いします。

kumamuk-git, 2025-04-27:
どのように失敗しているのかにもよるかと思います
boothでの購入者の方であればdiscordでトラブルシューティング対応していますのでそちらでお願いできますでしょうか。

Closed 2025-04-27.

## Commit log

2024-08-16 Track large STL file with Git LFS
    [trackballcase.stl]
2024-08-16 add pcb data
    [pmw3610_breakout_for_roBa.kicad_pcb, pmw3610_breakout_for_roBa.kicad_sch, roba_L.kicad_pcb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]
2024-08-27 update pcb&ballcase, buildguide
    [EVQWGD001_extension.kicad_pcb, EVQWGD001_extension.kicad_sch, roba_L.kicad_pcb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]
2024-08-27 modified ballcase
    [trackballcase.stl]
2024-09-01 add old case
    [my_case_L.stl, my_case_L_bottom.stl, my_case_L_v5.stl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]
2024-09-09 fixed hole size for springpin
    [roba_L.kicad_pcb, roba_R.kicad_pcb]
2024-09-09 add case stl v1
    [power_sw.stl, reset_stick.stl, roba_case_bottom_L.stl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]
2024-09-09 fix powerswitch direction
    [roba_L.kicad_pcb]
2024-09-09 update sumplate
    [roba_case_top_sum_L.stl, roba_case_top_sum_R.stl]
2024-09-15 ポゴピンについて追記
2024-09-15 cpiについて追記
2024-09-16 add fp and symbol
    [EVQWGD001_extension.kicad_pcb, EVQWGD001_extension.kicad_sch, pmw3610_breakout_for_roBa.kicad_pcb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]
2024-09-23 note switch direction
2024-10-08 add v2
    [roba_L.kicad_pcb, roba_L.kicad_sch, roba_R.kicad_pcb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]
2024-10-08 modify v2
    [roba_L.kicad_pcb, roba_R.kicad_pcb]
2024-10-29 update buildguide
    [bottom_L_v2.stl, bottom_R_v2.stl, main_R_v2.stl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]
2024-10-31 コンスルーについて
2024-11-24 about JST connector
2024-12-01 macでの書込みエラーについて追記
2024-12-01 追記修正
2025-01-16 add case(v2.1)
    [bottom_R.stp, botttom_L.stp, power_sw.stp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]
2025-02-26 トラックボール動作のキー割り当てに関する追記
    [top_R.stp, top_R_test.stp]
2025-03-21 add v3
    [bottom_L.stp, bottom_R.stp, power_sw.stp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]
2025-04-06 add LP case
    [reset_stick.stp, reset_stick_LP.stp, top_L_LP.stp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]
2025-04-08 add reset_stick_LP_JLC3DP
    [reset_stick_LP_JLC3DP.stp]
2025-04-08 modify top_R_LP
    [top_R_LP.stp]
2025-04-09 modify bottom_L.stp
    [bottom_L.stp]
2025-04-09 add power_sw_JLC3DP
    [power_sw_JLC3DP.stp]
2025-04-15 add troubleshooting info about charging
2025-06-29 #PR36に伴う記載変更及び微修正
2025-09-22 ケース所在の明確化
2025-09-22 JLC発注向けトラックボールケース
    [trackballcase_JLC3DP.stl]
2026-02-10 フットプリントの追加
2026-02-10 お恥ずかしい誤字の修正
2026-03-24 ケース印刷しやすさ向上
    [power_sw_fix.stp, top_L_frame.stp, top_L_plate.stp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]
2026-04-01 はんだ付け練習基板の追記
